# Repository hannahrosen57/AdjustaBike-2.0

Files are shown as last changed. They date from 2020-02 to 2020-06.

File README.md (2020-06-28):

# Design of an Open Source, Low Cost, DIY Cycle Kit
This project was undertaken to investigate the feasibility of an open source, low cost, DIY cycle kit, as my Final Year Project at the University of Bath. As part of the project brief, the kit was designed using off-the-shelf components instead of custom parts wherever possible, to ensure that it can be easily manufactured by the lay person with simple tools and materials. I have succeeded in developing and testing a design for a bicycle frame constructed from handrail clamps, and documented the design so that anyone can continue the work or build a prototype. The design can be customised by the user, and sample geometries were included in the assembly drawings. FEA was used to analyse the bicycle frame, and the design was optimised in response to the results. The final design weighs approximately 8.4kg and costs approximately £276 for the frame components. 

Further work could include building and testing prototypes (which was sadly not possible before the project deadline due to the COVID-19 pandemic), further FEA analysis, espescially focusing on the bottom bracket clamp in dynamic loads, and designing other geometries using the same components such as a cargo bike or recumbent tricycle.

You are free to copy, distribute, and make changes to these designs, under the condition that you give credit to Hannah Rosen, link back here, and publish any new documentation in line with [Open Source Hardware principles](https://www.oshwa.org/definition/). If you build a prototype or further develop the designs, please also consider sending me pictures and telling me how you got on! You can contact me at diycycle57@gmail.com, or open an issue in this repository. Thanks.

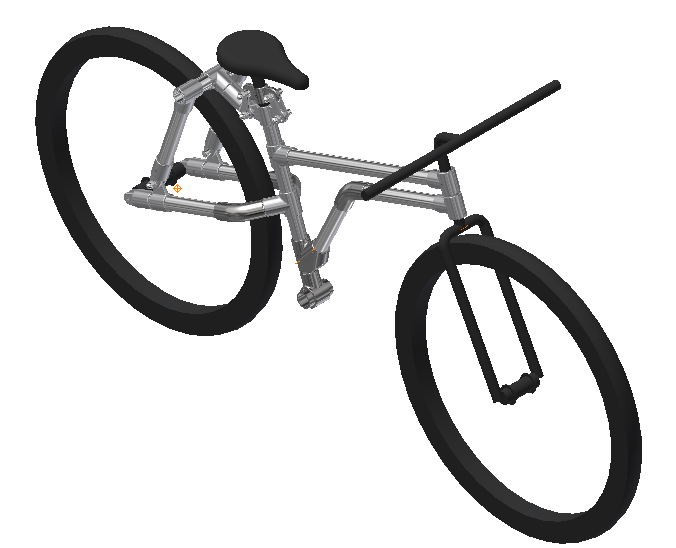
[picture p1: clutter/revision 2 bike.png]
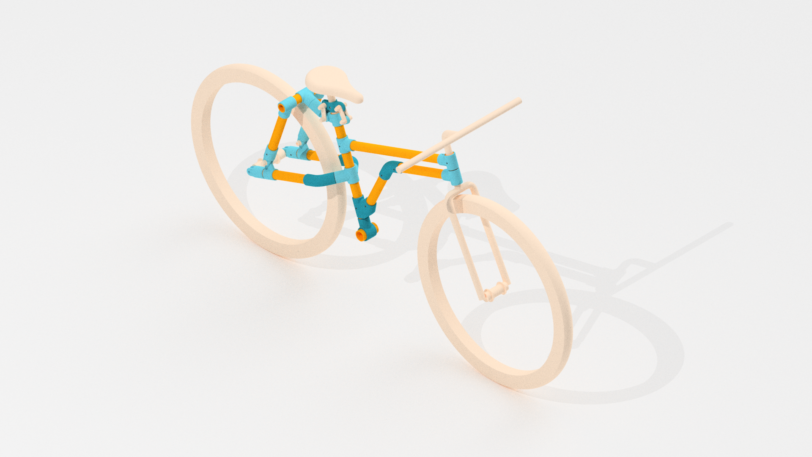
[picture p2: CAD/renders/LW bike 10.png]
|||
|---|---|
|Quick Links:
|- [Poster](https://github.com/hannahrosen57/AdjustaBike-2.0/blob/master/clutter/poster.pdf) (or scroll down↓)|- [Final Presentation](https://github.com/hannahrosen57/AdjustaBike-2.0/blob/master/clutter/Presentation2.pdf)
|- [Preliminary Presentation](https://github.com/hannahrosen57/AdjustaBike-2.0/blob/master/clutter/Presentation1.pdf)|- [Final Report](https://github.com/hannahrosen57/AdjustaBike-2.0/blob/master/report/final%20report.pdf)
|- [STL Files and 3D PDFs of Assemblies](https://github.com/hannahrosen57/AdjustaBike-2.0/tree/master/CAD/exportedCAD)|- [Seatpost Link Part Drawing](https://github.com/hannahrosen57/AdjustaBike-2.0/blob/master/CAD/LINK%205.pdf)
|- [Revision 1 Bike Frame Assembly Drawing](https://github.com/hannahrosen57/AdjustaBike-2.0/blob/master/CAD/bike.pdf)|- [Revision 2 Bike Frame Assembly Drawing](https://github.com/hannahrosen57/AdjustaBike-2.0/blob/master/CAD/LW%20bike%2010.pdf)
|- [Revision 1 Bike Frame Bill of Materials (with weblinks)](https://github.com/hannahrosen57/AdjustaBike-2.0/blob/master/report/bike%20parts%20list.pdf)|- [Revision 2 Bike Frame Bill of Materials (with weblinks)](https://github.com/hannahrosen57/AdjustaBike-2.0/blob/master/report/lw%20parts%20list%20web%20links.pdf)
|- [Kee Klamp Catalogue](https://github.com/hannahrosen57/AdjustaBike-2.0/blob/master/clutter/possible%20components/Kee/Kee_Klamp_components_and_new_slope_fittings.pdf)|- [Kee Lite Catalogue](https://github.com/hannahrosen57/AdjustaBike-2.0/blob/master/clutter/possible%20components/Kee/ks_Kee-Lite_KSys.pdf)

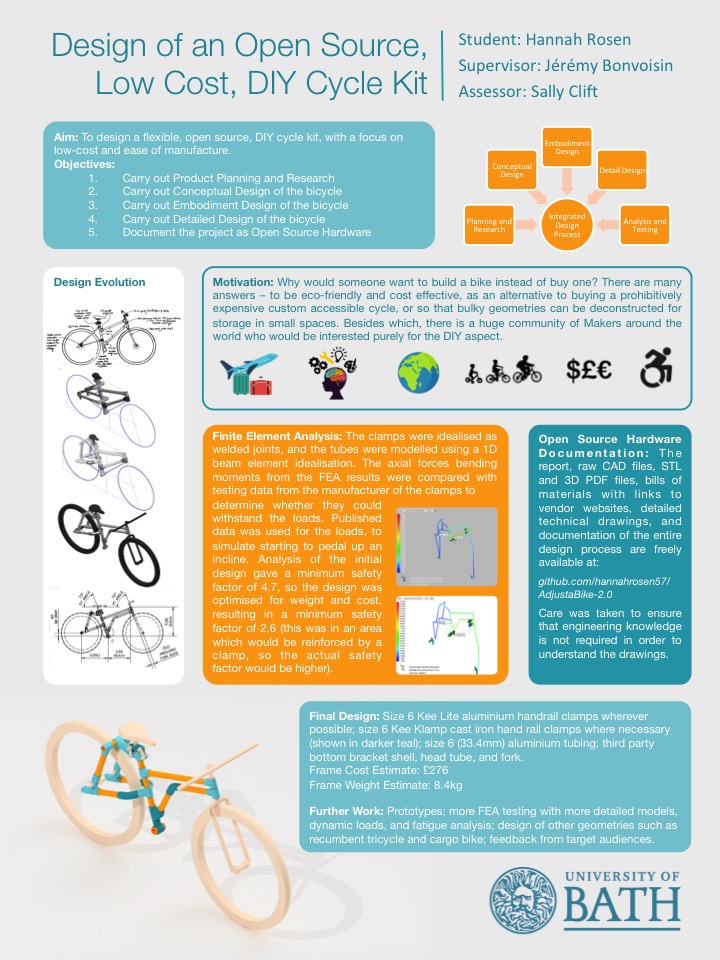
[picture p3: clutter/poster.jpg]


### Notes 22/05/2020:
1. If the reader wishes to build a prototype, and "cheap" is higher up on their list of priorities than "lightweight," some or all of the aluminium clamps could be replaced with cast iron clamps.
    1. The cast iron Kee Klamps use the same part number as the equivalent aluminium Kee Lite clamps, without the "L" prefix. For example, 10-6 is equivalent to L10-6.
    1. Other, cheaper, brands are available, but care should be taken to ensure they are rated to the same loading conditions. A brand comparison and part number conversion table can be found in the report (linked above).
1. Most tube vendors will cut the tubes to length for free (including the ones linked to in the Bills of Materials), which will save time and also shipping costs. However, there is limited data on how far into the clamps the tubes are inserted, so leave a margin for adjustment on the listed tube lengths when cutting. 10 to 20mm should be adequate.
1. Note that a commuter bike geometry is shown as a starting point, but the reader is encouraged to adapt the design to suit their requirements, such as designing a tandem or quad-cycle. Sample geometries for different sizes of the commuter bike geometry (with tube lengths) are shown on the Rev 2 assembly drawing.
    1. An idea for further work is to write a piece of code which would allow users to customise geometry and see a diagram and automatically generated tube lengths without the use of Inventor or any other complex, expensive CAD software - similar to [this webapp](https://www.bikegeocalc.com/) by Anders Torger.
1. Note that this is ready for anyone to take these designs and build a prototype, but more testing needs to be done before it can be certified 100% bombproof. Proceed with caution.
     1. In particular, attention should be paid to the behaviour of the bottom bracket clamp under dynamic loads, and after many load          cycles (including bending moments about all three axes of rotation). Of particular concern is whether the grub screw will loosen over time (it is advised to use a thread locker and check periodically with a torque wrench) and whether the tubes will become damaged over time where the grub screws bite into them. The best way to test this might be to build a bike and ride it around for a while.
     1. If after further testing it is found that the bottom bracket clamp cannot withsand the cyclic loads, Rose+Krieger clamp *Block Form WR 42* (code no: 214200030266) could be used instead of the single socket tee (kee 10-67). This is more suited to dynamic loads, but would add weight and cost.
     1. Alternatively, the geometry could be redesigned so that the down tube is also supporting the bottom bracket,
        1. This could be done using a 90 degree side outlet tee (kee 21-7) and an elbow (such as kee 55), similar to the chainstays in the current design. 
        1. The variable side-outlet tee (kee 19) is another option which should be investigated, but note that the testing data for the aluminium Kee Lite clamps states that type L19 is "not suitable to absorb bending load, bending moments are not allowed". The cast iron Kee Klamp testing data however rates type 19 to 1.25kN of bending load resistance. 
        1. More information on bending moment resistance should be sought from Kee Systems if type L19 is used. Testing should also be done to determine whether the asymmetry and short gripping of types 19 and L19 would cause problems when supporting the diagonal loads on the bottom bracket.
        1. The downtube would then need to be connected to the head tube with either an angle tee (such as kee L29-7) or an elbow (such as kee 55) and a single socket tee (such as kee L10-7).
    1. Both of these options would mean that the seat tube needs to be the same size as the bottom bracket. Unless a bottom bracket shell can be found or made (simple enough if one has access to a lathe, or is willing to contract a third party to machine it for them) which fits a Size 6 Kee Klamp (possibly with the use of a shim), this would mean that size 7 tubing would need to be used for most of the frame, as in Revision 1 of the current design (assembly drawing and BOM linked above). This would add cost and weight, but is still feasible.
1. The only custom part (apart from cutting tubes to length) is the seat post link. It can be made easily from flat bar with just a hacksaw, a drill, and a file. The part drawing is linked above and should be easy to understand even for people with no engineering knowledge. 
    1. The clamps are all standard; simplified CAD models were created from the dimensions given by the manufacturer in order to model the assembly. Part numbers and vendor links are given in the bills of materials. The catalogues are linked above.
1. If the prototype is built and there is a problem with rattling, simple rubber washers/gaskets should be used in the swivel sockets. 
    1. This could also help if the surface of the swivel sockets used as "drop outs" (technically, frame ends) does not have a good enough surface finish. Just pop a rubber washer between the frame end and the axle nut.
    1. The number of washers used as spacers depends on the thickness of the washers, especially in the seat post clamp/seatstay assembly. Adjust as appropriate.
1. If there is a problem with the seat post rattling, use a spacer to fill the gap between the seat post and the seat tube. PVC pipe, shim stock, or folded aluminium foil could be used. To stop it from slipping down the seat tube, drill a horizontal hole through the bottom of the seatpost below the spacer (through both sides of the tube), and insert a length of threaded bar. Secure it in place with two nuts on the threaded bar inside the seat post, tightened to brace outwards against the ID of the seatpost. Make sure it protrudes far enough to hold the spacer in place, but not far enough to scratch against the ID of the seat tube.
1. A placeholder for the drivetrain was not modelled, because the user can choose to use any number of options - fixed gear, hub gears, cassette gears, or even a belt drive. In the case of fixed gears, chain tensioning would be facilitated by adjusting the sliding clamps. However, regardless of one's preferred drivetrain, it would be advisable to model a simple placeholder and check there is enough clearance, making small adjustments to tube lengths if necessary, before ordering parts.

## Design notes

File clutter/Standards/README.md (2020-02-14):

The standards are as follows:

code              | title
------------------|---------------------
ISO 4210          | Cycles — Safety requirements for bicycles
BS EN 14764       | City and trekking bicycles — Safety requirements and test methods *(note: this is outdated and was replaced by ISO 4210, but still helpful)*
ISO 8098          | Cycles — Safety requirements for bicycles for young children
ISO 9633          | Cycle chains — Characteristics and test methods

The former is the most relevant. I couldn't find the requirements for some of the tests, so I went looking and found the numbers I wanted in the second and third standard, but then realised they were hiding (in plain sight) in part 2 of ISO 4210 all along. I'll leave them here anyway since I already went and found them. The fourth was refenced by ISO 4210.

For reference, these are the parts of ISO 4210:

- Part 1: Terms and definitions
- Part 2: Requirements for city and trekking, young adult, mountain and racing bicycles
- Part 3: Common test methods
- Part 4: Braking test methods
- Part 5: Steering test methods
- Part 6: Frame and fork test methods
- Part 7: Wheels and rim test methods
- Part 8: Pedals and drive system test methods
- Part 9: Saddles and seat-post test methods

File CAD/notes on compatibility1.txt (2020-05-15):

NOTES ON COMPATIBILITY:
Components below can be taken from a cheap second-hand donor bike or purchased seperately. Use shims if necessary, leaving a gap for the clamp's grub screw.
Bottom Bracket: 73mm English Thread
Fork: 1" ISO standard fork steerer. Ø41mm HT for a 11/8" fork also available, but needs size 7 clamps.
Seatpost: 26-27.5mm OD for Size 5 clamp (M51-5, shown here) or 21-22.5mm OD for Size 4 clamp (M50-4).
Wheels: 29" rims with 44mm tyres and 135mm rear hub spacing shown for reference. For bigger wheels (or longer wheelbase) - use longer CS, SS, CSS, and/or SSS tubes. For smaller wheels - use shorter CS and SS tubes, and/or longer axle spacers (CSS shown at minimum).
Brakes: Front - any compatible brake. Rear - use coaster brake or create attachment point for callipers with additional clamps.
Gears: Single speed or hub gears are the simplest butnot the only options. Consider the weight of the entire bike when selecting gear ratio(s).

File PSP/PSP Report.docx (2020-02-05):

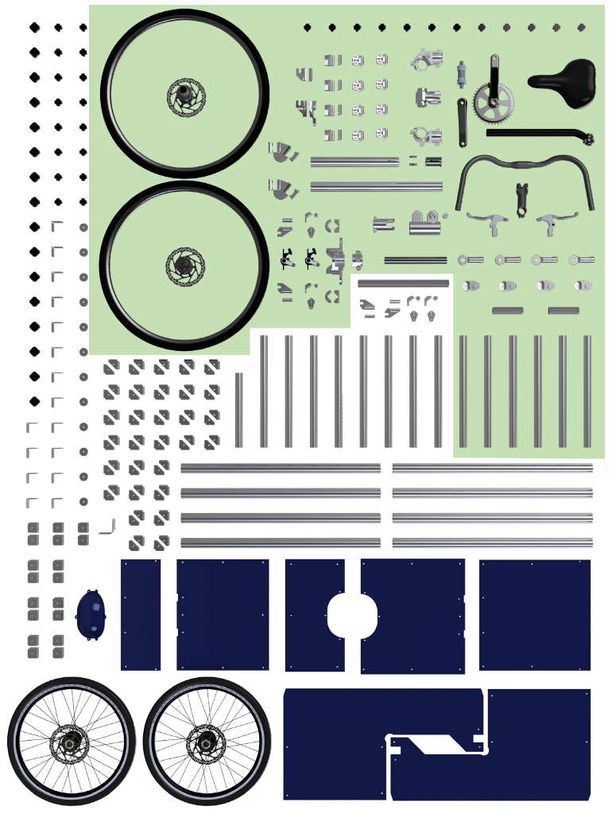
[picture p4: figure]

design of a DIY Bicycle Kit Project Scoping and Planning Report | SUMMARY [Draw your reader in with an engaging abstract. It is typically a short summary of the document. When you’re ready to add your content, just click here and start typing.] Hannah Rosen Supervisor: Jeremy Bonvoisin Assessor: ………………………….

# Background

This project is building on the work which was carried out in the Adjustabike project in 2019 by a previous student, which was the latest iteration of a series of prototypes developed to explore the concept of an open source build your own bicycle kit. The benefits to a bicycle kit over a traditional frame are that the same components can be re-used when the frame needs to accommodate a different rider, or to construct an entirely different geometry which may not be readily available (which is especially useful if the geometry is only needed temporarily), and that bulky geometries can be deconstructed when not in use to save storage space, and the components repurposed.

The Adjustabike frame consists of aluminium profiles from a factory equipment construction system such as item, fastened together by flexible joints through non-destructive clamping mechanisms. Two geometries were modelled: a standard bicycle which was adjustable for rider height, and a cargo tricycle. In theory many other geometries could be assembled from the same components, but this was left for future development, as was in-depth testing.

Although the Adjustabike provided a thorough proof of concept, it made several compromises on the use of readily available standard parts. The complex custom components which were developed could not be manufactured even with sophisticated CNC machines at one’s disposal, let alone by a typical layperson. It was also fairly limited in its documentation, which meant that adaptation by a third party might prove difficult, and that the open source aspect of the concept was not fulfilled to the extent intended. The aim of this project is to readdress the concept with a view to making the kit as open source and accessible to laypeople as possible. To achieve this, the ratio of off-the-shelf to custom components will be increased as much as possible without compromising the functionality and flexibility of the previous design. Ideally, the kit will be comprised of exclusively standard components. An effort will also be made to document the project according to Open Source Hardware best practices.

# Aims and Objectives

The aim of this project is to design a kit with which a lay-person can easily and non-destructively assemble a bicycle with a geometry of their choice, and to ensure that the ratio of off-the-shelf components to custom components is as high as possible, in the interest of maximising the accessibility of the kit to the lay-person. This aim will be accomplished through the following objectives:

1. Investigate available off-the-shelf technologies and use a set of criteria to recommend which would be most suitable for using in the kit.
2. Develop a simplified modelling method to test the combinations of the recommended elements, and use it to:
  a. Demonstrate the feasibility of creating different geometries, and
  b. Make a recommendation on which lengths, angles, and quantities of components which should be included in the ‘starter’ kit (with the understanding that supplementary components may be used for specialised geometries).
3. Source materials and build a physical (preferably full scale) prototype of one or more geometries.
4. Establish open source documentation, both to allow lay people to use the kit and to allow future development of the project.

# Work Plan (Programme and Methodology)

The project will be divided into four Work Packages (WPs), corresponding to the four objectives. WPs 1, 2, and 3 will be carried out in series and are dependent on each other, so contingency planning will be carried out such that the project content will not be compromised due to unexpected results. WP4 will mostly be completed throughout the project in parallel to the other WPs, bookended with some preparation at the start and finalisation at the end of the project.

## WP1 Study of Available Technologies

An investigation will be conducted into available off-the-shelf products which could be used to create the bicycle kit. It should be noted it will most likely not be immediately obvious where to look, because the products of interest will likely be intended for completely different purposes, such as scaffolding. A set of criteria should be developed, such as a high strength to weight ratio, non-destructive joint locking mechanisms which do not require extensive tooling, and low cost. Each of the available products will be rated based on these criteria, and a recommendation will be made on which to take forward.

## WP2 Combinatorial Testing

Using a CAD package such as Autodesk Inventor, simplified models of a preliminary set of components from the recommended technology will created based on the characteristics of the existing products obtained from product specifications. The components will be based on the existing products, but may be modified in ways that can easily be achieved with simple tools, such as cutting profiles to length. Different geometries will then be modelled using assemblies of different combinations of these components. The parameters of the components (such as lengths of tubes or angles of joints) may then be adjusted as needed (again, provided the equivalent modifications of the physical components are possible with simple tools), and the next iteration of geometry designs can then be developed using the new set of components. This can be repeated as many times as needed.

The resulting geometries will be analysed to ensure they are fit for purpose, including force calculations and perhaps some rudimentary FEM analysis, as well as safety, usability, and manufacturing and assembly considerations. Based on these geometries, a ‘starter kit’ of components will be recommended, with the understanding that supplementary components may be used for specialised geometries. The characteristics and quantities of each component in the kit will be specified.

## WP3 Physical Prototyping

If time allows, simplified small-scale prototypes of the recommended kit components will be created using additive manufacture so as to demonstrate the proof of concept for a few of the geometries developed in the previous WP, as it is unlikely that it will be possible to find the time or material resources to create full-scale prototypes of all of the different geometries.

However, the priority during this WP is to build a (preferably full scale) physical prototype of at least one of the geometries that were developed, ensuring that as many as possible of the components used are the exact components recommended in the kit. The purpose of this is two-fold: firstly, to demonstrate the soundness of the design of the components and the geometry, and secondly, to demonstrate the feasibility of sourcing the components and assembling the design using only the resources available to a typical lay-person.

It should be noted however, that difficulty is anticipated in the sourcing of certain components – namely, the interfaces between standard bicycle components such as the bottom bracket with the repurposed off-the-shelf components – due to tolerance discrepancies and other obstacles. The scope of this project is to demonstrate the feasibility of the overall concept, not to develop precise designs for any custom parts which might be necessary (although the aim is of course to avoid custom parts where possible). As such, rapid prototyping using extruded ABS additive manufacture (or other cost- and time-efficient methods) may be implemented where necessary to manufacture ‘placeholder’ components which may be developed further at a later stage, so that the larger assembly may be prototyped more effectively.

If time permits and the prototype is suitable, simple strain gauges may be used to test if the stresses in the components are as predicted.

## WP4 Open Source Documentation

The aim of documenting open source hardware is to ensure that other people have enough information to make, study, develop, and distribute the product. To this end, GitHub will be used throughout the project to keep a log in which to record decisions, test results, and design iterations. Whether this will be carried out using GitHub’s inbuilt Markdown capability or by simply uploading and committing a new version of a Microsoft Word document periodically will be determined based on which method is more efficient overall, taking into account the fact that the project log will serve two purposes: the report for the University project and the open source documentation.

In addition to the project log, the version control functionality of GitHub will be used to track changes in any CAD files by uploading and committing an editable format of the designs as they are being developed. Final designs will be made available on GitHub both in a raw, editable format such as .ipt, .iam, or .dwg files and a flattened, easily viewable format such as .stl or .pdf files. A set of instructions for the lay-person on the use of the kit will also be written, based on best practice.

This WP will be mostly carried out parallel to the other WPs, including tracking progress, recording test results, and documenting the prototype assembly photographically to provide images for the instruction booklet. However, some time will be needed at the beginning of the project to setup the GitHub repository, research best practice for documentation, and learn the Markdown formatting language. Some time will also be needed at the end of the project to compile the documentation and finalise any front-facing formatting, explanations, and graphics.

## Contingency Planning

Lorem ipsum

# Predicted Timescale

Note that these dates are preliminary and will likely change as the project progresses.

start date: | task:
27/11/2019 | Assessment 1: Project Scoping and Planning
| WP1
27/11/2019 | Research the different types of bike components
02/12/2019 | Create a set of weighted criteria for choosing the base technology for the frame kit
07/12/2019 | Look for available technologies online
26/01/2020 | Look for available technologies in brick and mortar shops
29/01/2020 | Score each technology based on the weighted criteria chosen earlier
30/01/2020 | Choose products that work well together from the top scoring options
| WP2
03/02/2020 | Create simplified CAD models of recommended components
03/02/2020 | Develop and refine concepts for one or two initial geometries
06/02/2020 | Put together a kit with preliminary angles, lengths, and quantities of components based on concepts
07/02/2020 | Create initial and alternative geometries from the kit and assess if they are fit for purpose
10/02/2020 | Adjust lengths, angles, and quantities of components in the kit
12/02/2020 | Repeat until geometries are optimised
19/02/2020 | Analyse final geometries eg. Force calculations
26/02/2020 | Decide which components should be in the starter kit and which should be add-ons
| WP3
15/02/2020 | Source materials eg tubes
27/02/2020 | Cut profiles to length etc.
27/02/2020 | Fabricate any custom parts needed
15/02/2020 | Source bicycle components eg gears
03/03/2020 | Assessment 2: Preliminary Project Presentations
05/03/2020 | Assemble the bicycle
12/03/2019 | Conduct testing, ie strain gauges, feedback from target market
| WP4
27/11/2019 | Set up GitHub repository
| Learn MarkDown syntax
| Track progress throughout project
| Write instructions on the use of the kit, based on best practice
| Compile and finalise documantation
| Report
28/03/2020 | Compile design logs, test reports, etc.
| Reflect on how the project could be developed in the future
| Plan structure of report
| List and gather all figures needed
| Create report skeleton
| Draft each section
| Revise drafts
| Work on formatting and graphics
| Create bibliography from references (which should be collected throughout)
29/04/2020 | Assessment 3: Final Project Report
11/05/2020 | Assessment 5: Viva, Final Presentation and Poster
25/05/2020 | Exhibition, External Viva

## Gantt Chart

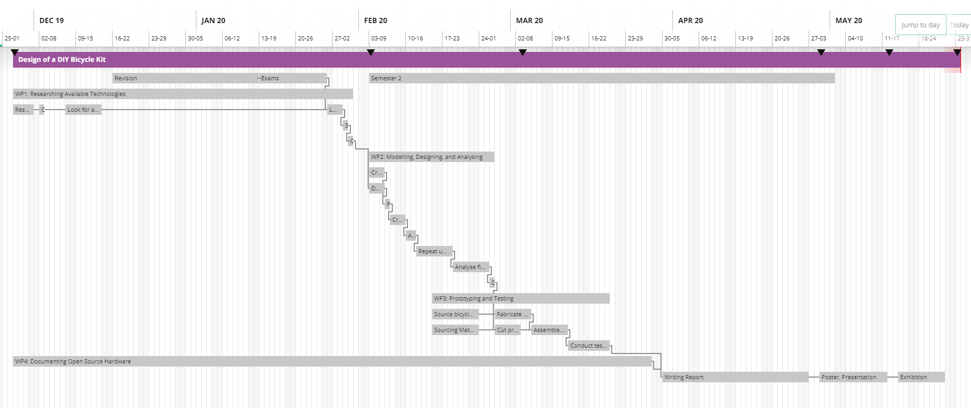
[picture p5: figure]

# References

http://vis.berkeley.edu/papers/assySiggraph/assembly.pdf

https://www.icebike.org/build-your-own-bike/

https://www.bikeradar.com/advice/buyers-guides/the-complete-guide-to-bottom-bracket-standards/

https://ukcyclerules.wordpress.com/2011/05/04/the-rules-of-bike-brakes/

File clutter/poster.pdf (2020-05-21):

Design of an Open Source,

# Low Cost, DIY Cycle Kit

## Student: Hannah Rosen Supervisor: Jérémy Bonvoisin Assessor: Sally Clift

Integrated
Design
Process

Planning and
Research

Conceptual
Design

Embodiment
Design

Detail Design

Analysis and
Testing

Aim: To design a flexible, open source, DIY cycle kit, with a focus on low-cost and ease of manufacture.
Objectives:
1. Carry out Product Planning and Research
2. Carry out Conceptual Design of the bicycle
3. Carry out Embodiment Design of the bicycle
4. Carry out Detailed Design of the bicycle
5. Document the project as Open Source Hardware
Design Evolution | Motivation: Why would someone want to build a bike instead of buy one? There are many answers – to be eco-friendly and cost effective, as an alternative to buying a prohibitively expensive custom accessible cycle, or so that bulky geometries can be deconstructed for storage in small spaces. Besides which, there is a huge community of Makers around the world who would be interested purely for the DIY aspect.

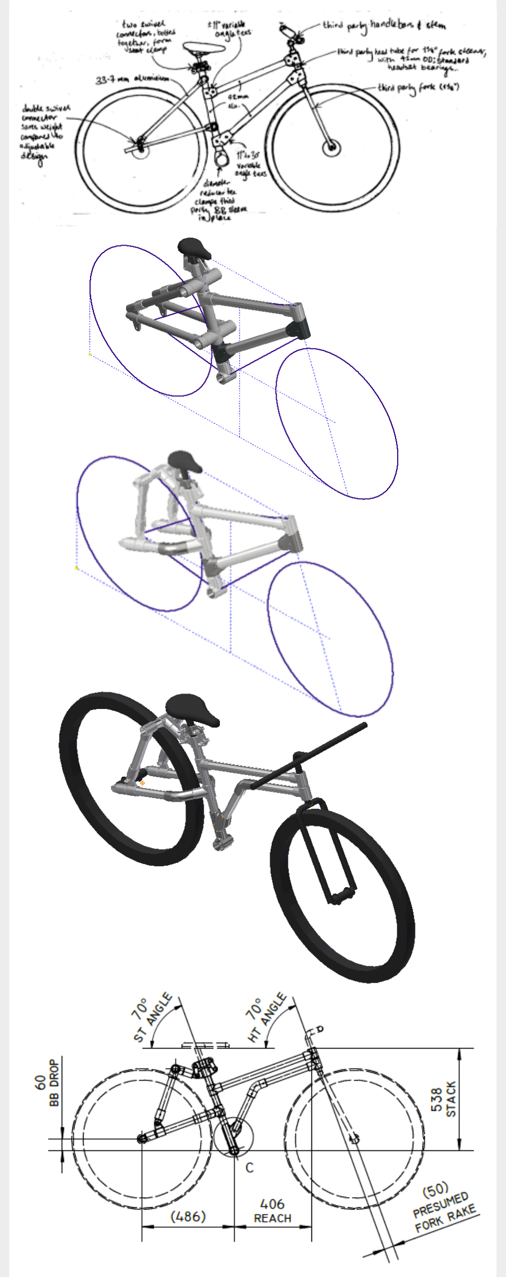
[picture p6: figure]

Open Source Hardware
Documentation: T h e
report, raw CAD files, STL and 3D PDF files, bills of materials with links to
vendor websites, detailed
technical drawings, and
documentation of the entire design process are freely
available at:
github.com/hannahrosen57/
AdjustaBike-2.0
Care was taken to ensure
that engineering knowledge is not required in order to understand the drawings.

Finite Element Analysis: The clamps were idealised as welded joints, and the tubes were modelled using a 1D beam element idealisation. The axial forces bending moments from the FEA results were compared with testing data from the manufacturer of the clamps to determine whether they could
withstand the loads. Published
data was used for the loads, to
simulate starting to pedal up an incline. Analysis of the initial design gave a minimum safety factor of 4.7, so the design was optimised for weight and cost, resulting in a minimum safety factor of 2.6 (this was in an area which would be reinforced by a clamp, so the actual safety factor would be higher).

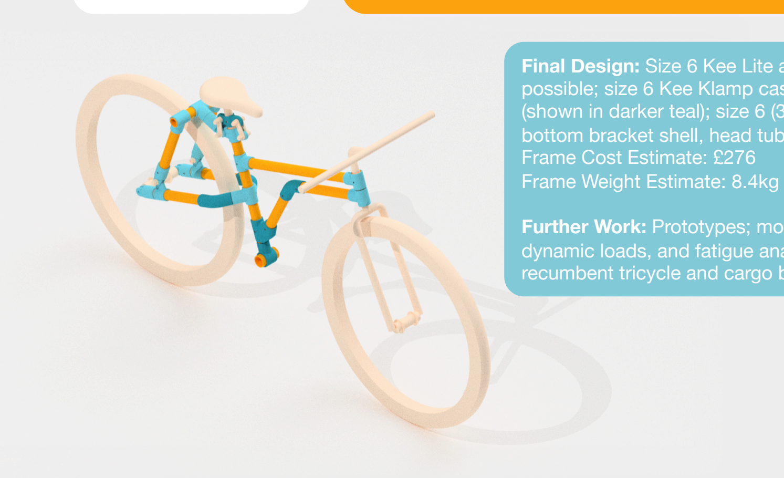
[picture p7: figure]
Frame Cost Estimate: £276 Frame Weight Estimate: 8.4kg

Final Design: Size 6 Kee Lite aluminium handrail clamps wherever possible; size 6 Kee Klamp cast iron hand rail clamps where necessary (shown in darker teal); size 6 (33.4mm) aluminium tubing; third party bottom bracket shell, head tube, and fork.

Further Work: Prototypes; more FEA testing with more detailed models, dynamic loads, and fatigue analysis; design of other geometries such as recumbent tricycle and cargo bike; feedback from target audiences.

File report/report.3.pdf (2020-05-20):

Concept Development
Development sketches for individual features can be seen in Figure 39 through Figure 42. Concept development sketches can be seen in Figure 43 and Figure 44. The main difference between Kee Klamp 1.0 and Kee Klamp 2.0 is that the latter uses a mixture of steel and aluminium tubes, and of cast iron and cast aluminium clamps, in order to combine the strengths and avoid the weaknesses of the Kee Lite and Kee Klamp concepts. Thereafter, the concept is developed with a view to find a viable solution which is fully adjustable. This was accomplished in concept 2.4, and the design was then streamlined to form concept 2.5. Note in particular the evolution of the geometry and the head tube/headset bearings as the concepts are developed.

Concept 2.4 and 2.5 were both selected as final concepts, as it was decided that the adjustability added so much complexity, weight, and cost to the design that it was worth developing one “Design for Adjustability” concept and one “Design for Performance” concept. These two concepts were evaluated against the same criteria as the initial concepts, and outperformed them all, as expected.

## Embodiment Design

Final Concepts/Initial Layouts

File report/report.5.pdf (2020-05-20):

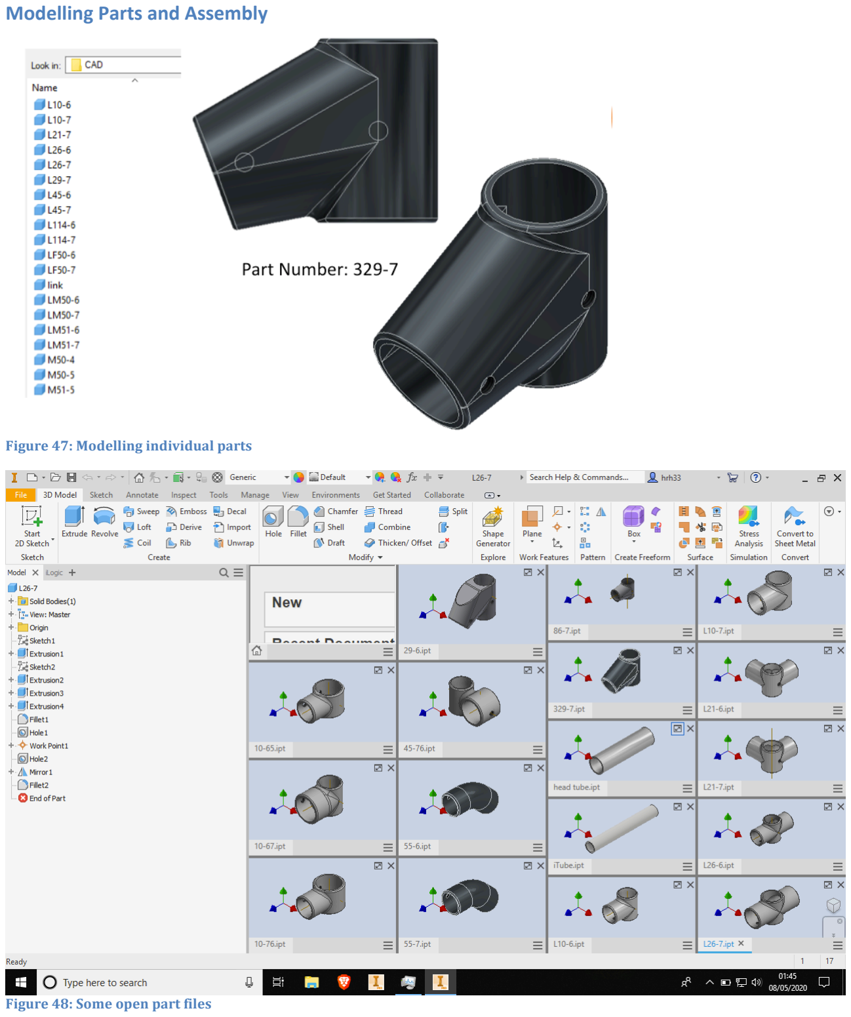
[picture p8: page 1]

Modelling Parts and Assembly

Figure 47: Modelling individual parts

Figure 48: Some open part files

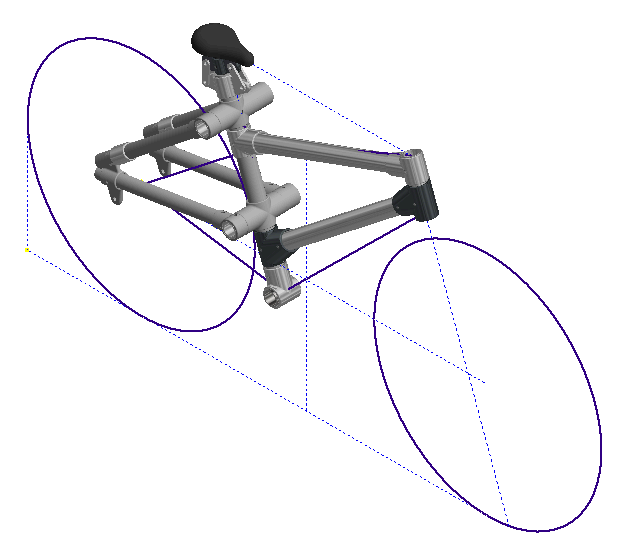
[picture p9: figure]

Figure 49: modelling assembly

## Detail Design

Geometry Adjustment Tuning
When the design was initially modelled up, it became clear that the chainstay spacers and seatstay spacers would get in the way of the user’s legs and make pedalling impossible. The bike was redesigned to be more ergonomic.

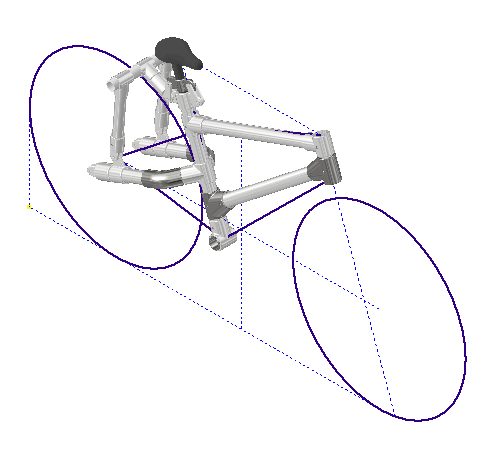
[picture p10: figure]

Figure 50: New, more ergonomic rear triangle design
iLogic was also used to automate the tubes to adjust their length according to a stack and reach value that was entered as a parameter. This was used to create a table with sample geometries and tube lengths for different riders on the assembly drawing (see Appendix VI: Drawings and BOMS).

Finite Element Analysis
FEA analysis was used to analyse, validate, and optimise the design. This is an entire field of study but I am short on time so I will try to illustrate the process I took as quickly as possible. Please note I am running out of time to write up all the analysis I did!

simplifying geometry:

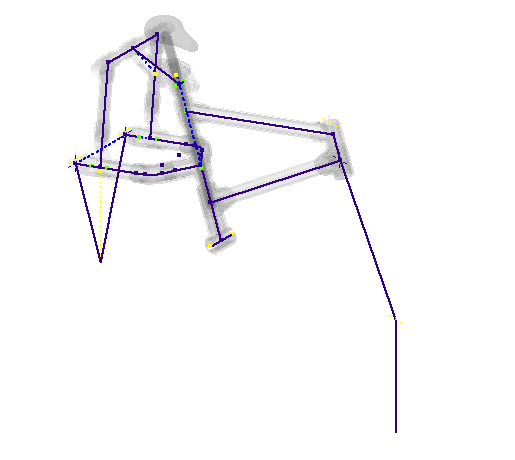
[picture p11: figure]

geometry was represented with sketch lines. bike was modelled as if welded, neglecting the clamps, as this was the ‘worst case scenario’ since the clamps have a higher bending moment resistance than the tubes. The forces and bending moments were calculated as well as the stresses and compared with clamp test data from the manufacturer.
Defining Parameters:
- mesh
- element types and cross sections
- beam elements were used exclusively.
- ideally these would only be used when the cross section is less that 1/10 of the length. This condition was true for most of the tubes, but not the bottom bracket
- this idealisation should still be accurate enough to give a good idea
- a topic of further work could be analysing the product in more detail
- initially different cross sections were used according to the different tube cross sections, but it didn’t mesh correctly when using the end release function. So, the cross section was first set as the size 6 tube, and the results for the rear triangle were evaluated. Then the cross section was set to that of size 7 tube and the rest of the results were evaluated.
- element size
- a mesh convergence study was performed and 5mm elements were found to be the best balance between speed and accuracy
- end-release

- end release was used at the rear frame ends and the swivels in the rear triangle to simulate realistic constraints without over complicating the mesh
- constraints
- the wheels were modelled as lines to allow the bike to tilt with the bending moment on the handlebars to a certain extent, to reduce unrealistic stresses
- other than this, the bike was simply supported
- loads
- loads were taken from the 1986 paper (7) from the ‘starting tilted’ load case
- as the handlebars and pedals were not modelled, unsymmetrical loads were modelled with distributed moments on the BB and head tube.

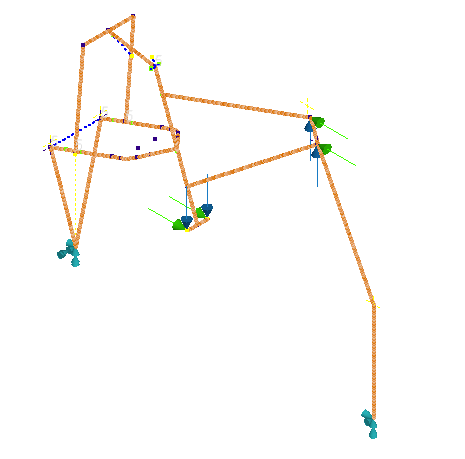
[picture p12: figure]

Figure 51: showing the mesh, constraints, and loads

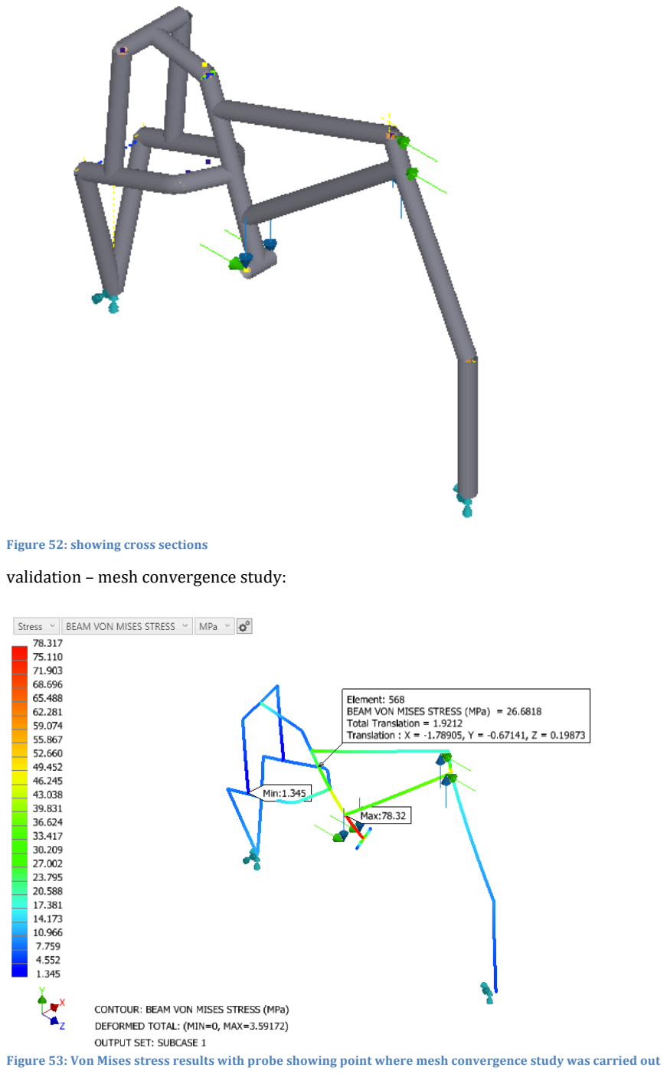
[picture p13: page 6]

Figure 52: showing cross sections
validation – mesh convergence study:

Figure 53: Von Mises stress results with probe showing point where mesh convergence study was carried out

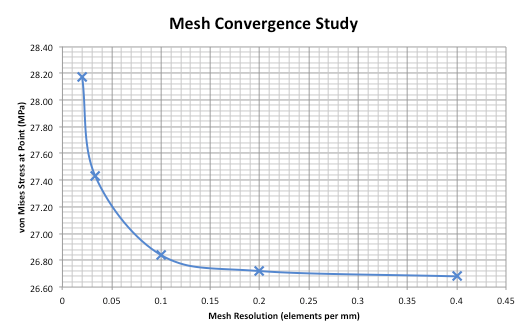
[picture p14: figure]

Figure 54: Mesh convergence study
Results
The results of the analysis were encouraging. The maximum von mises stress was well within the safe limit of the tubes. The minimum safety factor was 4.71, and that may have been caused by a singularity (see Figure 57: closeup safety factor results plot screenshot). The axial forces and bending moments were also well within the safe limit for the clamps (see Figure 59, Figure 60, Figure 62, and Appendix IV: Kee Systems Testing Data; note that units in screenshots are in Nmm and units in testing data are in kNm; also note safety factor included in testing data). In view of this, the design was optimised to be lighter and cheaper (see Optimising Design and Appendix VI: Drawings and BOMS) and the FEA analysis was carried out again. The results again confirmed that the loads and stresses were within safe limits (see Figure 63 through Figure 67). The minimum safety factor was the 2.6, which is not ideal, but a) it was near a likely singularity and b) it would be reinforced by the clamp anyway.

Confidence in the Results
I have a reasonable degree of confidence in the results considering the time limits, enough to say that this is feasible and safe to build a prototype. However, it is definitely not a polished, foolproof consumer product. It needs more testing. This model made strategic simplifications due to time constraints and lack of data on clamp geometries, but it would be good to model and analyse the clamps. It would also be good to do some fatigue testing, especially for the bottom bracket clamp. It can withstand a static force but further testing is required for dynamic, cyclic loads, and fatigue analysis, and perhaps some modal analysis for vibration. It would also be good to validate the analysis with experimental data. If the BB needs to be reinforced, R&K have a clamp that might work, but it is heavy – 1.5kg.

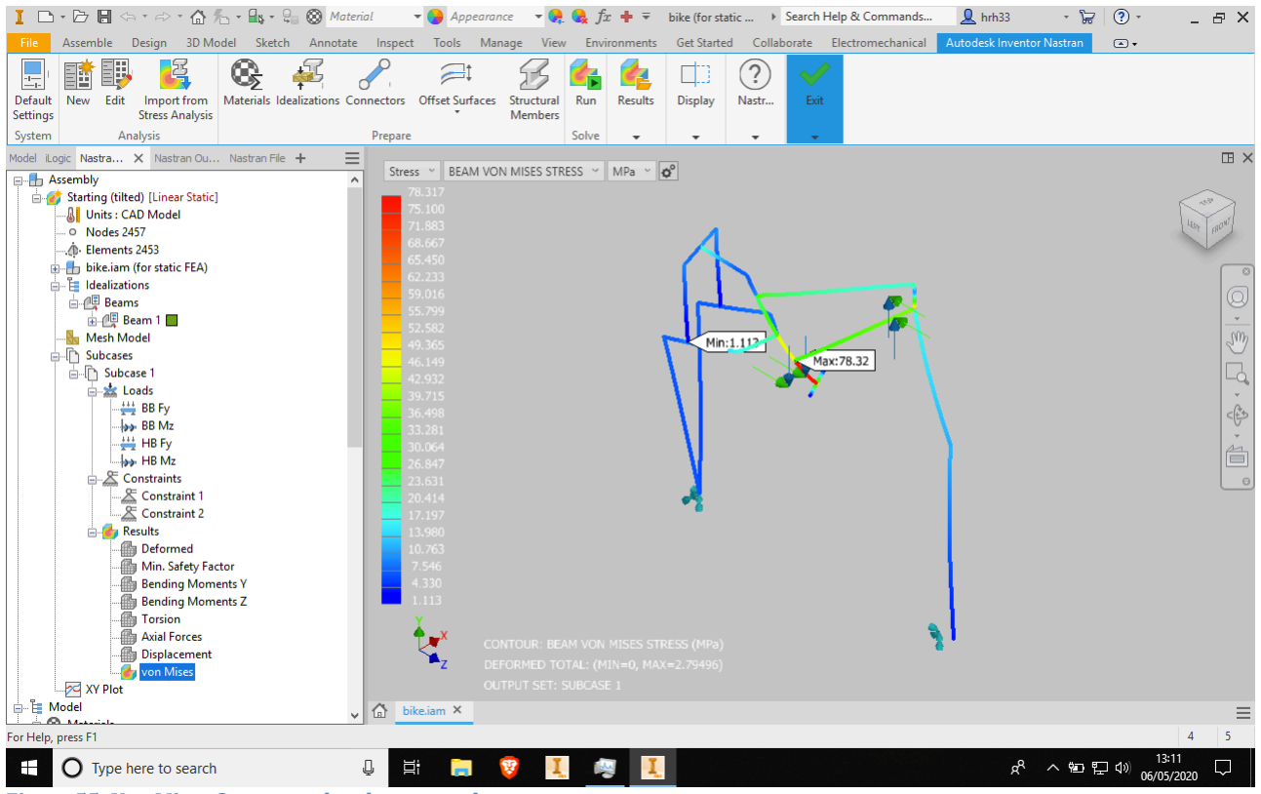
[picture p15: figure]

Figure 55: Von Mises Stress results plot screenshot

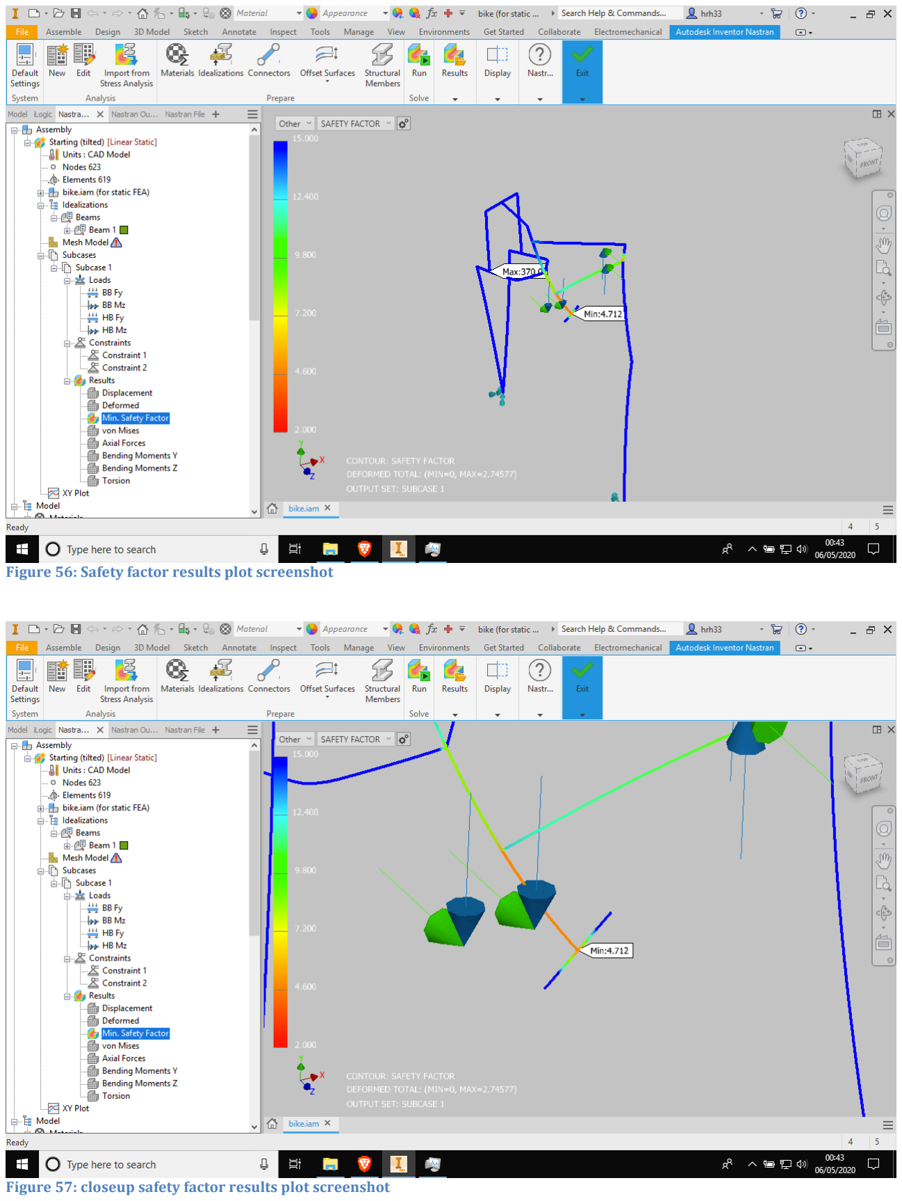
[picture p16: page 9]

Figure 56: Safety factor results plot screenshot

Figure 57: closeup safety factor results plot screenshot

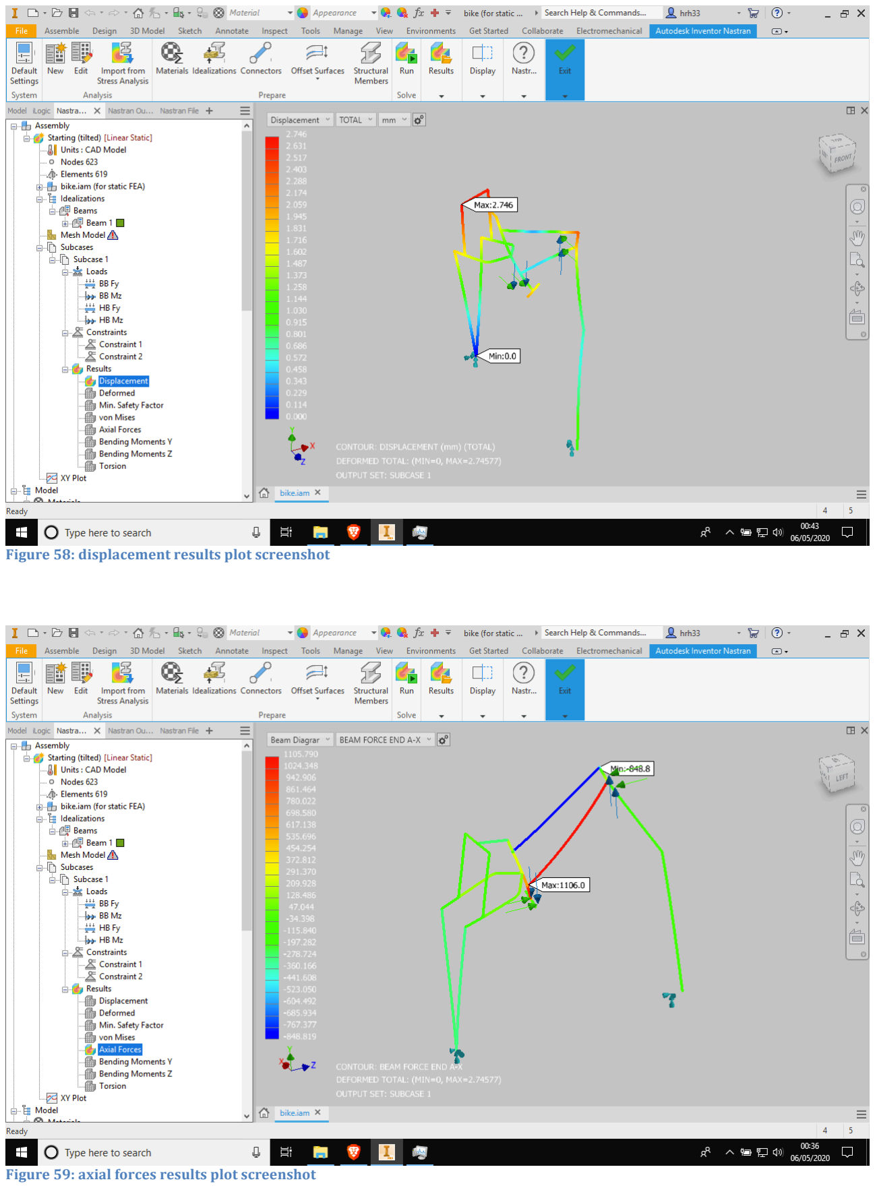
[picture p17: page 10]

Figure 58: displacement results plot screenshot

Figure 59: axial forces results plot screenshot

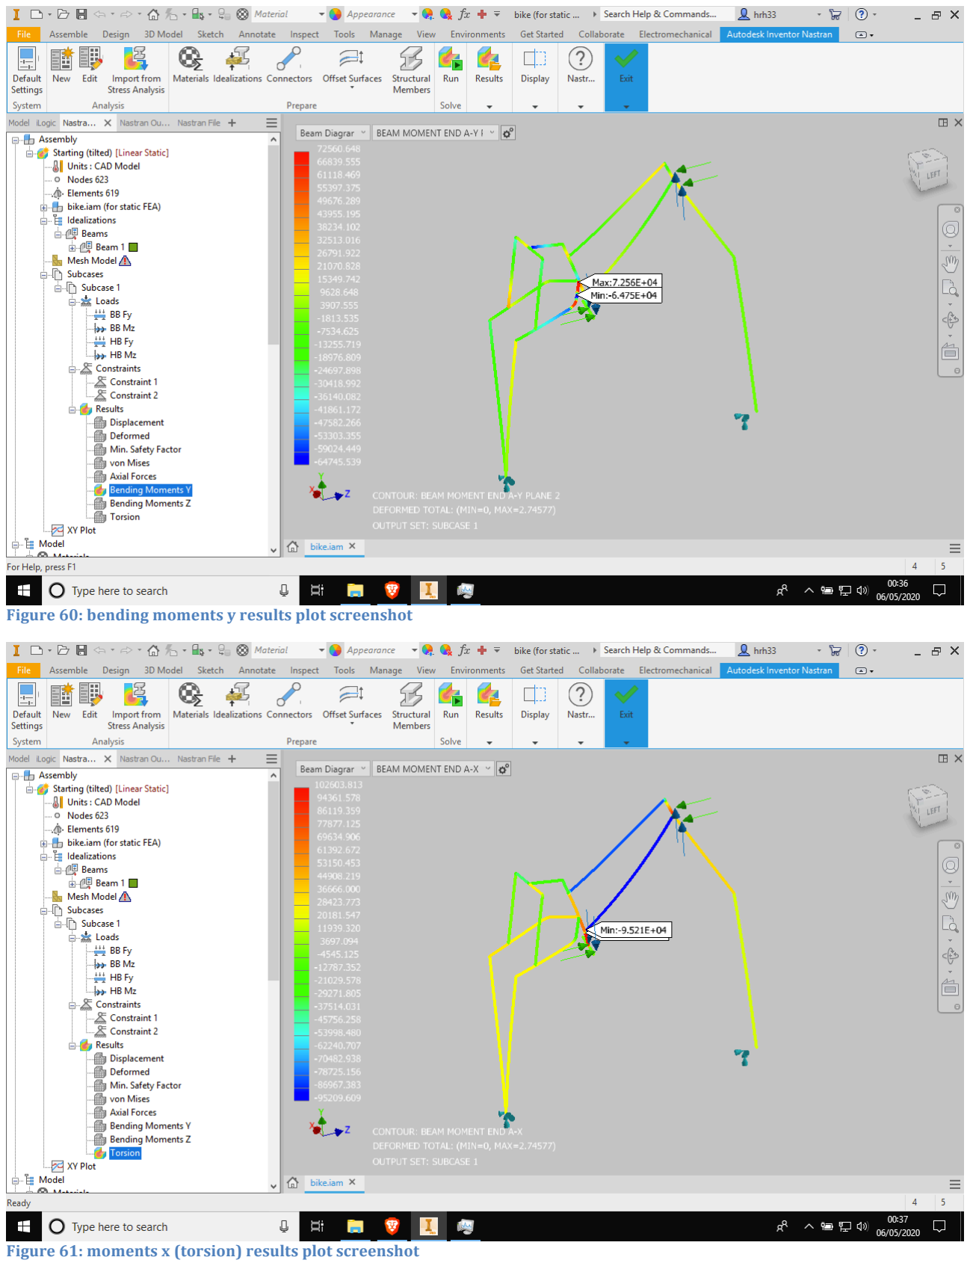
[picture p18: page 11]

Figure 60: bending moments y results plot screenshot

Figure 61: moments x (torsion) results plot screenshot

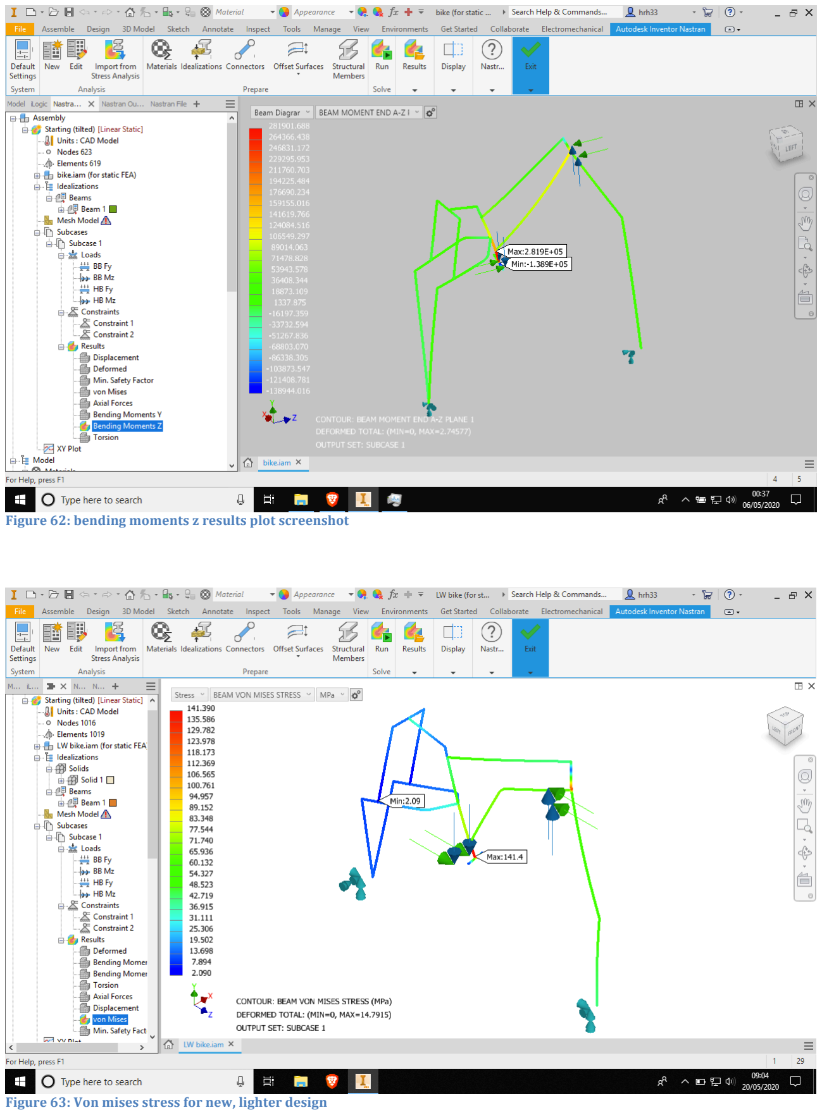
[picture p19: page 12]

Figure 62: bending moments z results plot screenshot

Figure 63: Von mises stress for new, lighter design

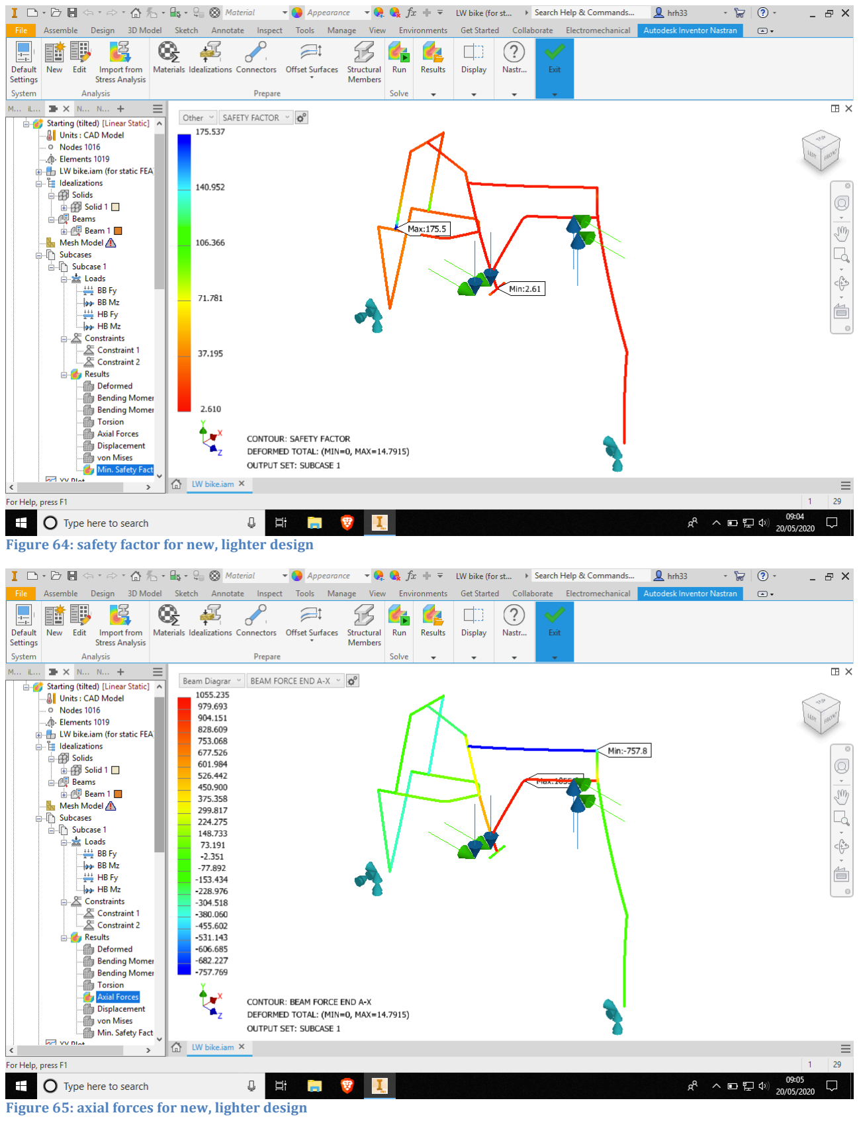
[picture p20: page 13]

Figure 64: safety factor for new, lighter design

Figure 65: axial forces for new, lighter design

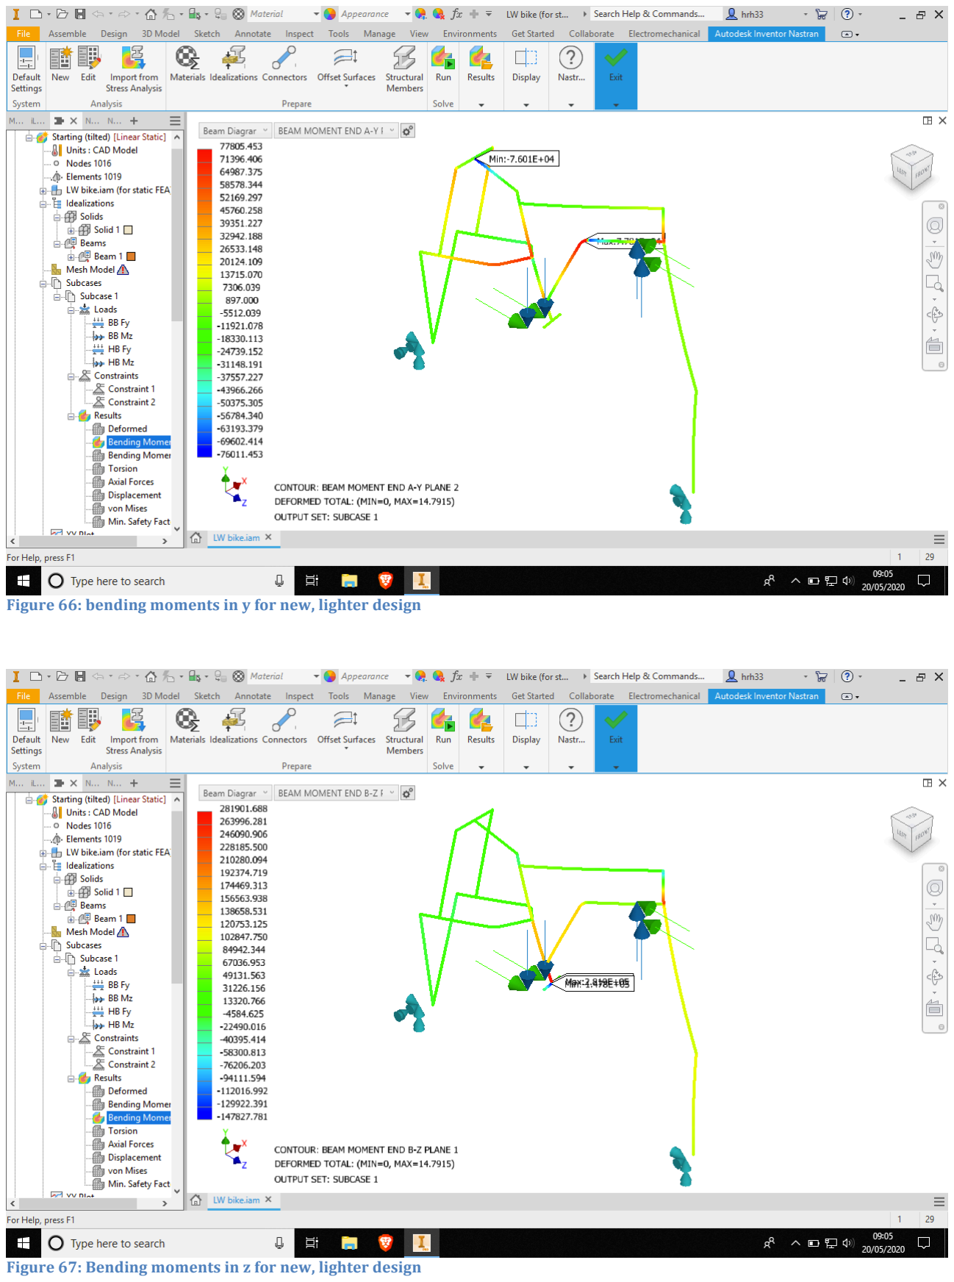
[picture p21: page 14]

Figure 66: bending moments in y for new, lighter design

Figure 67: Bending moments in z for new, lighter design

Optimising Design
When the FEA analysis showed that the design had large safety factors, I redesigned the frame to use all size 6 tube and aluminium clamps when possible. This required some changes to the geometry. Refer to the assembly drawings in the appendix. This design update significantly reduced the weight and cost. The new design was analysed with FEA again and showed that it should be safe, but further testing is needed.

Final Design
The final design is documented in the assembly drawing and BOM in the appendix. It weights approximately 8.4kg and costs approximately £276 (frame only). It uses mostly aluminium size 6 clamps and aluminium size 6 tubing. The weight and cost were calculated using data from the manufacturers and Autodesk iLogic scripts, so is fairly accurate – apart from shipping costs. There is detailed information on the assembly drawings about finding compatible components such as wheels and a third party fork. A cargo rack could easily be added onto the back with a couple extra clamps.

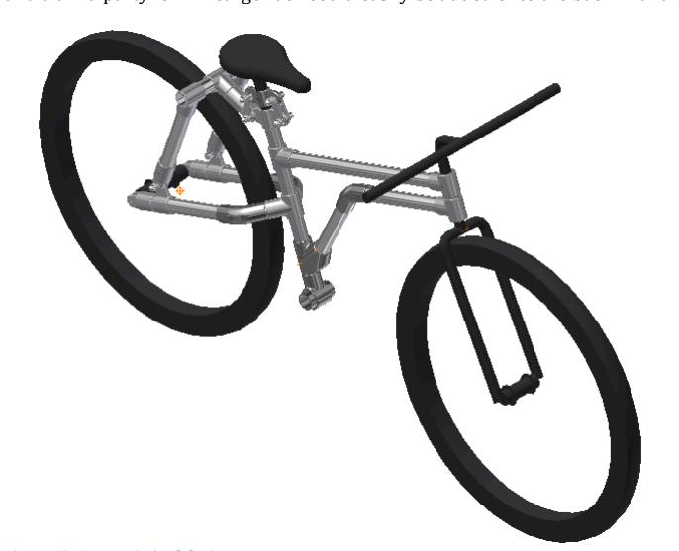
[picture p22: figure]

Figure 68: New optimised design

## Open Source Hardware Documentation

Throughout the project the progress has been documented on github at: https://github.com/hannahrosen57/AdjustaBike-2.0/tree/master/CAD

The CAD files (raw and stl), drawings, BOMs with full details and web links to purchase parts, part drawings, and this report will be made freely available to anyone who wishes to continue the work. Great care has been taken to ensure that the drawings will make sense even to someone with no engineering training. It should be enough that anyone will be able to build a bike or develop their own design from the design files.

## Reflection

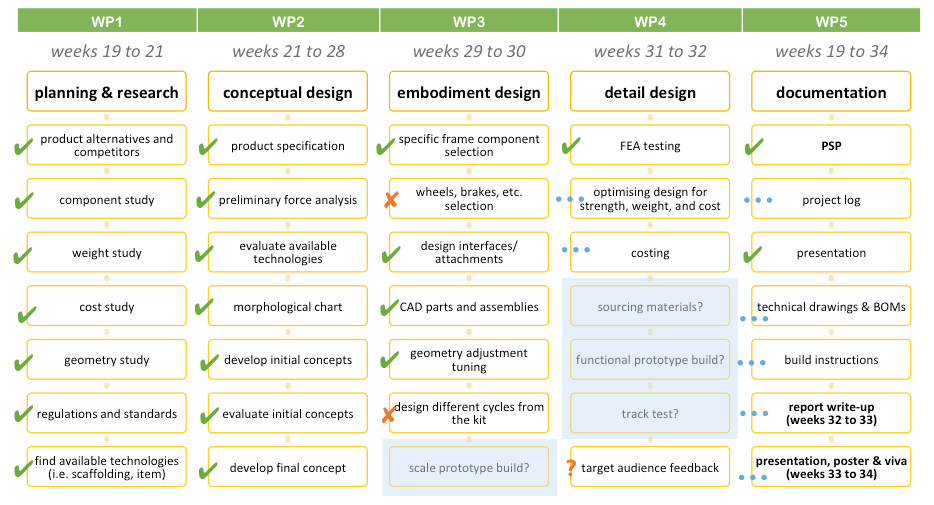
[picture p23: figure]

Further Work
- More in-depth FEA, such as impact analysis, fatigue analysis, and more validation
- Develop alternative designs such as “Design for Adjustability” and a recumbent tricycle
- Prototyping
- Full functional prototype
- Scale model – cardboard or 3D printed
- Get feedback from target audiences on prototypes

### Did I accomplish my Aims and Objectives? - I have shown that an open source, DIY bicycle kit is feasible - I have fully developed a design - I have conducted FEA analysis - I have optimised the design based on the - Most of the specification requirements were met

- The design focuses on being low cost and DIY, at the expense of some adjustability • A more adjustable design was developed to the final concept stage, but the added

complexity would result in additional weight and cost

## Conclusion

This project was undertaken to investigate the feasibility of an open source, low cost, DIY cycle kit. I have succeeded in developing a design for a bicycle frame constructed from handrail clamps, and documented the design so that anyone can continue the work or build a prototype. The design can be customised by the user, and sample geometries were included in the assembly drawings. FEA was used to analyse the design, and the bicycle frame was optimised in response to the results. The final design weighs approximately 8.4kg and costs approximately £276 for the frame alone. Further work could include building and testing prototypes, further FEA analysis, espescially focusing on the bottom bracket clamp in dynamic loads, and designing other geometries using the same components such as a cargo bike or recumbent tricycle.

## Bibliography

1

Cross N. Engineering Design Methods: Strategies for Product Design. 2nd ed. Chichester: John Wiley & Sons; 1994.
2

Ahmed MZ. Material, Design & Analysis of a Bicycle Frame. [Online].; 2014 [cited 2020 April. Available from:
https://www.academia.edu/22377748/Material_Design_and_Analysis_of_a_Bicycle_Frame.
3

Róbert Huňady MB. Structural Design and Impact Test of a Suspension Mountain Bicycle Frame by Using FEM Analysis. [Online].; 2015 [cited 2020 April. Available from: http://pubs.sciepub.com/ajme/3/6/11.
4

Alonzo R. Finite Element Analysis of an Aluminium Bike Frame. [Online]. [cited 2020 April. Available from:
https://www.google.com/url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.
5

Derek Covilla PAJMDNE. An Assessment of Bicycle Frame Behaviour under Various Load Conditions Using Numerical Simulations. [Online].; 2016 [cited 2020 April. Available from: https://www.researchgate.net/publication/305080687.
6

Mr. Rajeev Gupta MGVRSR. Analysis of Mountain Bike Frame By F.E.M.. [Online].; 2017 [cited 2020 May. Available from: https://www.researchgate.net/publication/312782741.
7
P. D. SODEN MAMBAAYSW. Loads, Stresses, and deflections in Bicycle Frames. [Online].; 1986 [cited 2020 April. Available from: https://www.researchgate.net/publication/245394050.

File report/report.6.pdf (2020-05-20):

## Appendix I: Product Specification

category | # | D/W | weight | requirement | justification miscellaneous
1 | D | - | Must have maximum total weight of 30kg | weight study
2 | W | 4 | Should aim for target total weight of 12kg or less | weight study
3 | D | - | Major maintainance (ie. servicing bearings) must be required twice a year or less by a typical user | comparison to competitors
4 | D | - | Minior maintainance (ie. cleaning drivetrain) must be required one a week or less for a typical user | comparison to competitors
5 | D | - | The frame must last at least 5 years for a typical user | comparison to competitors
6 | D | - | All components must be compatible to allow for flexibility in alternative geometries | design brief - flexible
7 | D | - | Must be suitable for a rider up to 150kg | weight percentile & BMI chart
8 | D | - | Must be comfortable and safe to ride for 5.5km on public roads | average cycle ride distance
9 | D | - | Must be capable of travelling at 25km/h on flat, smooth, dry tarmac | ISO 4210
10 | W | 3 | Should be capable of travelling at 10km/h on flat gravel paths | arbitrary target
11 | D | - | When sitting on the saddle with hips, knees, and ankles extended downward, the rider's toes should not be more than 200mm above the ground | want to avoid tallbikes or penny farthings
12 | D | - | Must have ground clearance of at least 150mm with pedals level | curb height
13 | W | 1 | Bike should be aesthetically pleasing | comparison to competitors
14 | W | 2 | Dissassembled, the bike should fit into a hard shell travel case with internal dimensions of 625 x 610 x 240 mm (preferably without detaching cables) | comparison to competitors
15 | W | 3 | Max. width between rider's knees of 250mm | feet 'shoulder width apart'
16 | D | - | Stack must be between 540mm and 590mm | geometry study
17 | W | 3 | Should be able to adjust stack between 520mm and 650mm | geometry study
18 | D | - | Reach must be between 375mm and 410mm | geometry study
19 | W | 3 | Should be able to adjust reach between 340mm and 460mm | geometry study
20 | D | - | Must be suitable for a rider 1680mm tall in a comfortable and safe riding position | me, as I'll be testing it
21 | W | 5 | Should be able to adjust frame to suit riders between 1400mm to 2000mm in height | UK height percentile chart
22 | D | - | Wheelbase must be between 985mm and 1110mm | geometry study
23 | W | 4 | Should be able to adjust wheelbase between 985mm and 1175mm | geometry study
24 | W | 3 | Trail should be between 55mm and 110mm | geometry study
25 | W | 3 | Fork rake should be between 40mm and 55mm | geometry study
26 | D | - | Standover height must be less than 860mm and suitable for the inseam of the intended rider (ie. about 700mm for a small frame) | geometry study
27 | W | 4 | Bottom bracket drop should be between 45mm and 75mm | geometry study

frame

28 | W | 4 | Head tube angle should be between 65 deg and 75 deg | ISO 4210
29 | W | 1 | Should be able to mount standard mudguards and luggage racks to frame | comparison to competitors
30 | D | - | Frame and fork must withstand the falling striker impact test outlined in ISO4210-6 4.1 with no cracks, fractures or separation of components and with permenant deformation of not more than 30mm (can use computational test if necessary) | ISO 4210
31 | D | - | Frame and fork must withstand the falling frame impact test outlined in ISO4210-6 4.2 with no cracks, fractures or separation of components and with permenant deformation of not more than 60mm (can use computational test if necessary) | ISO 4210
32 | D | - | Fork must withstand the falling striker impact test outlined in ISO4210-6 5.4 with no cracks, fractures, or separation of components, and with permenant deformation of not more than 45mm (can use computational test if necessary) | ISO 4210
33 | D | - | Fork must withstand 1000N as a cantilever for 1 min (acting to bend rearward) with permenant deformation of not more than 10mm | ISO 4210
34 | D | - | Fork must withstand 5000N in tension for 1 min with no detachment or loosening of any components | ISO 4210
| 35 | D | - | Must be able to steer using handlebars | definition of a bicycle
| 36 | D | - | The range of motion of the handlebars must be at least +/- 60 deg from straight ahead, with no tight spots, stiffness, slackness, or wobble | ISO 4210
| 37 | D | - | Handlebar width must be between 350mm and 1000mm | ISO 4210
| 38 | W | 2 | Handlebar grips should be round with a diameter of 22.2mm | standard for flat bars
| 39 | D | - | Handlebar grip nominal diameter must be between 12mm and 52mm | anthropometric data
| 40 | W | 4 | Should be able to adjust position of handlebars to suit rider | comparison to competitors
| 41 | D | - | Handlebars and stem must withstand 600N exerted 50mm from the end of the handlebar grip parallell to fork steerer, for 1 min, with no cracking or fracture and permenant deformation of less than 15mm | ISO 4210
| 42 | D | - | Max. vertical distance between top of handlebars and top of saddle must not be more than 400mm | ISO 4210
| 43 | W | 4 | The steering axis should intersect a line perpendicular to the ground line, drawn through the wheel centre, at a point not lower than 15 % and not higher than 60 % of the wheel radius when measured from the ground line. | ISO 4210
| 44 | D | - | Must operate on two wheels | definition of a bicycle
| 45 | D | - | Wheel rim diameter must be between 250mm and 1500mm | component study
| 46 | W | 4 | Wheels must rotate around axles with an axial and radial runout tolerance of 1mm if using rim brakes and 2mm if not | ISO 4210
| 47 | D | - | Hub bearings must have an effective coefficient of friction of less than 0.01 | comparison to competitors
| 48 | D | - | Tyre width must be between 18mm and 130mm | component study

steering

wheels

49 | D | -

There must be at least 6mm of clearance between the tyre and the frame/fork/mudguard/any
attachment bolts | ISO 4210
50 | D | - | Wheels must be centrally aligned in fork and frame | ISO 4210
51 | W | 5 | When secured with wheel retention device, wheels must resist 2300N for 1 min with no relative motion between axle and fork/frame | ISO 4210
| 52 | D | - | There must be at least two independently actuated brakes | UKSI 19831176, ISO 4210
| 53 | D | - | At least one brake must act on each wheel | UKSI 19831176, ISO 4210
| 54 | D | - | Any hand-operated brakes must be arranged left-hand rear, right-hand front | PBSR, ISO 4210
| 55 | D | - | Braking mechanisms must be adjustable to ensure they are effective even with some wear or with different wheels etc. | ISO 4210
| 56 | W | 5 | Max. stopping distance of 7m from 25 m/s dry or 5m from 16 km/h wet using both brakes | ISO 4210
| 57 | W | 5 | Max. stopping distance of 15m from 25 m/s dry or 10m from 16 km/h wet using rear brake only | ISO 4210
| 58 | W | 4 | Wet:Dry performace ratio as calculated in ISO 4210 must be at least 0.4 | ISO 4210
| 59 | D | - | No component of braking system must fail during above track tests | ISO 4210
| 60 | D | - | In the above track tests, stopping must be smooth and safe, without excessive skidding, and the rider must not lose control or put a foot on the ground | ISO 4210
| 61 | D | - | Bike must be propelled by pedalling | definition of a bicycle
| 62 | W | 4 | Crank length should be between 165mm and 175mm | geometry study
| 63 | W | 4 | Bike should be able to lean sideways by at least 25 deg without pedal touching the ground (in any crank position) | ISO 4210
| 64 | D | - | Pedal/crank/bottom bracket assembly should rotate smoothly with no tight spots, stiffness, slackness, wobble, or binding | ISO 4210
| 65 | W | 4 | Pedals should have 100mm clearance with steered arc of front tyre | ISO 4210
| 66 | D | - | Assembled drive system must be able to withstand a perpendicular force of 1500N exerted on the pedal with the driven wheel clamped for 1 min with no cracking or deformation of components | ISO 4210
| 67 | D | - | If relevant, belt tensile strength must be at least 4000N or chain tensile strength must be at least 8000N | ISO 4210
| 68 | W | 5 | Transmission must have a nominal efficiency of at least 90% | comparison to competitors
| 69 | D | - | Bike must have a seat for the rider to sit on | definition of a bicycle
| 70 | D | - | Seat must be securely attached | ISO 4210
| 71 | W | 4 | Seat height should be between 850mm and 1050mm | based on my inseam
| 72 | W | 4 | Should be able to adjust seat height with a range of at least 200mm | component study
| 73 | D | - | Maximum seat height must be at least 635mm | ISO 4210
| 74 | W | 2 | Should be able to adjust horizontal position of saddle with a range of at least 30mm | component study
| 75 | W | 2 | Should be able to adjust angle of saddle with a range of at least 5 deg | component study

braking

drivetrain

seat

safety

76 | W | 1 | Pedals should have yellow front and rear reflectors | RVLR, ISO 4210
77 | W | 5 | All materials should be weather resistant (including rain, frost, and UV) | usage environment
78 | D | - | Bike must function between -5 deg C and 40 deg C | usage environment
79 | D | - | Bike must withstand structural integrity test outlined in ISO 4210-3 Annex A with no component failure, loosening, or misalignment | ISO 4210-3 Annex A
80 | D | - | Bike must pass a road test of at least 1km fully loaded, demonstrating stable handling in braking and steering, and no component failure, loosening, or misalignment. It must be possible to safely ride with 1 hand (as when giving turn signals). | ISO 4210-2 4.19
81 | D | - | A safety factor of 2.5 should be used during design calculations | safety factor guidelines
82 | D | - | There must be no sharp protruding edges | ISO 4210-2
83 | W | 5 | Except for screw threads which protrude by 1 major diameter or less, any protrusions must be protected, especially where they could be impacted during a fall | ISO 4210-2
84 | D | - | All components must be securely fastened together such that they cannot be accidentally unfastened during normal use | ISO 4210-2
85 | D | - | All fastenings must be able to withstand the estimated shear and tensile loads they will be subjected to with a safety factor of 8.5 | safety factor guidelines
86 | D | - | All safety critical screw threads must have locking devices (such as lock nuts or loctite) in order to resist vibration | ISO 4210
87 | D | - | Frame fatigue strength after 100,000 cycles must be at least 83.3% tensile strength | ISO 4210-2 4.8.4,5,6
88 | W | - | Must be able to attach front(white) and rear(red) lights and reflectors, and a bell | PBSR, RVLR
89 | W | 3 | Should have either a chain/belt cover or a disc with diameter at least 10mm larger than pulley/sprocket protecting drivetrain | ISO 4210
| 90 | D | - | Must be able to source all components and raw materials for £1,200 or less | cost study
| 91 | W | 5 | Should aim for a target price of £200 or less | cost study, FYP budget
| 92 | D | - | Must be possible to manufacture components safely with only the tools available to a layman | design brief - accessible
| 93 | W | 4 | Should be possible to manufacture components safely in 20 hours or less and with only one person (can use vices to secure work) | design brief - accessible; weekend project manhours
| 94 | D | - | All materials must be commercially available to a layman | design brief - accessible
| 95 | D | - | Sourcing materials and manufacturing methods must be consistent/repeatable from documentation | design brief - open source
| 96 | W | 4 | Should be able to assemble in 3 hours or less with only one person | design brief - accessible
| 97 | D | - | Must be able to assemble in 3 hours or less with two people | design brief - accessible
| 98 | W | 5 | Should be able to assemble with only simple hand tools and without a jig | design brief - accessible
| 99 | D | - | Assembly process must be non-destructive | design brief - flexible

manufacture

assembly

## Appendix II: Mind-maps

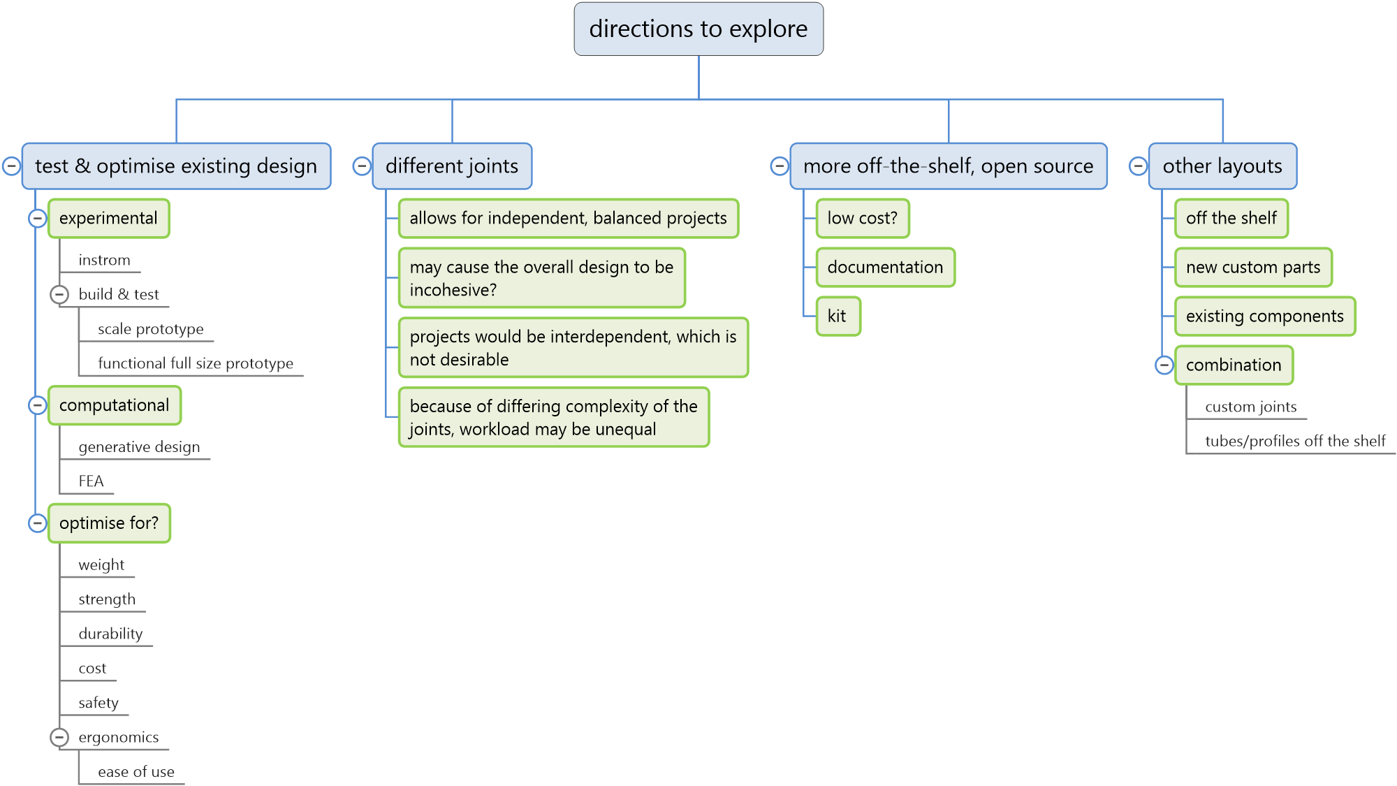
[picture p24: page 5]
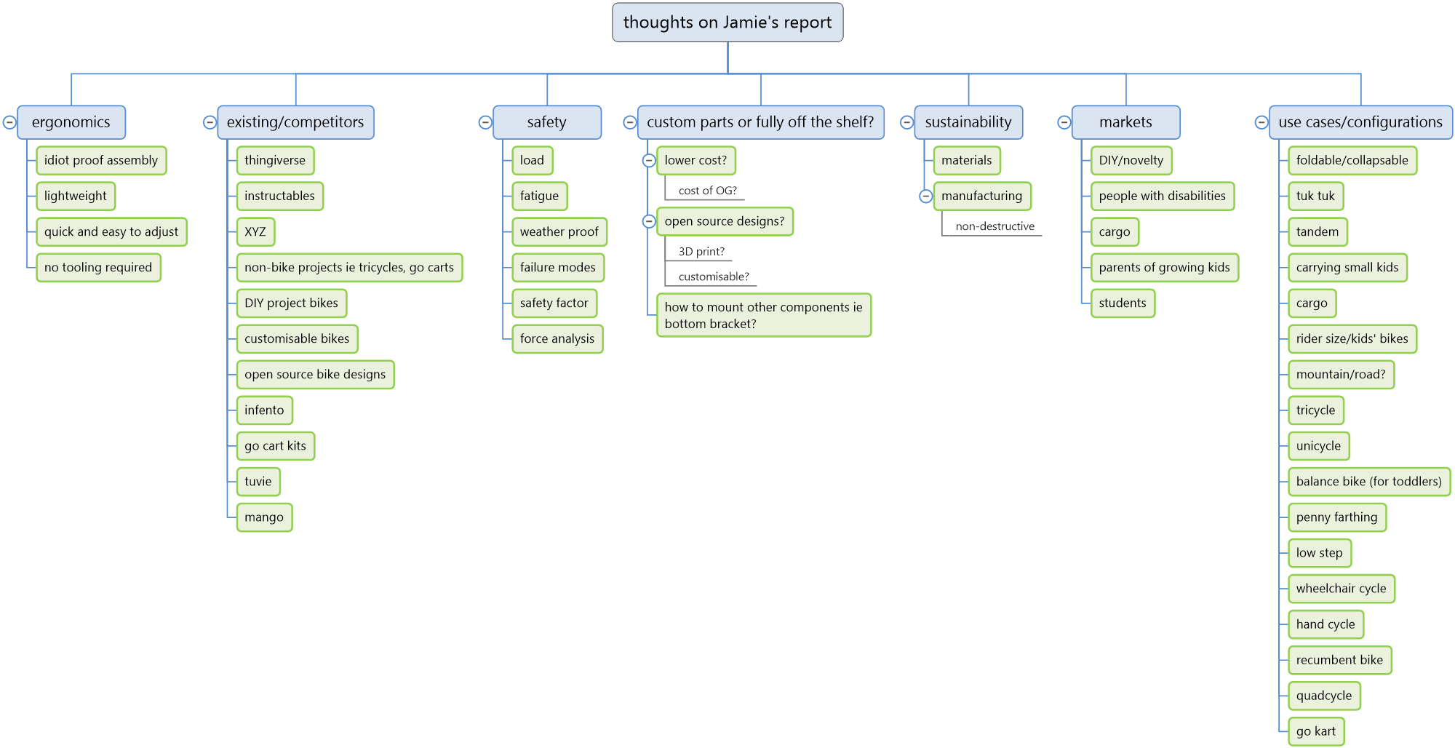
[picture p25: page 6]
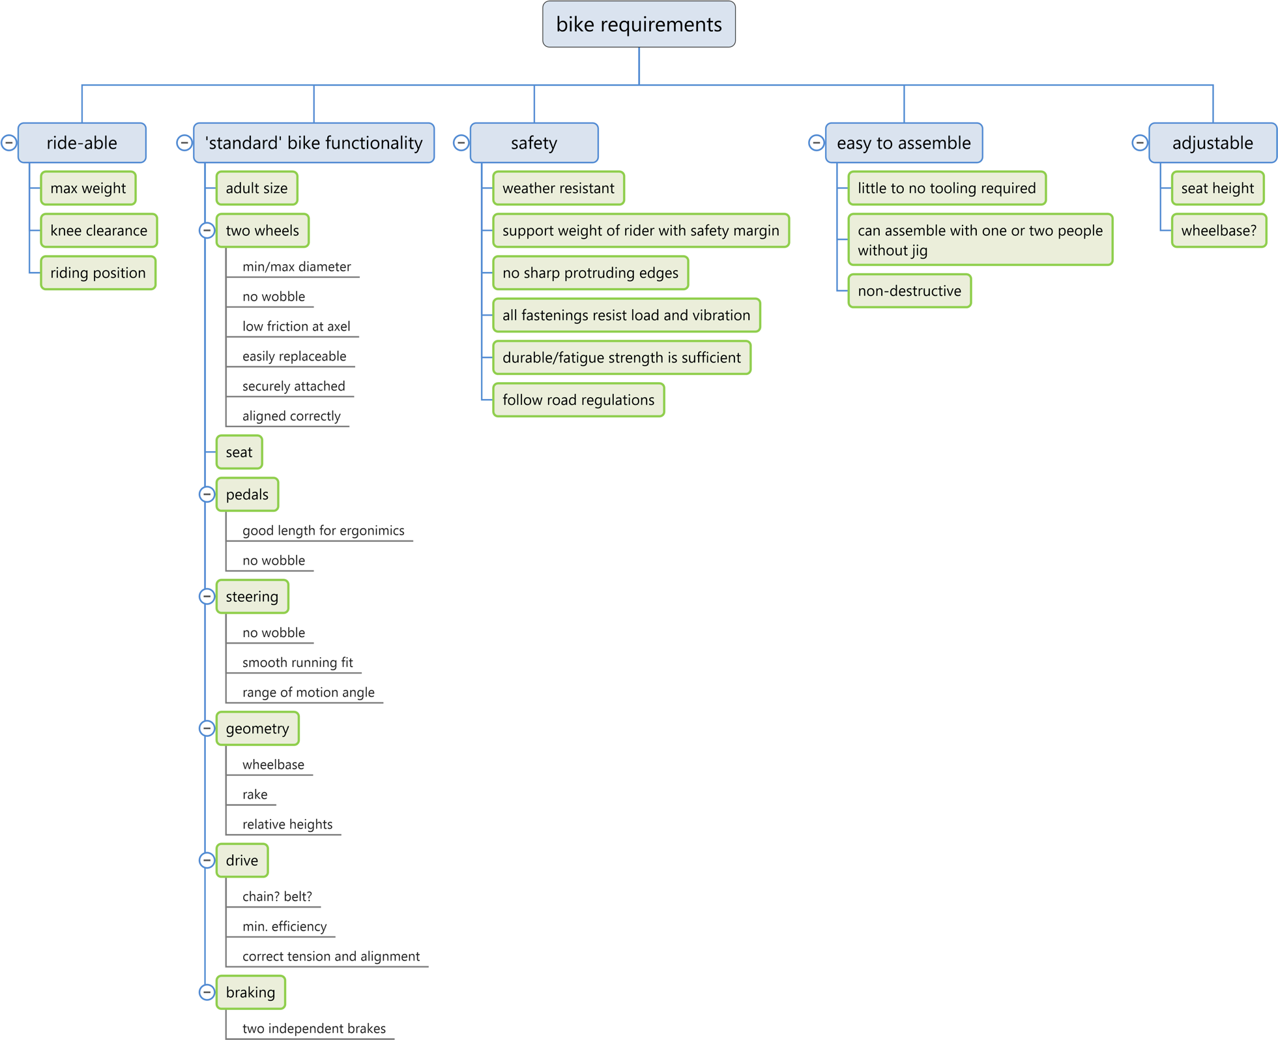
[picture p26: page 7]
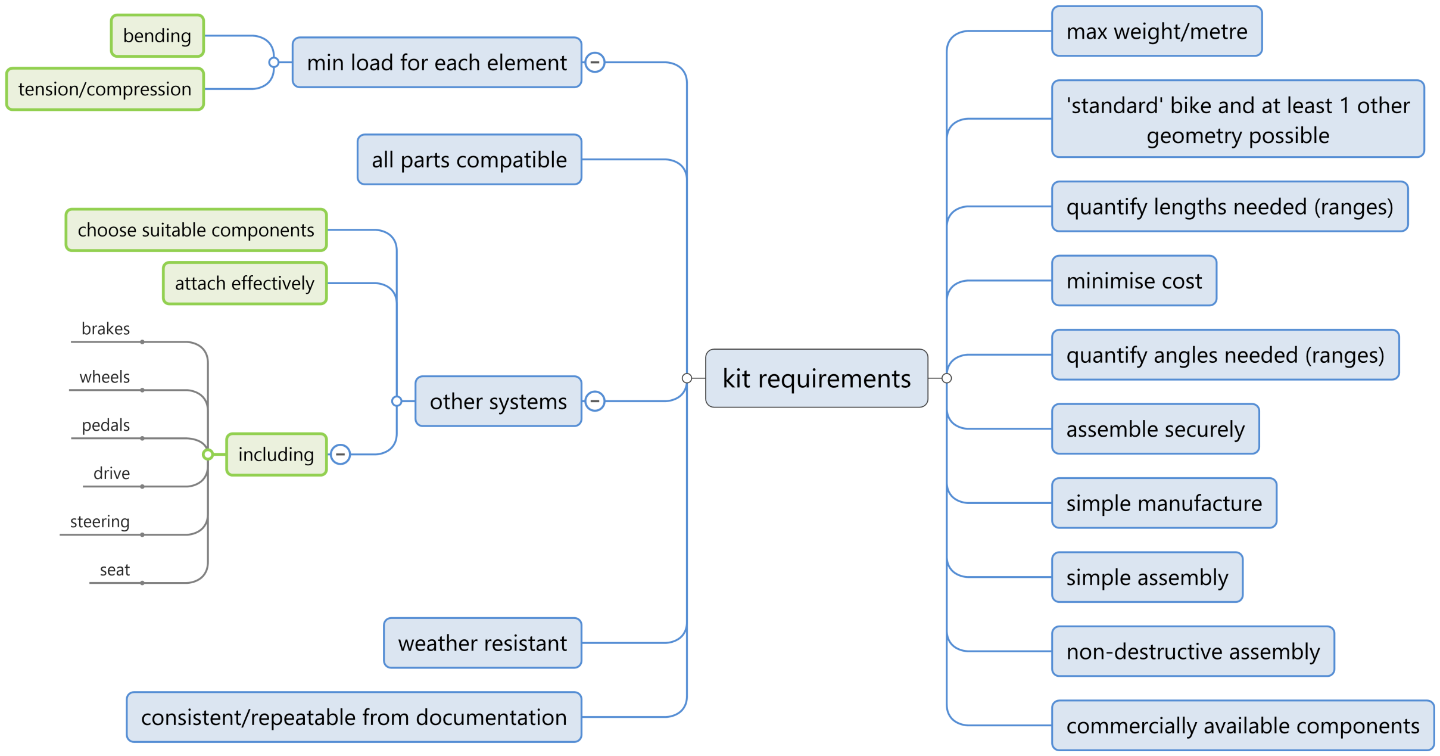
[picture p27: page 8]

## Appendix III: AvTech Eval

This page is intentionally left mostly blank; the spreadsheet printout will be inserted after exporting.

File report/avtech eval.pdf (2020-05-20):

design force (kN): | 3.5 | | | m (kg) C (£) | | FC: adj m (kg) C (£) | FC: per m (kg) C (£)
design moment (Nm): 135.5 | target | 7 £ | 70 | frame 19.0 £ 455 | frame | 9.6 £ 201
min safety factor: | 2.5 | 4 | max | 15 £ | 200 | bike 25.0 £ 555 | bike 16.6 £ 351
technology | product line | D
| (mm)

t
| | (mm)

d
(mm)
| | | rho

(g/cc) c (mm) A (mm^2) Sy (MPa) Ic (mm4) screw Fs (kN)

Fs
(kN)

Mb

(Nm) min sf Sd
(Mpa)

Sb
(Mpa)

Sc

(Mpa) | sf | link

(/m) /joint total (4m, 6
joints) | link (/m) | /joint | /cut
Profiles 5 | 20 - M5 | 2.7 10 | 180 | 195 | 7200 | 1 0.20 | 5 | 0.037 | 19.4 188.2 207.6 | 0.939 | 0.49 0.081 | 2.4 | £6.99 | £16.95 | £2.70
Profiles 6 | 30 - M6 | 2.7 15 | 467 | 195 | 41500 | 3.5 0.50 | 10 | 0.07 | 7.5 | 49.0 | 56.5 | 3.453 | 1.26 0.163 | 6.0 | £12.29 | £16.84 | £2.70
Profiles 6 L | 30 - M6 | 2.7 15 | 343 | 195 | 29000 | 1 0.50 | 10 | 0.07 | 10.2 | 70.1 | 80.3 | 2.429 | 0.93 0.163 | 4.7 | £9.29 | £16.84 | £2.70
Profiles 6 D30 | 30 - M6 | 2.7 15 | 279 | 195 | 16900 | 3.5 0.50 | 10 | 0.07 | 12.5 120.3 132.8 | 1.468 | 0.75 0.163 | 4.0 | £12.12 | £12.00 | £2.70
Profiles 8 | 40 - M8 | 2.7 20 | 916 | 195 139600 | 10 0.75 | 20 | 0.15 | 3.8 | 19.4 | 23.2 | 8.393 | 2.47 0.41 | 12.4 | £17.66 | £12.24 | £2.70
Profiles 8 L | 40 - M8 | 2.7 20 | 646 | 195 | 90000 | 5 0.75 | 20 | 0.15 | 5.4 | 30.1 | 35.5 | 5.488 | 1.74 0.41 | 9.4 | £11.17 | £12.24 | £2.70
Profiles 8 E | 40 - M8 | 2.7 20 | 507 | 195 | 73800 | 3.5 0.75 | 20 | 0.15 | 6.9 | 36.7 | 43.6 | 4.47 | 1.37 0.41 | 7.9 | £10.71 | £12.24 | £2.70
Profiles 8 D40 | 40 - M8 | 2.7 20 | 545 | 195 | 56300 | 7 0.75 | 20 | 0.15 | 6.4 | 48.1 | 54.6 | 3.574 | 1.47 0.41 | 8.3 | £19.23 | £12.13 | £2.70
Profiles 10 | 50 - M10 | 2.7 25 | 1331 | 195 306800 | 14 1.50 | 25 | 0.18 | 2.6 | 11.0 | 13.7 | 14.26 | 3.59 0.8 | 19.2 | £34.16 | £5.78 | £2.70
Profiles 10 E | 50 - M10 | 2.7 25 | 847 | 195 203400 | 7 1.50 | 25 | 0.18 | 4.1 | 16.7 | 20.8 | 9.381 | 2.29 0.8 | 13.9 | £22.90 | £5.78 | £2.70
Profiles 12 | 60 - M12 | 2.7 30 | 2060 | 195 705000 | 20 2.00 | 34 | 0.25 | 1.7 | 5.8 | 7.5 | 26.12 | 5.56 0.14 | 23.1 | £61.90 | £13.58 | £3.85
Profiles 12 L | 60 - M12 | 2.7 30 | 1450 | 195 460200 | 10 2.00 | 34 | 0.25 | 2.4 | 8.8 | 11.2 | 17.34 | 3.92 0.25 | 17.2 | £45.01 | £13.58 | £3.85
tube and
bracket | graphit; aluminium hi-load | 28.6 | 3.5 21.6 | 2.7 | 14.3 | 276.0 | 250 22157.1 - | 0.74 - | 0.21 | 12.7 | 87.5 100.1 | 2.497 | 0.75 0.52 | 6.1 | £5.50 | £1.50 | £0.50
steel 27mm light | 26.9 | 2.3 22.3 | 8 13.45 | 177.8 | 195 13563.5 | 16 | 14 2500 | 4.00 | 19.7 134.4 154.1 | 1.266 | 1.42 | 0.3 | 7.5 | £2.40 | £2.04 | £0.00
steel 34mm light | 33.8 | 2.6 28.6 | 8 | 16.9 | 254.8 | 195 31225.0 | 16 | 14 2500 | 4.00 | 13.7 | 73.3 | 87.1 | 2.24 | 2.04 0.45 | 10.9 | £3.38 | £2.50 | £0.00
steel 42mm light | 42.5 | 2.6 37.3 | 8 21.25 | 325.9 | 195 65131.7 | 16 | 14 2500 | 4.00 | 10.7 | 44.2 | 54.9 | 3.549 | 2.61 0.72 | 14.7 | £4.19 | £3.08 | £0.00
steel 27mm medium | 27.2 | 2.6 | 22 | 8 | 13.6 | 200.9 | 195 15369.6 | 16 | 14 2500 | 4.00 | 17.4 119.9 137.3 | 1.42 | 1.61 | 0.3 | 8.2 | £2.55 | £2.04 | £0.50
steel 34mm medium | 34.2 | 3.2 27.8 | 8 | 17.1 | 311.6 | 195 37835.4 | 16 | 14 2500 | 4.00 | 11.2 | 61.2 | 72.5 | 2.691 | 2.49 0.45 | 12.7 | £3.56 | £2.50 | £0.50
steel 42mm medium | 42.9 | 3.2 36.5 | 8 21.45 | 399.1 | 195 79139.6 | 16 | 14 2500 | 4.00 | 8.8 | 36.7 | 45.5 | 4.286 | 3.19 0.72 | 17.1 | £4.41 | £3.08 | £0.50
aluminium 33.4mm | 33.4 3.38 26.64 | 2.7 | 16.7 | 318.8 | 250 36364.7 | 14 | 12 1500 | 3.43 | 11.0 | 62.2 | 73.2 | 3.415 | 0.86 0.22 | 4.8 | £5.49 | £12.00 | £0.00
aluminium 33.7mm | 33.7 | 3.2 27.3 | 2.7 16.85 | 306.6 | 250 36046.6 | 14 | 12 1500 | 3.43 | 11.4 | 63.3 | 74.8 | 3.344 | 0.83 0.22 | 4.7 | £5.48 | £12.00 | £0.00
aluminium 42.2mm | 42.16 3.56 35.04 | 2.7 21.08 | 431.7 | 250 81086.8 | 14 | 12 1500 | 3.43 | 8.1 | 35.2 | 43.3 | 5.769 | 1.17 0.35 | 6.8 | £16.65 | £16.00 | £0.00
aluminium 42.4mm | 42.4 | 2.6 37.2 | 2.7 | 21.2 | 325.1 | 250 64644.5 | 14 | 12 1500 | 3.43 | 10.8 | 44.4 | 55.2 | 4.529 | 0.88 0.35 | 5.6 | £24.56 | £16.00 | £0.00
aluminium 33.4mm links;
steel 34mm clamps | 33.4 3.38 26.64 | 2.7 | 16.7 | 318.8 | 250 36364.7 | 16 | 14 2500 | 4.00 | 11.0 | 62.2 | 73.2 | 3.415 | 0.86 0.45 | 6.1 | £5.49 | £2.50 | £0.00
aluminium 1 5/8" SWG 10;
steel 42mm clamps | 41.27 | 3.2 34.87 | 2.7 20.64 | 382.7 | 250 69825.8 | 16 | 14 2500 | 4.00 | 9.1 | 40.0 | 49.2 | 5.08 | 1.03 0.72 | 8.5 | £8.82 | £3.08 | £0.50
aluminium 1 5/8" SWG 16;
steel 42mm clamps | 41.27 | 1.6 38.07 | 2.7 20.64 | 199.4 | 170 39289.1 | 16 | 14 2500 | 4.00 | 17.6 | 71.2 | 88.7 | 1.92 | 0.54 0.72 | 6.5 | £4.32 | £3.08 | £0.50
aluminium 42.2mm; steel
42mm clamps | 42.16 3.56 35.04 | 2.7 21.08 | 431.7 | 250 81086.8 | 16 | 14 2500 | 4.00 | 8.1 | 35.2 | 43.3 | 5.77 | 1.17 0.72 | 9.0 | £16.65 | £3.08 | £0.00
aluminium 42.4mm; steel
42mm clamps | 42.4 | 2.6 37.2 | 2.7 | 21.2 | 325.1 | 250 64644.5 | 16 | 14 2500 | 4.00 | 10.8 | 44.4 | 55.2 | 4.53 | 0.88 0.72 | 7.8 | £24.56 | £3.08 | £0.00
Solid Clamps 30x3 6082T6 | 30 | 3 | 24 | 2.7 | 15 | 254.5 | 250 23474.8 - | 4.8 | 148 | 1.09 | 13.8 | 86.6 100.3 | 2.49 | 0.69 0.344 | 4.8 | £7.66 | £31.40 | £0.50
Solid Clamps 30x2 6060 | 30 | 2 | 26 | 2.7 | 15 | 175.9 | 150 17329.0 - | 4.8 | 148 | 1.09 | 19.9 117.3 137.18 | 1.09 | 0.48 0.344 | 4.0 | £5.13 | £31.40 | £0.50
Solid Clamps 40x3 6082T6 | 40 | 3 | 34 | 2.7 | 20 | 348.7 | 250 60066.5 - | 6 | 376 | 1.71 | 10.0 | 45.1 55.15 | 4.53 | 0.94 0.861 | 8.9 | £10.26 | £39.19 | £0.50
Solid Clamps 40x1.5 6063T6 | 40 | 2 | 36 | 2.7 | 20 | 238.8 | 170 43215.7 - | 6 | 376 | 1.71 | 14.7 | 62.7 77.368 | 2.20 | 0.64 0.861 | 7.7 | £9.24 | £39.19 | £0.50
Solid Clamps 50x3 6060 | 50 | 3 | 44 | 2.7 | 25 | 443.0 | 150 122811.9 - | 12 | 695 | 3.43 | 7.9 | 27.6 35.48 | 4.23 | 1.20 1.166 | 11.8 | £12.97 | £42.52 | £0.50
Solid Clamps 50x1.5 6063T6 | 50 | 2 | 46 | 2.7 | 25 | 301.6 | 170 87009.6 - | 12 | 695 | 3.43 | 11.6 | 38.9 50.538 | 3.36 | 0.81 1.166 | 10.3 | £7.26 | £42.52 | £0.50
30x30 | 30 - | - | 2.7 | 15 | 363.0 | 250 | 33000 | 9.6 | 61.6 71.233 | 3.51 | 0.98 | 3.9
40x40 | 40 - | - | 2.7 | 20 | 705.0 | 250 112000 | 5.0 | 24.2 29.161 | 8.57 | 1.90 | 7.6
40x40 L | 40 - | - | 2.7 | 20 | 475.0 | 250 | 71000 | 7.4 | 38.2 45.537 | 5.49 | 1.28 | 5.1
4off 12.7mm 6063 | 12.7 | 1.6 | 9.5 | 2.7 | 6.35 | 55.8 | 170 | 877.2 | 62.7 980.9 1043.6 | 0.65 | 0.15 | 2.4 | £5.95
4off 25mm 6082T6 | 25 | 1.5 | 22 | 2.7 | 12.5 | 110.7 | 250 | 7675.7 | 31.6 220.7 252.27 | 3.96 | 0.30 | 4.8 | £5.70
polymer rod Nylon 6 50mm +RK connect. | 50 | 25 | 0 1.14 | 25 | 1963.5 | 82 306796.2 - | 12 | 695 | 3.43 | 1.166 £42.52 43.686 | 1.88 | 2.24 1.166 | 15.9 | £38.14 | £42.52 | £1.25
joint | link

kee hand
railings

item24
industrial
building kits
ID | characteristics | approx weight (kg) | approx costs (£)

RK Tube
Connectors

RK Profiles

box section/
square tube

shipping total (4m, 6j,
8c, s)

sizes
intercom
patible?

adjustable
angle?

adjustable
length?

inline 3-
way
joints?
S | W | C | F total

weight:
£25.00 | £ | 176.26 | yes | yes | sliding + | some | yes | 0 | 2 | 1 | 2 | 0
£25.00 | £ | 196.80 | yes | yes | sliding + | some | yes | 0 | 2 | 1 | 2 | 0
£25.00 | £ | 184.80 | yes | yes | sliding + | some | yes | 0 | 2 | 1 | 2 | 0
£25.00 | £ | 167.08 | yes | yes | sliding + | some | yes | 0 | 2 | 1 | 2 | 0
£25.00 | £ | 190.68 | yes | yes | sliding + | some | yes | 0 | 1 | 1 | 2 | 0
£25.00 | £ | 164.72 | yes | yes | sliding + | some | yes | 0 | 1 | 1 | 2 | 0
£25.00 | £ | 162.88 | yes | yes | sliding + | some | yes | 0 | 1 | 1 | 2 | 0
£25.00 | £ | 196.30 | yes | yes | sliding + | some | yes | 0 | 1 | 1 | 2 | 0
£25.00 | £ | 217.92 | yes | no | limited | limited | yes | 0 | 0 | 0 | 1 | 0
£25.00 | £ | 172.88 | yes | no | limited | limited | yes | 0 | 1 | 1 | 1 | 0
£25.00 | £ | 384.88 | yes | no | limited | limited | yes | 0 | 0 | 0 | 1 | 0
£25.00 | £ | 317.32 | yes | no | limited | limited | yes | 0 | 0 | 0 | 1 | 0
£25.00 | £ | 60.00 | some | yes | sliding | yes | yes | 0 | 2 | 2 | 2 | 0 | lightweights
£6.00 | £ | 27.86 | some | yes | sliding | yes | galvanised | 0 | 1 | 2 | 2 | 0
£6.00 | £ | 34.52 | some | yes | sliding | yes | galvanised | 1 | 1 | 2 | 2 | 4
£6.00 | £ | 41.23 | some | yes | sliding | yes | galvanised | 1 | 1 | 2 | 2 | 4
£10.00 | £ | 36.46 | some | yes | sliding | yes | galvanised | 0 | 1 | 2 | 2 | 0
£10.00 | £ | 43.25 | some | yes | sliding | yes | galvanised | 1 | 1 | 2 | 2 | 4
£10.00 | £ | 50.10 | some | yes | sliding | yes | galvanised | 2 | 0 | 2 | 2 | 0
£35.00 | £ | 128.96 | no | no | sliding | swivel only yes | 1 | 2 | 1 | 1 | 2
£35.00 | £ | 128.92 | no | no | sliding | swivel only yes | 1 | 2 | 1 | 1 | 2
£35.00 | £ | 197.60 | no | some | sliding | swivel only yes | 2 | 2 | 1 | 1 | 4
£35.00 | £ | 229.22 | no | some | sliding | swivel only yes | 2 | 2 | 0 | 1 | 0
£20.00 | £ | 56.96 | some | yes | sliding | yes | links:yes;
| | | | | | | joints:galv. | 1 | 2 | 2 | 2 | 8
£35.00 | £ | 92.74 | some | yes | sliding | yes | links:yes;
| | | | | | | joints:galv. | 2 | 1 | 1 | 2 | 4
£35.00 | £ | 74.75 | some | yes | sliding | yes | links:yes;
| | | | | | | joints:galv. | 0 | 2 | 1 | 2 | 0
£35.00 | £ | 120.06 | some | yes | sliding | yes | links:yes;
| | | | | | | joints:galv. | 2 | 1 | 1 | 2 | 4
£35.00 | £ | 151.68 | some | yes | sliding | yes | links:yes;
| | | | | | | joints:galv. | 2 | 1 | 1 | 2 | 4
£25.00 | £ | 248.04 | yes | yes | yes | no | yes | 0 | 2 | 0 | 2 | 0
£25.00 | £ | 237.93 | yes | yes | yes | no | yes | 0 | 2 | 0 | 2 | 0
£25.00 | £ | 305.20 | yes | yes | yes | no | yes | 0 | 1 | 0 | 2 | 0
£25.00 | £ | 301.11 | yes | yes | yes | no | yes | 0 | 1 | 0 | 2 | 0
£25.00 | £ | 336.01 | yes | yes | yes | no | yes | 2 | 1 | 0 | 2 | 0
£25.00 | £ | 313.16 | yes | yes | yes | no | yes | 1 | 1 | 0 | 2 | 0
| £ | - | some | yes | sliding | no | yes | 1 | 2 | 1 | 1 | 2
| £ | - | some | yes | sliding | no | yes | 2 | 1 | 1 | 1 | 2
| £ | - | some | yes | sliding | no | yes | 2 | 2 | 1 | 1 | 4
£12.50 | £ | 107.70 | yes | no | discreet | no | yes | 0 | 2 | 1 | 0 | 0
£12.50 | £ | 103.70 | yes | no | discreet | no | yes | 1 | 2 | 1 | 0 | 0
£15.00 | £ | 432.68 | yes | yes | no | no | yes | 0 | 0 | 0 | 1 | 0 | what did I expect?

heavy duty hinges not strong enough; 1 direct fastener not strong enough; angle clamps probably not strong enough

score/rank
notes
approx costs (£) | flexibility
corrosion
resistance

fasten with grub screw directly into tube; may damage tube and make adjustment more difficult; note with 1 5/8" connector fit may be compromised

clamps around circumference; looks promising! (expensive)

need more data

limited flexibilty

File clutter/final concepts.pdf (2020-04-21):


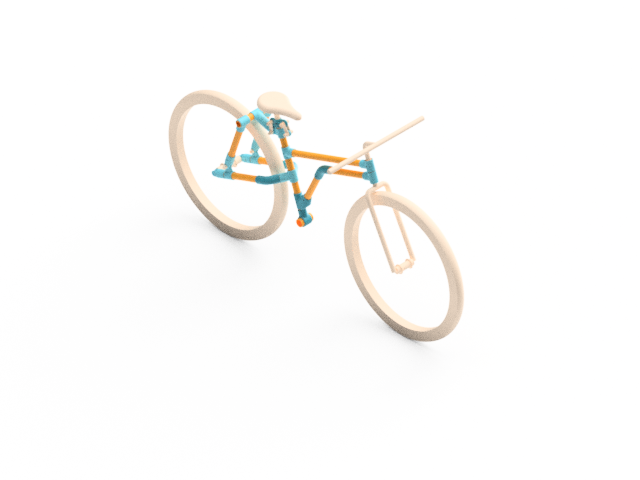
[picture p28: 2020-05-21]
CAD/renders/LW bike 9.png

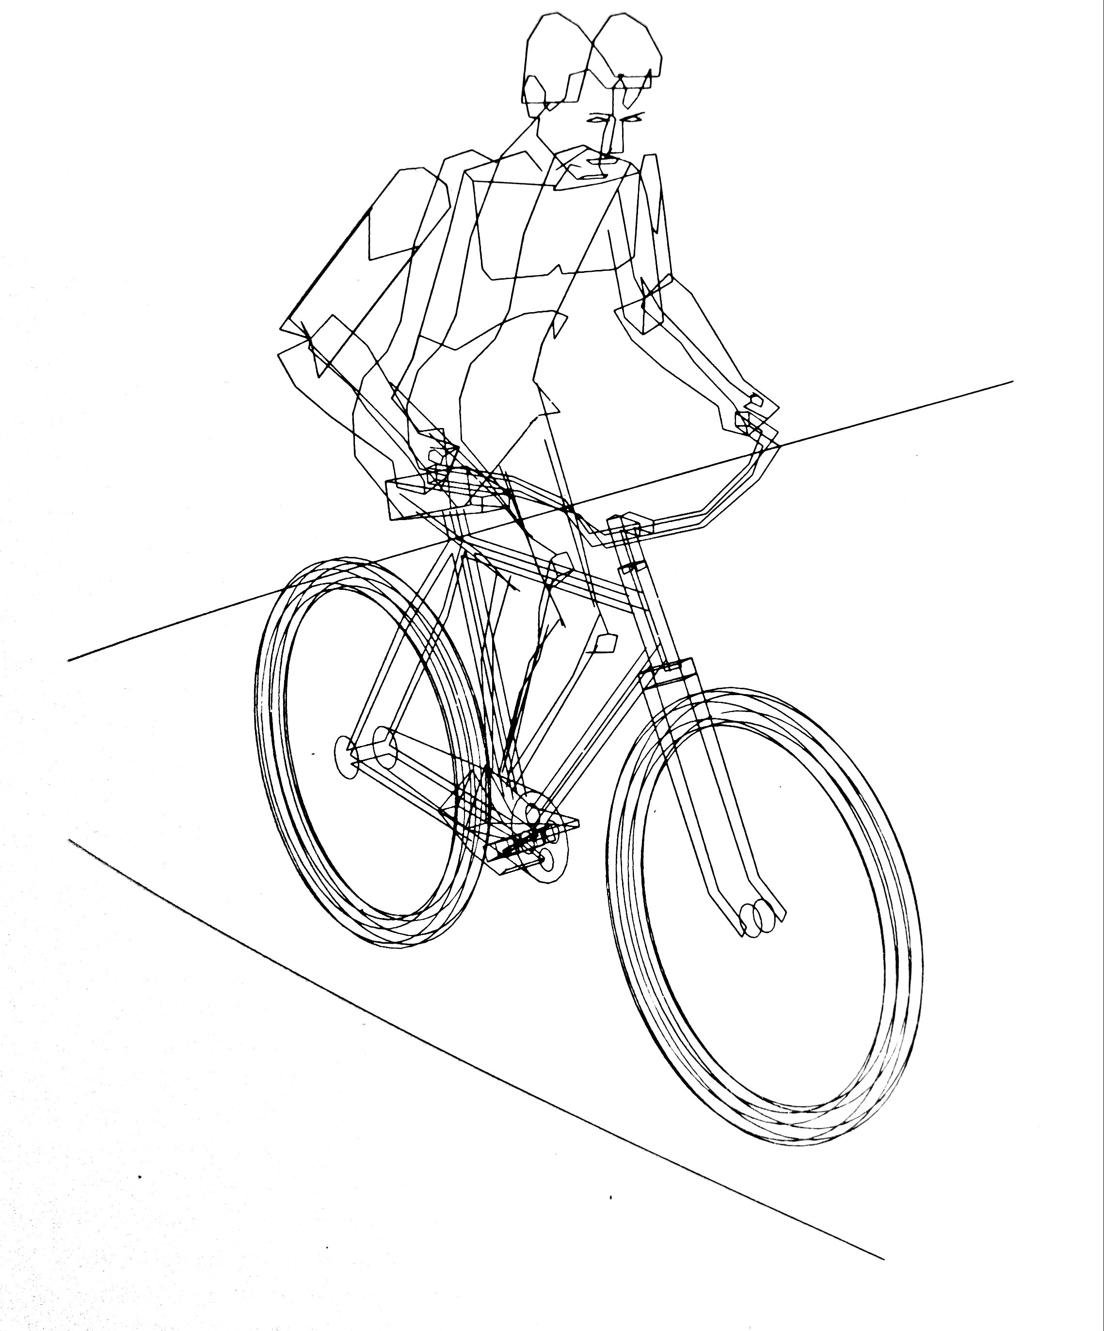
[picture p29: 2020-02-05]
PSP/images/graphic.jpg

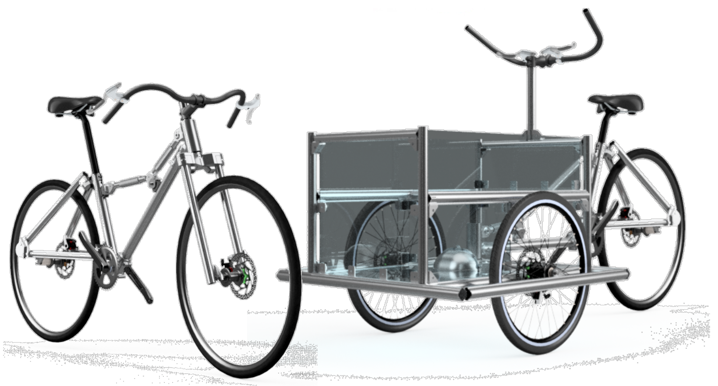
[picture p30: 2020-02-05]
PSP/images/adjustabike.PNG

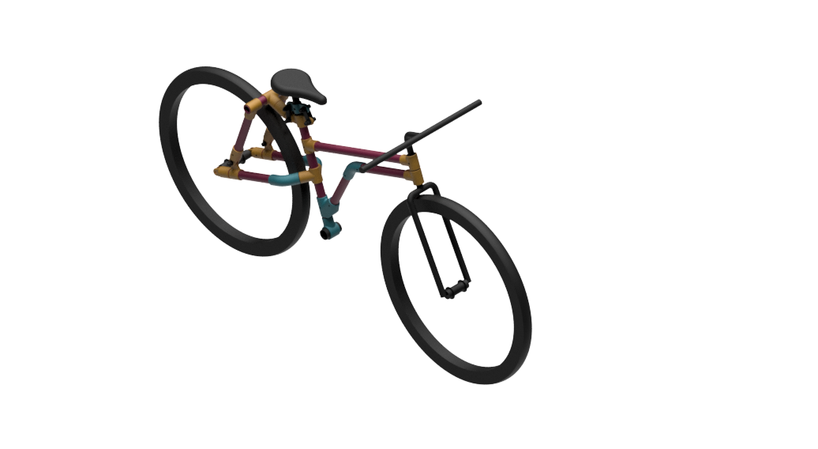
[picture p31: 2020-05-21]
CAD/renders/LW bike 2.png

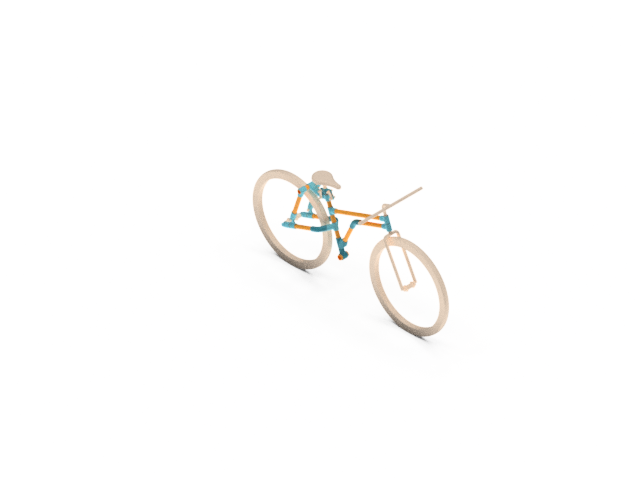
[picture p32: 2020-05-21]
CAD/renders/LW bike 8.png

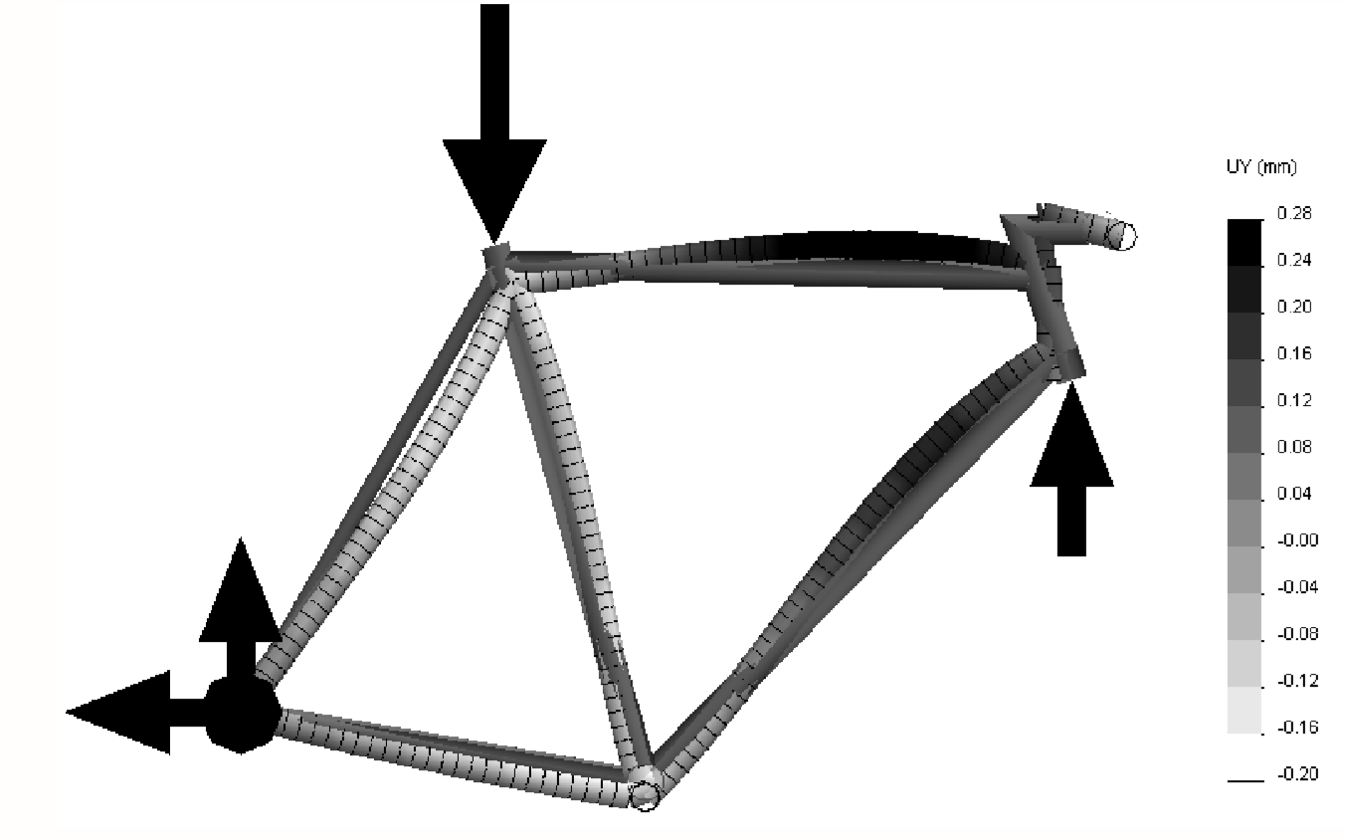
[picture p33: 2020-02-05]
PSP/images/fea.PNG

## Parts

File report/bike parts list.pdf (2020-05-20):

Page 1 | bike parts list.xlsx
ITEM | PART NUMBER REV | DESCRIPTIONQTY | Size | OD (mm) Length (mm)MATERIAL MASS (kg) ESTIMATED COST VENDOR WEBLINK
25 | M10 W A2 - | M10 Washer (2mm thick) 18 | Stainless Steel AISI 304 0.0 £.23 | Accu | https://www.accu.co.uk/en/flat-washers/72471-HPW-M10-A2
24 | M10 DN A2 - | M10 Dome Nut | 6 | Stainless Steel AISI 304 0.019 £.62 | Accu | https://www.accu.co.uk/en/dome-nuts/62123-HDN-M10-A2
23 | M10x45 SHCS A2 - | M10 x 45mm Socket Head Cap Screw 4 | Stainless Steel AISI 304 0.035 £.65 | Accu | https://www.accu.co.uk/en/cap-head-screws/2928-SSC-M10-45-A2
22 | M10x35 SHCS A2 - | M10 x 35mm Socket Head Cap Screw 2 | Stainless Steel AISI 304 0.041 £.66 | Accu | https://www.accu.co.uk/en/cap-head-screws/2926-SSC-M10-35-A2
21 | LINK | 1 | seatpost clamp link 4 | Aluminium 6082 T60.016 £3.00 | Custom
20 | L114-6 | - | swivel tee | 1 6 | Aluminium Cast 0.18 £18.50 | Kee Systemshttps://keesystems.com/store/fittings/kee-lite/l114-swivel-tee.html
19 | 55-7 | - | 120 to 150 deg elbow2 7 | Iron, Cast | 0.81 £12.91 | Kee Systemshttps://keesystems.com/store/fittings/kee-klamp/55-obtuse-angle-elbow.html
18 | M51-5 | - | male double swivel socket 1 5 | Iron, Cast | 0.33 £10.30 | Kee Systemshttps://keesystems.com/store/fittings/kee-klamp/m51-male-double-swivel-socket-member.html
17 | LM51-7 | - | male double swivel socket 1 7 | Aluminium Cast | 0.2 £16.46 | Kee Systemshttps://keesystems.com/store/fittings/kee-lite/lm51-male-double-swivel-socket-member.html
16 | LM50-7 | - | male swivel socket 2 7 | Aluminium Cast 0.15 £10.34 | Kee Systemshttps://keesystems.com/store/fittings/kee-lite/lm50-male-single-swivel-socket-member.html
15 | LF50-7 | - | female swivel socket 2 7 | Aluminium Cast 0.25 £11.17 | Kee Systemshttps://keesystems.com/store/fittings/kee-lite/lf50-female-single-swivel-socket-member.html
14 | LF50-6 | - | female swivel socket 3 6 | Aluminium Cast 0.17 £8.64 | Kee Systemshttps://keesystems.com/store/fittings/kee-lite/lf50-female-single-swivel-socket-member.html
13 | 329-7 | - | 11 to 30 deg tee | 2 7 | Iron, Cast | 0.63 £13.21 | Kee Systemshttps://keesystems.com/store/fittings/kee-klamp/329-single-socket-tee.html
12 | L21-7 | - | 90 deg side outlet tee1 7 | Aluminium Cast | 0.3 £18.35 | Kee Systemshttps://keesystems.com/store/fittings/kee-lite/l21-side-outlet-tee.html
11 | L10-7 | - | single socket tee | 3 6.5 | Aluminium Cast | 0.2 £13.46 | Kee Systemshttps://keesystems.com/store/fittings/kee-lite/l10-single-socket-tee.html
10 | L10-6 | - | single socket tee | 2 6 | Aluminium Cast 0.13 £9.56 | Kee Systemshttps://keesystems.com/store/fittings/kee-lite/l10-single-socket-tee.html
9 | BBSleeve73.42 - | bottom bracket | 1 7 | 42 | 73 Steel, Mild | 0.243 £7.00 | Ceeway | https://www.framebuilding.com/NEWPARTSPAGES/Other%20BB%20shells.htm
8 | ZALC18210 - | head tube | 1 6 | 41 | 150 Aluminium 7005 T60.122 £7.00 | Ceeway | https://www.framebuilding.com/ZONAL.htm
7 | CSP | 1 | chainstay spacer | 2 7 | 42.2 80 | Aluminium 6082 T60.093 £1.33 | Simplified Building https://simplifiedbuilding.co.uk/tube/aluminium-tube/store-materials-tube-size-7-aluminium-tubing
6 | CS | 1 | chainstay | 2 7 | 42.2 300 | Aluminium 6082 T60.35 £5.00 | Simplified Building https://simplifiedbuilding.co.uk/tube/aluminium-tube/store-materials-tube-size-7-aluminium-tubing
5 | SSP | 1 | seatstay spacer | 1 6 | 33.7 228 | Aluminium 6082 T60.189 £1.25 | Scaffolding Direct https://www.scaffolding-direct.co.uk/5-metre-aluminium-tube-33-7mm-alloy-tube/
4 | SS | 1 | seatstay | 2 6 | 33.7 260 | Aluminium 6082 T60.215 £1.42 | Scaffolding Direct https://www.scaffolding-direct.co.uk/5-metre-aluminium-tube-33-7mm-alloy-tube/
3 | DT | 1 | down tube | 1 7 | 42.2 494 | Aluminium 6082 T60.576 £8.23 | Simplified Building https://simplifiedbuilding.co.uk/tube/aluminium-tube/store-materials-tube-size-7-aluminium-tubing
2 | TT | 1 | top tube | 1 7 | 42.2 505 | Aluminium 6082 T60.589 £8.41 | Simplified Building https://simplifiedbuilding.co.uk/tube/aluminium-tube/store-materials-tube-size-7-aluminium-tubing
1 | ST | 1 | seat tube | 1 7 | 42.2 440 | Aluminium 6082 T60.513 £7.33 | Simplified Building https://simplifiedbuilding.co.uk/tube/aluminium-tube/store-materials-tube-size-7-aluminium-tubing

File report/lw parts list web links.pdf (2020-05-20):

lw parts list web links.xlsx | Page 1
ITEM | PART NUMBER REV | DESCRIPTIONQTY | Size | OD (mm) Length (mm)MATERIAL MASS (kg) ESTIMATED COST VENDOR WEBLINK
25 | M10 W A2 - | M10 Washer (2mm thick) 18 | Stainless Steel AISI 304 0.0 £.23 | Accu | https://www.accu.co.uk/en/flat-washers/72471-HPW-M10-A2
24 | M10 DN A2 - | M10 Dome Nut | 6 | Stainless Steel AISI 304 0.019 £.62 | Accu | https://www.accu.co.uk/en/dome-nuts/62123-HDN-M10-A2
23 | M10x45 SHCS A2 - | M10 x 45mm Socket Head Cap Screw 4 | Stainless Steel AISI 304 0.035 £.65 | Accu | https://www.accu.co.uk/en/cap-head-screws/2928-SSC-M10-45-A2
22 | M10x35 SHCS A2 - | M10 x 35mm Socket Head Cap Screw 2 | Stainless Steel AISI 304 0.041 £.66 | Accu | https://www.accu.co.uk/en/cap-head-screws/2926-SSC-M10-35-A2
21 | LINK | 1 | seatpost clamp link 4 | Aluminium 6082 T60.016 £3.00 | Custom
20 | L114-6 | - | swivel tee | 1 6 | Aluminium Cast 0.18 £18.50 | Kee Systemshttps://keesystems.com/store/fittings/kee-lite/l114-swivel-tee.html
19 | 55-6 | - | 120 to 150 deg elbow3 6 | Iron, Cast | 0.51 £9.01 | Kee Systemshttps://keesystems.com/store/fittings/kee-klamp/55-obtuse-angle-elbow.html
18 | LM51-6 | - | male double swivel socket 1 6 | Aluminium Cast 0.16 £15.59 | Kee Systemshttps://keesystems.com/store/fittings/kee-lite/lm51-male-double-swivel-socket-member.html
17 | M51-5 | - | male double swivel socket 1 5 | Iron, Cast | 0.33 £10.30 | Kee Systemshttps://keesystems.com/store/fittings/kee-klamp/m51-male-double-swivel-socket-member.html
16 | LM50-6 | - | male single swivel socket 2 6 | Aluminium Cast 0.12 £10.97 | Kee Systemshttps://keesystems.com/store/fittings/kee-lite/lm50-male-single-swivel-socket-member.html
15 | LF50-6 | - | female swivel socket 5 6 | Aluminium Cast 0.17 £8.64 | Kee Systemshttps://keesystems.com/store/fittings/kee-lite/lf50-female-single-swivel-socket-member.html
14 | 29-6 | - | 30 to 60 deg tee | 1 6 | Iron, Cast | 0.44 £9.59 | Kee Systemshttps://keesystems.com/store/fittings/kee-klamp/29-30-to-60-single-socket-tee.html
13 | L21-6 | - | 90 deg side outlet tee1 6 | Aluminium Cast 0.16 £12.18 | Kee Systemshttps://keesystems.com/store/fittings/kee-lite/l21-side-outlet-tee.html
12 | 10-76 | - | combination single socket tee 1 6.5 | Iron, Cast | 0.43 £12.53 | Kee Systemshttps://keesystems.com/store/fittings/kee-klamp/10-single-socket-tee.html
11 | L10-6 | - | single socket tee | 5 6 | Aluminium Cast 0.13 £9.56 | Kee Systemshttps://keesystems.com/store/fittings/kee-lite/l10-single-socket-tee.html
10 | BBSleeve73.42 - | bottom bracket | 1 7 | 42 | 73 Steel, Mild | 0.243 £7.00 | Ceeway | https://www.framebuilding.com/NEWPARTSPAGES/Other%20BB%20shells.htm
9 | OR0G18180- | head tube | 1 6 | 32.4 | 115 Steel AISI 4130 0.188 £10.00 | Ceeway | https://www.framebuilding.com/ZONA.htm
8 | CSP | 2 | chainstay spacer | 2 6 | 33.7 78 | Aluminium 6082 T60.065 £.43 | Scaffolding Direct https://www.scaffolding-direct.co.uk/5-metre-aluminium-tube-33-7mm-alloy-tube/
7 | CS | 2 | chainstay | 2 6 | 33.7 300 | Aluminium 6082 T60.248 £1.64 | Scaffolding Direct https://www.scaffolding-direct.co.uk/5-metre-aluminium-tube-33-7mm-alloy-tube/
6 | SSP | 1 | seatstay spacer | 1 6 | 33.7 228 | Aluminium 6082 T60.189 £1.25 | Scaffolding Direct https://www.scaffolding-direct.co.uk/5-metre-aluminium-tube-33-7mm-alloy-tube/
5 | SS | 1 | seatstay | 2 6 | 33.7 260 | Aluminium 6082 T60.215 £1.42 | Scaffolding Direct https://www.scaffolding-direct.co.uk/5-metre-aluminium-tube-33-7mm-alloy-tube/
4 | DTb | 1 | down tube B | 1 6 | 33.7 230 | Aluminium 6082 T60.19 £1.26 | Scaffolding Direct https://www.scaffolding-direct.co.uk/5-metre-aluminium-tube-33-7mm-alloy-tube/
3 | DTa | 1 | down tube A | 1 6 | 33.7 304 | Aluminium 6082 T60.252 £1.67 | Scaffolding Direct https://www.scaffolding-direct.co.uk/5-metre-aluminium-tube-33-7mm-alloy-tube/
2 | TT | 2 | top tube | 1 6 | 33.7 532 | Aluminium 6082 T60.44 £2.92 | Scaffolding Direct https://www.scaffolding-direct.co.uk/5-metre-aluminium-tube-33-7mm-alloy-tube/
1 | ST | 2 | seat tube | 1 6 | 33.7 440 | Aluminium 6082 T60.364 £2.41 | Scaffolding Direct https://www.scaffolding-direct.co.uk/5-metre-aluminium-tube-33-7mm-alloy-tube/

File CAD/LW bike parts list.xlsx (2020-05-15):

ITEM | PART NUMBER | REV | DESCRIPTION | QTY | Size | OD (mm) | Length (mm) | MATERIAL | MASS (kg) | ESTIMATED COST | VENDOR
1 | ST | 2 | seat tube | 1 | 6 | 33.7 | 440 | Aluminium 6082 T6 | 0.364 | £2.41 | Scaffolding Direct
2 | TT | 2 | top tube | 1 | 6 | 33.7 | 532 | Aluminium 6082 T6 | 0.44 | £2.92 | Scaffolding Direct
3 | DTa | 1 | down tube A | 1 | 6 | 33.7 | 304 | Aluminium 6082 T6 | 0.252 | £1.67 | Scaffolding Direct
4 | DTb | 1 | down tube B | 1 | 6 | 33.7 | 230 | Aluminium 6082 T6 | 0.19 | £1.26 | Scaffolding Direct
5 | SS | 1 | seatstay | 2 | 6 | 33.7 | 260 | Aluminium 6082 T6 | 0.215 | £1.42 | Scaffolding Direct
6 | SSP | 1 | seatstay spacer | 1 | 6 | 33.7 | 240 | Aluminium 6082 T6 | 0.199 | £1.32 | Scaffolding Direct
7 | CS | 2 | chainstay | 2 | 6 | 33.7 | 289 | Aluminium 6082 T6 | 0.239 | £1.58 | Scaffolding Direct
8 | CSP | 2 | chainstay spacer | 2 | 6 | 33.7 | 80 | Aluminium 6082 T6 | 0.066 | £0.44 | Scaffolding Direct
9 | OR0G18180 | - | head tube | 1 | 6 | 32.4 | 115 | Steel AISI 4130 | 0.188 | £10.00 | Ceeway
10 | BBSleeve73.42 | - | bottom bracket | 1 | 7 | 42 | 73 | Steel, Mild | 0.243 | £7.00 | Ceeway
11 | L10-6 | - | single socket tee | 5 | 6 |  |  | Aluminium Cast | 0.13 | £9.56 | Kee Systems
12 | 10-76 | - | combination single socket tee | 1 | 6.5 |  |  | Iron, Cast | 0.43 | £12.53 | Kee Systems
13 | L21-6 | - | 90 deg side outlet tee | 1 | 6 |  |  | Aluminium Cast | 0.16 | £12.18 | Kee Systems
14 | 29-6 | - | 30 to 60 deg tee | 1 | 6 |  |  | Iron, Cast | 0.44 | £9.59 | Kee Systems
15 | LF50-6 | - | female swivel socket | 5 | 6 |  |  | Aluminium Cast | 0.17 | £8.64 | Kee Systems
16 | LM50-6 | - | male single swivel socket | 2 | 6 |  |  | Aluminium Cast | 0.12 | £10.97 | Kee Systems
17 | M51-5 | - | male double swivel socket | 1 | 5 |  |  | Iron, Cast | 0.33 | £10.30 | Kee Systems
18 | LM51-6 | - | male double swivel socket | 1 | 6 |  |  | Aluminium Cast | 0.16 | £15.59 | Kee Systems
19 | 55-6 | - | 120 to 150 deg elbow | 3 | 6 |  |  | Iron, Cast | 0.51 | £9.01 | Kee Systems
20 | L114-6 | - | swivel tee | 1 | 6 |  |  | Aluminium Cast | 0.18 | £18.50 | Kee Systems
21 | LINK | 1 | seatpost clamp link | 4 |  |  |  | Aluminium 6082 T6 | 0.016 | £3.00 | Custom
22 | M10x35 SHCS A2 | - | M10 x 35mm Socket Head Cap Screw | 2 |  |  |  | Stainless Steel AISI 304 | 0.041 | £0.66 | Accu
23 | M10x45 SHCS A2 | - | M10 x 45mm Socket Head Cap Screw | 4 |  |  |  | Stainless Steel AISI 304 | 0.035 | £0.65 | Accu
24 | M10 DN A2 | - | M10 Dome Nut | 6 |  |  |  | Stainless Steel AISI 304 | 0.019 | £0.62 | Accu
25 | M10 W A2 | - | M10 Washer (2mm thick) | 18 |  |  |  | Stainless Steel AISI 304 | 0.004 | £0.23 | Accu
 |  |  |  |  |  |  |  |  | 8.358 | £275.90

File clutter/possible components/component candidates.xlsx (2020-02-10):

company/shop/site | product | description | link(s)
the tube & bracket company | graphit | modular storage; tubes and brackets; different ranges available | pdf brochures (https://github.com/hannahrosen57/AdjustaBike-2.0/tree/master/clutter/possible%20components) | website (https://tubeandbracket.com/)
item24 | various | industrial building kit; extruded aluminium and connectors | website (https://uk.item24.com/en/)
metals4u | various | aluminium tubes and clamps for handrails | website (https://www.metals4u.co.uk/tube-clamps/c180/fittings-sockets/c6641)
the metal store | various | aluminium tubes and clamps for handrails | website (https://www.themetalstore.co.uk/products/tube-clamp-uk-suppliers)
interclamp | various | tube clamps and fittings for handrails (could be source for the above?) | website (https://www.interclamp.com/)
KeyClampStore | various | key clamps from various suppliers | webpage for 34mm tube (https://www.keyclampstore.com/key-clamp-fittings/34mm-key-clamp)
Scaffolding Direct | various | Aluminium tubes and clamps for scaffolding | tube | 33.7mm clamps (https://www.scaffolding-direct.co.uk/tube-clamps-33-7mm/)

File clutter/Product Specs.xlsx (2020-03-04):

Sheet: bike spec
SPECIFICATION for DIY Bicycle
category | # | D/W | weight | requirement | justification
miscellaneous | 1 | D | - | Must have maximum total weight of 30kg | weight study
 | 2 | W | 4 | Should aim for target total weight of 15kg or less | weight study
 | 3 | D | - | Major maintainance (ie. servicing bearings) must be required twice a year or less by a typical user | comparison to competitors
 | 4 | D | - | Minior maintainance (ie. cleaning drivetrain) must be required one a week or less for a typical user | comparison to competitors
 | 5 | D | - | The frame must last at least 5 years for a typical user | comparison to competitors
 | 6 | D | - | All components must be compatible to allow for flexibility in alternative geometries | design brief - flexible
 | 7 | D | - | Must be suitable for a rider up to 150kg | weight percentile & BMI chart
 | 8 | D | - | Must be comfortable and safe to ride for 5.5km on public roads | average cycle ride distance (https://assets.publishing.service.gov.uk/government/uploads/system/uploads/attachment_data/file/821842/walking-and-cycling-statistics-2018-accessible.pdf)
 | 9 | D | - | Must be capable of travelling at 25km/h on flat, smooth, dry tarmac | ISO 4210
 | 10 | W | 3 | Should be capable of travelling at 10km/h on flat gravel paths | arbitrary target
 | 11 | D | - | When sitting on the saddle with hips, knees, and ankles extended downward, the rider's toes should not be more than 200mm above the ground | want to avoid tallbikes or penny farthings
 | 12 | D | - | Must have ground clearance of at least 150mm with pedals level | curb height
 | 13 | W | 1 | Bike should be aesthetically pleasing | comparison to competitors
 | 14 | W | 2 | Dissassembled, the bike should fit into a hard shell travel case with internal dimensions of 625 x 610 x 240 mm (preferably without detaching cables) | comparison to competitors
frame | 15 | W | 3 | Max. width between rider's knees of 250mm | feet 'shoulder width apart'
 | 16 | D | - | Stack must be between 540mm and 590mm | geometry study
 | 17 | W | 3 | Should be able to adjust stack between 520mm and 650mm | geometry study
 | 18 | D | - | Reach must be between 375mm and 410mm | geometry study
 | 19 | W | 3 | Should be able to adjust reach between 340mm and 460mm | geometry study
 | 20 | D | - | Must be suitable for a rider 1680mm tall in a comfortable and safe riding position | me, as I'll be testing it
 | 21 | W | 5 | Should be able to adjust frame to suit riders between 1400mm to 2000mm in height | UK height percentile chart
 | 22 | D | - | Wheelbase must be between 985mm and 1110mm | geometry study
 | 23 | W | 4 | Should be able to adjust wheelbase between 985mm and 1175mm | geometry study
 | 24 | W | 3 | Trail should be between 55mm and 110mm | geometry study
 | 25 | W | 3 | Fork rake should be between 40mm and 55mm | geometry study
 | 26 | D | - | Standover height must be less than 860mm and suitable for the inseam of the intended rider (ie. about 700mm for a small frame) | geometry study
 | 27 | W | 4 | Bottom bracket drop should be between 45mm and 75mm | geometry study
 | 28 | W | 4 | Head tube angle should be between 65 deg and 75 deg | ISO 4210
 | 29 | W | 1 | Should be able to mount standard mudguards and luggage racks to frame | comparison to competitors
 | 30 | D | - | Frame and fork must withstand the falling striker impact test outlined in ISO4210-6 4.1 with no cracks, fractures or separation of components and with permenant deformation of not more than 30mm (can use computational test if necessary) | ISO 4210
 | 31 | D | - | Frame and fork must withstand the falling frame impact test outlined in ISO4210-6 4.2 with no cracks, fractures or separation of components and with permenant deformation of not more than 60mm (can use computational test if necessary) | ISO 4210
 | 32 | D | - | Fork must withstand the falling striker impact test outlined in ISO4210-6 5.4 with no cracks, fractures, or separation of components, and with permenant deformation of not more than 45mm (can use computational test if necessary) | ISO 4210
 | 33 | D | - | Fork must withstand 1000N as a cantilever for 1 min (acting to bend rearward) with permenant deformation of not more than 10mm | ISO 4210
 | 34 | D | - | Fork must withstand 5000N in tension for 1 min with no detachment or loosening of any components | ISO 4210
steering | 35 | D | - | Must be able to steer using handlebars | definition of a bicycle
 | 36 | D | - | The range of motion of the handlebars must be at least +/- 60 deg from straight ahead, with no tight spots, stiffness, slackness, or wobble | ISO 4210
 | 37 | D | - | Handlebar width must be between 350mm and 1000mm | ISO 4210
 | 38 | W | 2 | Handlebar grips should be round with a diameter of 22.2mm | standard for flat bars (http://citeseerx.ist.psu.edu/viewdoc/download?doi=10.1.1.740.9865&rep=rep1&type=pdf)
 | 39 | D | - | Handlebar grip nominal diameter must be between 12mm and 52mm | anthropometric data (http://citeseerx.ist.psu.edu/viewdoc/download?doi=10.1.1.740.9865&rep=rep1&type=pdf)
 | 40 | W | 4 | Should be able to adjust position of handlebars to suit rider | comparison to competitors
 | 41 | D | - | Handlebars and stem must withstand 600N exerted 50mm from the end of the handlebar grip parallell to fork steerer, for 1 min, with no cracking or fracture and permenant deformation of less than 15mm | ISO 4210
 | 42 | D | - | Max. vertical distance between top of handlebars and top of saddle must not be more than 400mm | ISO 4210
 | 43 | W | 4 | The steering axis should intersect a line perpendicular to the ground line, drawn through the wheel centre, at a point not lower than 15 % and not higher than 60 % of the wheel radius when measured from the ground line. | ISO 4210
wheels | 44 | D | - | Must operate on two wheels | definition of a bicycle
 | 45 | D | - | Wheel rim diameter must be between 250mm and 1500mm | component study
 | 46 | W | 4 | Wheels must rotate around axles with an axial and radial runout tolerance of 1mm if using rim brakes and 2mm if not | ISO 4210
 | 47 | D | - | Hub bearings must have an effective coefficient of friction of less than 0.01 | comparison to competitors
 | 48 | D | - | Tyre width must be between 18mm and 130mm | component study
 | 49 | D | - | There must be at least 6mm of clearance between the tyre and the frame/fork/mudguard/any attachment bolts | ISO 4210
 | 50 | D | - | Wheels must be centrally aligned in fork and frame | ISO 4210
 | 51 | W | 5 | When secured with wheel retention device, wheels must resist 2300N for 1 min with no relative motion between axle and fork/frame | ISO 4210
braking | 52 | D | - | There must be at least two independently actuated brakes | UKSI 19831176, ISO 4210
 | 53 | D | - | At least one brake must act on each wheel | UKSI 19831176, ISO 4210
 | 54 | D | - | Any hand-operated brakes must be arranged left-hand rear, right-hand front | PBSR, ISO 4210
 | 55 | D | - | Braking mechanisms must be adjustable to ensure they are effective even with some wear or with different wheels etc. | ISO 4210
 | 56 | W | 5 | Max. stopping distance of 7m from 25 m/s dry or 5m from 16 km/h wet using both brakes | ISO 4210
 | 57 | W | 5 | Max. stopping distance of 15m from 25 m/s dry or 10m from 16 km/h wet using rear brake only | ISO 4210
 | 58 | W | 4 | Wet:Dry performace ratio as calculated in ISO 4210 must be at least 0.4 | ISO 4210
 | 59 | D | - | No component of braking system must fail during above track tests | ISO 4210
 | 60 | D | - | In the above track tests, stopping must be smooth and safe, without excessive skidding, and the rider must not lose control or put a foot on the ground | ISO 4210
drivetrain | 61 | D | - | Bike must be propelled by pedalling | definition of a bicycle
 | 62 | W | 4 | Crank length should be between 165mm and 175mm | geometry study
 | 63 | W | 4 | Bike should be able to lean sideways by at least 25 deg without pedal touching the ground (in any crank position) | ISO 4210
 | 64 | D | - | Pedal/crank/bottom bracket assembly should rotate smoothly with no tight spots, stiffness, slackness, wobble, or binding | ISO 4210
 | 65 | W | 4 | Pedals should have 100mm clearance with steered arc of front tyre | ISO 4210
 | 66 | D | - | Assembled drive system must be able to withstand a perpendicular force of 1500N exerted on the pedal with the driven wheel clamped for 1 min with no cracking or deformation of components | ISO 4210
 | 67 | D | - | If relevant, belt tensile strength must be at least 4000N or chain tensile strength must be at least 8000N | ISO 4210
 | 68 | W | 5 | Transmission must have a nominal efficiency of at least 90% | comparison to competitors
seat | 69 | D | - | Bike must have a seat for the rider to sit on | definition of a bicycle
 | 70 | D | - | Seat must be securely attached | ISO 4210
 | 71 | W | 4 | Seat height should be between 850mm and 1050mm | based on my inseam
 | 72 | W | 4 | Should be able to adjust seat height with a range of at least 200mm | component study
 | 73 | D | - | Maximum seat height must be at least 635mm | ISO 4210
 | 74 | W | 2 | Should be able to adjust horizontal position of saddle with a range of at least 30mm | component study
 | 75 | W | 2 | Should be able to adjust angle of saddle with a range of at least 5 deg | component study
safety | 76 | W | 1 | Pedals should have yellow front and rear reflectors | RVLR, ISO 4210
 | 77 | W | 5 | All materials should be weather resistant (including rain, frost, and UV) | usage environment
 | 78 | D | - | Bike must function between -5 deg C and 40 deg C | usage environment
 | 79 | D | - | Bike must withstand structural integrity test outlined in ISO 4210-3 Annex A with no component failure, loosening, or misalignment | ISO 4210-3 Annex A
 | 80 | D | - | Bike must pass a road test of at least 1km fully loaded, demonstrating stable handling in braking and steering, and no component failure, loosening, or misalignment. It must be possible to safely ride with 1 hand (as when giving turn signals). | ISO 4210-2 4.19
 | 81 | D | - | A safety factor of 2.5 should be used during design calculations | safety factor guidelines (https://www.engineeringtoolbox.com/factors-safety-fos-d_1624.html)
 | 82 | D | - | There must be no sharp protruding edges | ISO 4210-2
 | 83 | W | 5 | Except for screw threads which protrude by 1 major diameter or less, any protrusions must be protected, especially where they could be impacted during a fall | ISO 4210-2
 | 84 | D | - | All components must be securely fastened together such that they cannot be accidentally unfastened during normal use | ISO 4210-2
 | 85 | D | - | All fastenings must be able to withstand the estimated shear and tensile loads they will be subjected to with a safety factor of 8.5 | safety factor guidelines (https://www.engineeringtoolbox.com/factors-safety-fos-d_1624.html)
 | 86 | D | - | All safety critical screw threads must have locking devices (such as lock nuts or loctite) in order to resist vibration | ISO 4210
 | 87 | D | - | Frame fatigue strength after 100,000 cycles must be at least 83.3% tensile strength | ISO 4210-2 4.8.4,5,6
 | 88 | W | - | Must be able to attach front(white) and rear(red) lights and reflectors, and a bell | PBSR, RVLR
 | 89 | W | 3 | Should have either a chain/belt cover or a disc with diameter at least 10mm larger than pulley/sprocket protecting drivetrain | ISO 4210
manufacture | 90 | D | - | Must be able to source all components and raw materials for £1,200 or less | cost study
 | 91 | W | 5 | Should aim for a target price of £200 or less | cost study, FYP budget
 | 92 | D | - | Must be possible to manufacture components safely with only the tools available to a layman | design brief - accessible
 | 93 | W | 4 | Should be possible to manufacture components safely in 20 hours or less and with only one person (can use vices to secure work) | design brief - accessible; weekend project manhours
 | 94 | D | - | All materials must be commercially available to a layman | design brief - accessible
 | 95 | D | - | Sourcing materials and manufacturing methods must be consistent/repeatable from documentation | design brief - open source
assembly | 96 | W | 4 | Should be able to assemble in 3 hours or less with only one person | design brief - accessible
 | 97 | D | - | Must be able to assemble in 3 hours or less with two people | design brief - accessible
 | 98 | W | 5 | Should be able to assemble with only simple hand tools and without a jig | design brief - accessible
 | 99 | D | - | Assembly process must be non-destructive | design brief - flexible

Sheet: test methods
 | SUMMARY OF TEST METHODS FROM ISO4210 REFERENCED IN SPECIFICATION
note - permenant deformation is the difference between the length under static load before and after impact
note - for falling striker drop tests, striker must reach at least 95% of its falling velocity (neglecting air resistance)
ref. | ISO4210-6 4.1 | ISO4210-6 4.2 | ISO4210-6 5.4 |  |  | ISO4210-3 Annex A
req. ref. | ISO4210-2 4.8.2 | ISO4210-2 4.8.3 | ISO4210-2 4.9.5 |  |  | ISO4210-3 Annex A
components | frame and fork | frame and fork | fork only |  |  | whole assembled bicycle
type | falling striker | falling frame | falling striker (test 1) --> | (test 2) --> | (test 3) | structural integrity
method | clamped vertically (axles in line) by rear axle; striker falls on 1kg roller in fork axle or dummy fork | supported horizontally; clamped but free to rotate at rear axle and resting on roller at front axle; weights attached to seat post, steering head, and bottom bracket; front axle lifted and dropped twice | supported by head bearings as a horizontal cantilever; striker dropped onto roller in rearward direction | same falling striker setup | torque of 50Nm applied about fork steerer | attach weights to seat post, each crank, and each side of the handlebar; drive on machine at 8 km/h for 6h
mass (kg) | 22.5 | SP:50, ST:10, BB:30 | 22.5 | 22.5 | n/a | SP:36, CR:[2x]18, HB:[2x]6.75
height (mm) | 180 | 200 | 180 | 600 | n/a | n/a
requirements | wheelbase permenant deformation not more than 30mm if using fork or 10 mm if using dummy fork; no cracks, fractures, or separation | wheelbase permenant deformation not more than 60mm; no cracks, fractures, or separation | permemant deformation of axle displacement relative to fork steerer axis not more than 45mm no cracks, fractures, or separation | no fractures | no relative motion between steerer and crown | no system or component failure; no misalignment or loosening

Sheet: market breakdown
category | examples | cost |  | weight (kg)
 |  | entry level | high end | min | max
mainstream bicycles | hybrid | £160.00 | £1600.00 | 10 | 16
 | mountain | £120.00 | £9000.00 | 10 | 18 | mainstream bicycles | unusual bicycles | alternative cycles | aftermarket | DIY cycle kits | flexible | open source | DIY
 | road |  |  |  |  | hybrid | folding | tandem | trailer | infento
 | fixie |  |  |  |  | mountain | wooden | recumbent trike | sidecar | bellcycle
 | bmx |  |  |  |  | road | bamboo | cruiser trike | rear wheel childseat | XYZ cargobikes
 | dutch upright |  |  |  |  | fixie | cardboard | stunt trike | trailerbike tandem | OBI 0.5
unusual bicycles | folding |  |  |  |  | bmx | tallbike | cargo trike | tandem coupler | woodenwidget
 | wooden |  |  |  |  | dutch upright | split frame | unicycle | S&S coupler | adjustabike 1.0
 | bamboo |  |  |  |  |  | penny farthing | quadcycle | wheelchair handbike attachement | sandwich bike
 | cardboard |  |  |  |  |  | longbike | tuk-tuk | trike conversion set
 | tallbike |  |  | - | - |  | recumbent | wheelchair tandem
 | split frame |  |  | - | - |  |  | handbike
 | penny farthing |  |  | - | - |  |  | fit bike
 | longbike |  |  | - | -
 | recumbent
alternative cycles | tandem
 | recumbent trike
 | cruiser trike
 | stunt trike
 | cargo trike
 | unicycle
 | quadcycle
 | tuk-tuk
 | wheelchair tandem
 | handbike
 | fit bike |  |  | - | -
aftermarket | trailer
 | sidecar
 | rear wheel childseat
 | trailerbike tandem
 | tandem coupler
 | S&S coupler |  |  | - | -
 | wheelchair handbike attachement
 | trike conversion set
DIY cycle kits | infento
 | bellcycle
 | XYZ cargobikes
 | OBI 0.5
 | woodenwidget
 | adjustabike 1.0

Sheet: geometry study
from hybrid bike boardman mtx 8.8 (cm) |  |  |  |  |  |  | size small | stack | reach | wheelbase | trail | rake | bb drop | standover | crank length
 | rider height |  |  |  |  |  | mtb | 588 | 411 | 1110 | 108.2 | 42 | 45 | 691 | 170
size | min | max | stack | reach | hyp |  | hybrid | 554 | 388 | 1053 | 67 | 55 | 68 | 690 | 170
W sm | 1470 | 1600 | 604.0 | 382 | 714.7 |  | road | 541 | 375 | 986 | 61.9 | 50 | 75 | 746 | 170
W md | 1570 | 1700 | 615.0 | 387 | 726.6
W lg | 1670 | 1800 | 624.0 | 399 | 740.7 |  | hybrid | stack | reach | wheelbase | trail | rake | bb drop | standover | crank
M sm | 1600 | 1720 | 602.0 | 391 | 717.8 |  | min | 524 | 339 | 1053 | 67 | 55 | 68 | 682 | 170
M md | 1670 | 1800 | 625.0 | 409 | 746.9 |  | max | 651 | 426 | 1120 | 67 | 55 | 68 | 852 | 175
M lg | 1750 | 1880 | 651.0 | 426 | 778.0
 |  |  |  |  |  |  | general | stack | reach | wheelbase | trail | rake | bb drop | standover | crank
from hybrid bike cannondale adventure 2 |  |  |  |  |  |  | min | 524 | 339 | 985 | 57.1 | 42 | 45 | 667 | 165
size | stack | reach | hyp |  |  |  | max | 651 | 460 | 1174 | 108.2 | 55 | 75 | 852 | 175
W sm | 607 | 339 | 695.2
W tl | 626 | 362 | 723.1
M sm | 617 | 348 | 708.4
M md | 626 | 362 | 723.1
M lg | 635 | 374 | 737.0 |  |  | from hybrid bike canondale quick 4*
M xl | 645 | 390 | 753.7 |  |  |  | SM | MD | LG | XL | 2XL
 |  |  |  |  |  | A Seat Tube Length | 400 | 450 | 500 | 550 | 600
from hybrid bike canondale quick cx 4 |  |  |  |  |  | B Top Tube Length | 557 | 573 | 588 | 603 | 619
size | stack | reach | hyp |  |  | D Head Tube Angle | 70 | 70 | 70 | 70 | 70
sm | 584 | 389 | 701.7 |  |  | E1 Seat Tube Angle Effective | 73 | 73 | 73 | 73 | 73
md | 599 | 398 | 719.2 |  |  | F Standover | 690 | 731 | 772 | 812 | 852
lg | 616 | 407 | 738.3 |  |  | G Head Tube Length | 134 | 160 | 185 | 211 | 236
xlg | 632 | 415 | 756.1 |  |  | H Wheelbase | 1053 | 1070 | 1086 | 1103 | 1120
2xl | 645 | 425 | 772.4 |  |  | I Front Center | 627 | 644 | 660 | 677 | 694
 |  |  |  |  |  | J Chain Stay Length | 435 | 435 | 435 | 435 | 435
from hybrid bike canondale quick 4* |  |  |  |  |  | K Bottom Bracket Drop | 68 | 68 | 68 | 68 | 68
size | stack | reach | hyp |  |  | L Estimated BB Height | 277 | 277 | 277 | 277 | 277
sm | 554 | 388 | 676.4 |  |  | M Fork Rake | 55 | 55 | 55 | 55 | 55
md | 578 | 396 | 700.6 |  |  | N Trail | 67 | 67 | 67 | 67 | 67
lg | 602 | 404 | 725.0 |  |  | O Stack | 554 | 578 | 602 | 626 | 650
xlg | 626 | 412 | 749.4 |  |  | P Reach | 388 | 396 | 404 | 412 | 420
2xl | 650 | 420 | 773.9 |  |  | approx total link length | 3458 | 3567 | 3673 | 3781 | 3889
 |  |  |  |  |  | from hybrid giant escape 3**
from giant escape 3** |  |  |  |  |  |  | XS | S | M | L | XL
size | stack | reach | hyp |  | B | SEAT TUBE ANGLE | 74.0° | 73.5° | 73.0° | 73.0° | 73.0°
xsm | 524 | 400 | 659.2 |  | C | TOP TUBE LENGTH (mm) | 550 | 565 | 580 | 595 | 610
sm | 538 | 406 | 674.0 |  | D | HEAD TUBE LENGTH (mm) | 100 | 115 | 130 | 160 | 190
md | 556 | 410 | 690.8 |  | E | HEAD TUBE ANGLE | 70.0° | 70.0° | 71.0° | 71.0° | 71.0°
lg | 585 | 416 | 717.8 |  | H | WHEELBASE (mm) | 1069 | 1080 | 1081 | 1097 | 1113
xlg | 613 | 423 | 744.8 |  | I | CHAIN STAY LENGTH (mm) | 451 | 451 | 451 | 451 | 451
 |  |  |  |  | K | STACK (mm) | 524 | 538 | 556 | 585 | 613
from cannondale quick women's 8 |  |  |  |  | L | REACH (mm) | 400 | 406 | 410 | 416 | 423
size | stack | reach | hyp |  | M | STAND OVER HEIGHT (mm) | 682 | 713 | 755 | 796 | 838
sm | 530 | 380 | 652.2 |  | P | CRANK LENGTH (mm) | 170 | 170 | 175 | 175 | 175
md | 554 | 388 | 676.4
tl | 578 | 396 | 700.6 |  |  | from mtb giant fathom 1 2020
 |  |  |  |  |  |  | XS | S | M | L | XL
 |  |  |  |  | A | SEAT TUBE LENGTH (mm) | 370 | 390 | 445 | 480 | 530
 |  |  |  |  | B | SEAT TUBE ANGLE | 73.5° | 73.5° | 73.5° | 73.5° | 73.5°
 |  |  |  |  | C | TOP TUBE LENGTH (mm) | 565 | 585 | 605 | 625 | 645
 |  |  |  |  | D | HEAD TUBE LENGTH (mm) | 95 | 100 | 110 | 125 | 140
 |  |  |  |  | E | HEAD TUBE ANGLE | 67.0° | 67.0° | 67.0° | 67.0° | 67.0°
 |  |  |  |  | F | FORK RAKE (mm) | 42 | 42 | 42 | 42 | 42
 |  |  |  |  | G | TRAIL (mm) | 108.2 | 108.2 | 108.2 | 108.2 | 108.2
 |  |  |  |  | H | WHEELBASE (mm) | 1089 | 1110 | 1131 | 1153 | 1174
 |  |  |  |  | I | CHAIN STAY LENGTH (mm) | 425 | 425 | 425 | 425 | 425
 |  |  |  |  | J | BOTTOM BRACKET DROP (mm) | 45 | 45 | 45 | 45 | 45
 |  |  |  |  | K | STACK (mm) | 584 | 588 | 598 | 611 | 625
 |  |  |  |  | L | REACH (mm) | 392 | 411 | 428 | 444 | 460
 |  |  |  |  | M | STAND OVER HEIGHT (mm) | 667 | 691 | 731 | 745 | 784
 |  |  |  |  | N | HANDLEBAR WIDTH (mm) | 780 | 780 | 780 | 780 | 780
 |  |  |  |  | O | STEM LENGTH (mm) | 40 | 40 | 50 | 60 | 70
 |  |  |  |  | P | CRANK LENGTH (mm) | 170 | 170 | 175 | 175 | 175
 |  |  |  |  | Q | WHEEL SIZE | 27.5" | 27.5" | 27.5" | 27.5" | 27.5"
 |  |  |  |  |  | from road bike giant contend 1 2020
 |  |  |  |  |  |  | XS | S | M | ML | L | XL
 |  |  |  |  | A | SEAT TUBE LENGTH (mm) | 430 | 465 | 500 | 535 | 555 | 585
 |  |  |  |  | B | SEAT TUBE ANGLE | 74.8° | 74.0° | 73.5° | 73.0° | 73.0° | 72.5°
 |  |  |  |  | C | TOP TUBE LENGTH (mm) | 515 | 530 | 545 | 560 | 575 | 595
 |  |  |  |  | D | HEAD TUBE LENGTH (mm) | 123 | 138 | 158 | 178 | 198 | 218
 |  |  |  |  | E | HEAD TUBE ANGLE | 71.0° | 71.8° | 72.5° | 72.5° | 72.5° | 72.5°
 |  |  |  |  | F | FORK RAKE (mm) | 50 | 50 | 50 | 50 | 50 | 50
 |  |  |  |  | G | TRAIL (mm) | 66.8 | 61.9 | 57.1 | 57.1 | 57.1 | 57.1
 |  |  |  |  | H | WHEELBASE (mm) | 985 | 986 | 990 | 1002 | 1017 | 1031
 |  |  |  |  | I | CHAIN STAY LENGTH (mm) | 412 | 412 | 412 | 412 | 412 | 412
 |  |  |  |  | J | BOTTOM BRACKET DROP (mm) | 75 | 75 | 75 | 70 | 70 | 70
 |  |  |  |  | K | STACK (mm) | 524 | 541 | 563 | 577 | 596 | 615
 |  |  |  |  | L | REACH (mm) | 372 | 375 | 378 | 384 | 393 | 401
 |  |  |  |  | M | STAND OVER HEIGHT (mm) | 720 | 746 | 774 | 803 | 821 | 844
 |  |  |  |  | N | HANDLEBAR WIDTH (mm) | 400 | 400 | 420 | 420 | 440 | 440
 |  |  |  |  | O | STEM LENGTH (mm) | 80 | 90 | 100 | 100 | 110 | 110
 |  |  |  |  | P | CRANK LENGTH (mm) | 165 | 170 | 172.5 | 172.5 | 175 | 175
 |  |  |  |  | Q | WHEEL SIZE | 700C | 700C | 700C | 700C | 700C | 700C

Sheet: avtech
company/shop/site | product | description | link(s)
the tube & bracket company | graphit | modular storage; tubes and brackets; different ranges available | pdf brochures (https://github.com/hannahrosen57/AdjustaBike-2.0/tree/master/clutter/possible%20components) | website (https://tubeandbracket.com/)
item24 | various | industrial building kit; extruded aluminium and connectors | website (https://uk.item24.com/en/)
metals4u | various | aluminium tubes and clamps for handrails | website (https://www.metals4u.co.uk/tube-clamps/c180/fittings-sockets/c6641)
the metal store | various | aluminium tubes and clamps for handrails | website (https://www.themetalstore.co.uk/products/tube-clamp-uk-suppliers)
interclamp | various | tube clamps and fittings for handrails (could be source for the above?) | website (https://www.interclamp.com/)
KeyClampStore | various | key clamps from various suppliers | webpage for 34mm tube (https://www.keyclampstore.com/key-clamp-fittings/34mm-key-clamp)
Scaffolding Direct | various | Aluminium tubes and clamps for scaffolding | tube | 33.7mm clamps (https://www.scaffolding-direct.co.uk/tube-clamps-33-7mm/)
to add:
scaffolding (so far I've only covered handrails)
timber
bamboo
3D printing
RS - clamps, bearings, etc
box section
flat bar
polymer - tubes? Flat? How to clamp? Could use lasercutting to make 'meccano' pieces?
other components - ie. Wheels, etc.
re-structure - lead with descriptive category, then list sources, diameters, etc.

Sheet: avtech eval
ID |  | tensile force (N) |  |  | bending torque (Nm) |  |  | approx weight (kg) |  |  | approx costs (£) |  |  |  |  | flexibility |  |  |  |  | score/rank |  |  |  |  | notes
technology | product line | link | joint | min. | link | joint | min. | link (/m) | /joint | total (4m, 6 joints) | link (/m) | /joint | /cut | shipping | total (4m, 6j, 8c, s) | diameters available | angles available | adjustable angle? | adjustable length? | inline 3-way joints? | T | B | W | C | F
item24 industrial building kits | Lean manufacturing tubes (diameter*mm)
 | Square grooved profile extrusions A
 | Square grooved profile extrusions B
 | Round grooved profile extrusions
tube and bracket company | grooved or smooth tubes 28.6mm diameter; aluminium; graphit (composit) joints
 | grooved or smooth tubes 28.6mm diameter; steel; graphit (composit) joints
 | grooved or smooth tubes 28.6mm diameter;aluminium; leantek (metal) joints
 | grooved or smooth tubes 28.6mm diameter; steel; leantek (metal) joints
hand railings | 26mm steel
 | 33mm steel
 | 48mm steel
 | 48mm aluminium
scaffolding
box section
flat bar
polymer tubes
polymer flat bar
timber
bamboo
3D printing

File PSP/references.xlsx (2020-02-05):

# | research gate | pdf/blog post | category | title | author(s) | year published | type | cited in work
1 |  | https://www.icebike.org/build-your-own-bike/ | bike components | How To Build Your Own Bike (And Why You Should Do It) | James Rich | 2016 | website | y
2 |  | https://www.bikeradar.com/advice/buyers-guides/the-complete-guide-to-bottom-bracket-standards/ | bike components | The complete guide to bottom bracket standards | Benedict Pfender | 2019 | website | y
3 |  | https://www.infentorides.com/kits/ | competitors | Infento Rides | Infento | 2019 | website | y
4 |  | https://bamboobee.net/ | competitors | bamboo bee | bamboo bee | 2019 | website | y
5 |  | https://all3dp.com/the-obi-0-5-is-a-3d-printed-open-source-bicycle/ | competitors | The OBI 0.5 is a 3D Printed Open Source Bicycle | Hannah Augur | 2015 | website | y
6 |  | https://techacute.com/bellcycle-the-new-open-source-modular-bike/ | competitors | Bellcycle: The New Open Source Modular Bike | Christopher Isak | 2018 | website | y
7 |  | https://www.motherearthnews.com/diy/diy-recumbent-bike-zmaz83mjzraw | competitors | A Cut-Rate DIY Recumbent Bike | the MOTHER EARTH NEWS editors | 1983 | website | y
8 |  | https://www.atomiczombie.com/ | competitors | Atomic Zombie | "Radical" Brad Graham | 2019 | website | y
9 |  | https://sandwichbikes.com/ | competitors | Sandwich Bike | Sandwich Bike | 2019 | website | y
10 |  | https://texasrecumbents.wordpress.com/no-weld-trikes/ | competitors | DIY No-weld Recumbent Trikes and Bikes | "TexasTuff" | 2016 | website | y
11 |  | http://www.woodenwidget.com/hoopy.htm | competitors | WoodenWidget: Hoopy Wooden Bicycle | WoodenWidget | 2019 | website | y
12 |  | jamie's report | competitors | Adjustabike: Open Source Adjustable Bike | Jamie Taylor | 2019 | paper | y
13 |  | http://bellcycles.com/ | competitors | BellCycles: The Bicycle Reimagined | Alex Bell | 2019 | website | y
14 | https://www.researchgate.net/publication/295675697_Multi-objective_optimization_of_an_on-road_bicycle_frame_by_uniform_design_and_compromise_programming | https://content.iospress.com/articles/integrated-computer-aided-engineering/ica00231 | consumer/market | Modeling of modularity and scaling for integration of customer in design of engineer-to-order products | Siddique, Zahed | 2006 | paper | y
15 | https://www.researchgate.net/publication/220306589_On_combinatorial_design_spaces_for_the_configuration_design_of_product_families | https://www.cambridge.org/core/journals/ai-edam/article/on-combinatorial-design-spaces-for-the-configuration-design-of-product-families/E0F95566FA89D85AB29BA0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 | consumer/market | On combinatorial design spaces for the configuration design of product families | ZAHED SIDDIQUE | 2001 | paper | y
16 |  | https://www.emerald.com/insight/content/doi/10.1108/07363760310489689/full/html | consumer/market | Mass‐customisation in marketing: the consumer perspective | Ahmet Bardakci | 2003 | paper | y
17 |  | https://journals.sagepub.com/doi/full/10.1177/1687814017739513 | engineering of bikes | Structural analysis and optimization of bicycle frame designs | Chien-Cheng Lin | 2017 | paper
18 |  | https://www.sciencedirect.com/science/article/pii/S1877705816307160 | engineering of bikes | An Assessment of Bicycle Frame Behaviour under Various Load Conditions Using Numerical Simulations | Derek Covill | 2016 | paper | y
19 |  | https://www.cyclingabout.com/understanding-bicycle-frame-geometry/ | engineering of bikes | Understanding Bicycle Frame Geometry | Alee Denham | 2013 | website | y
20 |  | https://www.sciencedirect.com/science/article/pii/S1877705814005931 | engineering of bikes | Parametric finite element analysis of bicycle frame geometries | Derek Covill | 2014 | paper | y
21 | https://www.researchgate.net/publication/220183579_Designing_effective_step-by-step_assembly_instructions | https://www.researchgate.net/publication/220183579_Designing_effective_step-by-step_assembly_instructions | Instructions | Designing Effective Step-By-Step Assembly Instructions | Maneesh Agrawala | 2003 | paper | y
22 |  | https://www.researchgate.net/publication/221738861_Procedural_Instructions_Principles_and_Examples_How_to_Structure_Instructions_for_Procedural_Tasks_to_Enhan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 | Intructions | Procedural Instructions, Principles, and Examples How to Structure Instructions for Procedural Tasks to Enhance Performance, Learning, and Transfer | Elsa Eiriksdottir | 2011 | paper | y
23 |  | https://www.oshwa.org/definition/ | open source | Open Source Hardware Association: Definition | OSHWA | 2019 | website | y
24 |  | https://www.oshwa.org/sharing-best-practices/ | open source | Open Source Hardware Association: Best Practices | OSHWA | 2019 | website | y
25 |  | https://aisel.aisnet.org/cgi/viewcontent.cgi?article=3055&context=cais | open source | Open Source: Concepts, Benefits, and Challenges | Mohammad AlMarzouq | 2005 | paper | y
26 |  | https://researchportal.bath.ac.uk/en/publications/practices-in-the-design-of-open-source-products-by-online-communi | open source | Practices in the design of open source products by online communities | Bonvoisin, Jérémy | 2017 | paper | y
 |  | http://www.xyzcargo.com/ | competitors | XYZ CARGO | XYZ CARGO | 2019 | website | y
 |  |  | engineering of bikes | Bicycling Science | Frank Rowland Whitt | 1974 | book

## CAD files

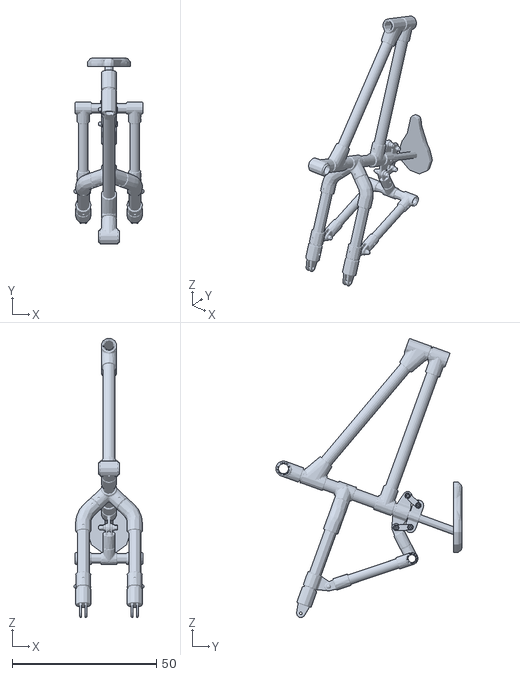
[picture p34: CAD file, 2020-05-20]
CAD/exportedCAD/bike.stl
24.2 x 64.5 x 96.6

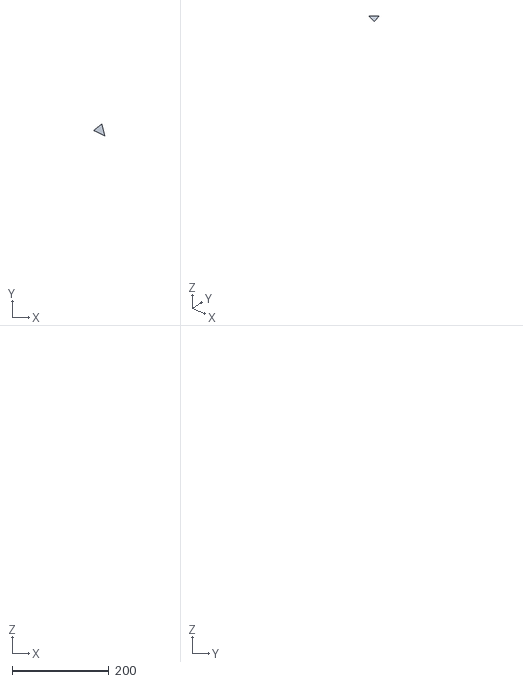
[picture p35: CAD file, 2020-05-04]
CAD/simplified/InCAD/FEA/3upryc280.STL
63.4 x 118.0 x 583.8

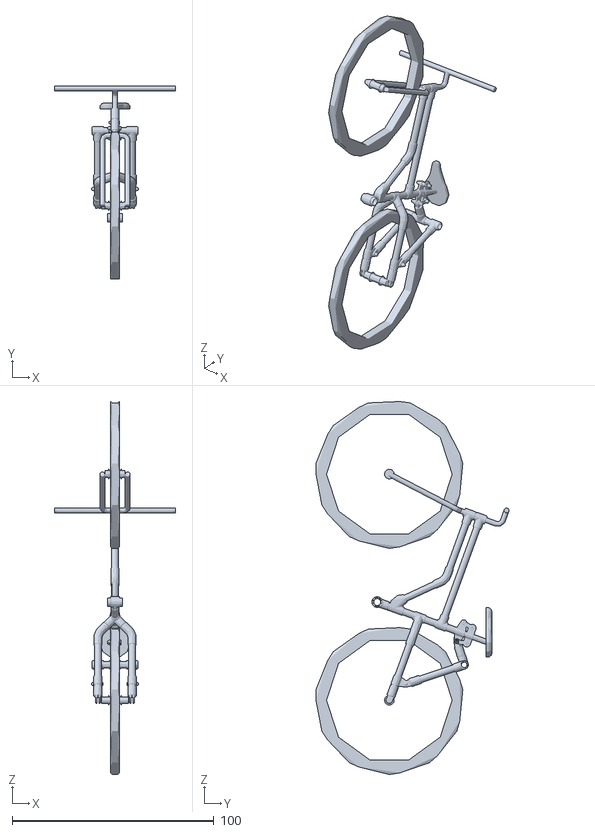
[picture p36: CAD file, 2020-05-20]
CAD/exportedCAD/LW bike.stl
60.0 x 95.7 x 184.7

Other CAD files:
clutter/possible components/RE__CAD_files/LM51-7.dwg
clutter/possible components/RE__CAD_files/LM51-6.dwg
clutter/possible components/RE__CAD_files/L26-6.dwg
clutter/possible components/RE__CAD_files/LM50-7.dwg
clutter/possible components/RE__CAD_files/L29-7.dwg
clutter/possible components/RE__CAD_files/LF50-6.dwg
clutter/possible components/RE__CAD_files/L10-7.dwg
clutter/possible components/RE__CAD_files/LM50-6.dwg
clutter/possible components/RE__CAD_files/L10-6.dwg
clutter/possible components/RE__CAD_files/L114-7.dwg
clutter/possible components/RE__CAD_files/L26-7.dwg
clutter/possible components/RE__CAD_files/LF50-7.dwg
clutter/possible components/RE__CAD_files/L45-6.dwg
clutter/possible components/RE__CAD_files (1)/45-6 Model.dwg
clutter/possible components/RE__CAD_files (1)/10-65.dwg
CAD/10-65.ipt
CAD/10-67.ipt
CAD/10-76.ipt
CAD/29-6.ipt
CAD/329-7.ipt
CAD/45-76.ipt
CAD/55-6.ipt
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

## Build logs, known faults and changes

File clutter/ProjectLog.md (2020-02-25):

# Project Log
This document is intended to be an ongoing record of the progress of the AdjustaBike 2.0 project. The project is building on the Adjustabike, which was an adjustable DIY bicycle kit concept developed by a previous Final Year student, Jamie. The aim is to accomplish the same goal, but to make it as accessible to the lay person as possible by using mostly off-the-shelf parts and simple manufacturing methods, and to ensure that the kit is truly open-source by documenting it thoroughly.

[jump to end](https://github.com/hannahrosen57/AdjustaBike-2.0/blob/master/ProjectLog.md#end-link)

## Friday 1st November (retro)
### Introductory Meeting Minutes
- Review existing work and concepts
- How to divide work between Alex and me?
  - test & optimise / design & develop
  - computational / experimental
  - different joints?
  - different directions entirely?
- Parts to manufacture - drawings
  - get in touch with Jamie?
- Timescale? need to establish the broad strokes, especially of assesments
- Literature Review (what to include)
- Technicians (need to attend tech surgery)
  - machining
  - testing - introm machines?
- To consider when designing and evaluating bike:
  - Vibrations
  - Maximum/typical load
  - Mass/weight
  - Ergonomics
    - Riding position
    - Knee clearance
    - Transmitted forces
  - Cost
  - Ease of assembly

To do before next meeting on Wednesday 6th:
- [x] Read through Jamie's report thoroughly
- [x] Have a good think about the best way to divide the work
- [x] Hash out rough outline of deadlines
- [x] Get an idea of what's involved in each handin
- [x] Review examples of past PSPs

## Tuesday 5th November (retro)
- Reviewed the outline of the timeline and hand-ins given in the 'FYP Instructions' booklet
- Read through and highlighted Jamie's report. It should be helpful for writing the PSP, especially the lit review
- Brainstormed (see below):
  - Directions the project could be taken, to help decide how to divide the work with Alex
  - Thoughts/observations after reading Jamie's report
  
directions to explore

thoughts on Jamie's Report

## Wednesday 6th November (retro)
### Project Brief Meeting
Alex and I had both taken the past few days to familiarise ourselves with the project. After reviewing our thoughts and findings, we agreed that Alex would take the existing designs and improve them to make them more manufacturable, and I would take the project in a different direction by attempting to make it as accessible to the lay person as possible, and focussing on the open source aspect. I worked with Jeremy (who is my supervisor) to figure out what I'll be trying to do in a bit more detail. Jeremy then summarised this in 'Project Brief' documents (one for each of Alex and myself) and gave us the chance to make any changes. We all seemed to be on the same page, because neither of us needed to edit the proposed briefs. I have uploaded it here. This will be very helpful when writing the work packages and aims of the PSP.

## Wednesday 13th November (retro)
### Third FYP Meeting
This meeting was mostly spent discussing the logistics of open source hardware.

open source:
- allow future FYP students (and anyone else) to understand and continue work
- official definition is that there should be sufficient documentation and access to editable files that anyone should be able to:
  - make
  - study
  - develop
  - distribute
- you could almost say there are two products/outcomes, the bike kit and the documentation
- use of GitHub for version control, documentation, and sharing
  - could use markdown directly for project log
  - or, could keep uploading new versions of a word document so it's easier to write the report
- Design log?
- Instruction booklet?
  - photographic documentation of assembly process?
  - technical drawings?
  - research best practice
- The developement and design decisions need to be documented as well as the final product
- both raw and viewable CAD files should be uploaded to GitHub

## Writing the Project Scoping and Planning Report (retro)
The final PSP Report and the feedback for it will be uploaded here.
### To Do List
- Prep:
  - [x] read assignment brief, especially mark scheme
  - [x] create plan of action
  - [x] read example PSPs
- Scoping:
  - [x] go over project briedf and meeting minutes
  - [x] draft aims and objectives
  - [x] draft Work Plan including deliverables and prototypes
  - [x] draft introduction and background
- Planning
  - [x] lay out deliverable timescale
  - [x] assess time needed for each project phase
  - [x] draft overall timescale
  - [x] carry out contingency planning i.e. in case Phase 1 fails, what will Phase 2 be?
- Lit Review
  - [x] decide what to cover
  - [x] compile resources
  - [x] read them!
  - [x] draft lit review
- Report
  - [x] revise drafts
  - [x] summary
  - [x] references
- Misc.
  - [x] title page
  - [x] check figure references all match up correctly
  - [x] fill out the risk assessment
  - [x] hand-ins (paper and moodle)

### Aims and Objectives (draft)
#### Overarching Aim
Design a kit with which a lay person can easily and non-destrucively assemble a bicycle with a geometry of their choosing, ensuring that the ratio of off-the-shelf parts to custom parts is as high as possible in the interest of accessibility to the lay person.
#### Objectives
1) Investigate available off-the-shelf technologies and recommend which would be the most suitable to include in the kit as the tubes, joints, and interfaces of the bicycle frame. based on a set of criteria.
1) Develop a simplified modelling mechanism to test combinations of the recommended components and use it to:
   1) Demonstrate the feasability of creating different geometries
   1) Make a recommendation on which lengths, angles, and quantities to include in the kit
1) Source the components and build a physical prototype of one or more of the geometries
1) Document the kit thoroughly so that any lay person is able to replicate the design

### Literature Review
- Jamie's Report
- Different solutions to similar problems
- Geometries, components, and Engineering of bicycles
- Consumer behaviour regarding customisable products
- Open source philosophy and licensing
- Assembly instructions best practice

## Monday 3rd February
### Julian House Bike Workshop
Julian House Bike Workshop is a charitable enterprise in Bath which accepts donated bikes, fixes them up, and sells them, using the profits to help the homeless community. They also provide training and employment for homeless people, and run workshops where members of the public can learn how to maintain their own bikes.

Before I start building a wacky DIY bike, I'll need to know where I'm starting from. I will also need a good understanding of the various ways in which the other components attach to and interface with the frame, so that I can design the frame accordingly. To these ends, I paid them a visit. The gentleman working there was very helpful and told me to pop back anytime. Here is a rough summary of what I found out:

* To maybe visit/contact:
  * There is a DIY bike show called [Bespoked](http://www.bespoked.cc/) which is awesome and would be worth a visit, even though it's in May. It's also in Bristol though, which is good, because it could have been anywhere in Europe.
  * The Bicycle Academy in Frome has various courses to teach people how to build a bike frame from scratch (by welding). They can be a bit expensive, though. They also make and sell their own jigs, which are often cheaper than alternatives.
  * Julian House has truckloads of scrap bikes that I could have for free and take apart, cut up, or canabalise for parts. They're also always happy to answer questions about bike contruction and maintenance.
* To look into:
  * Bike fitting jigs are contraptions designed to have a totally adjustable geometry (wheelbase, rake, etc.) to allow riders to find a geometry suitable for them.
  * Folding bikes such as the [Fubifixie](https://fubifixie.com/) and [split frame](https://splitbikes.com/products/split-frame-kit) [bikes](https://splitbikes.com/products/split-frame-kit), which have a threaded tube joining the two halves of the top tube together
  * DIY fork or outsource fork?
* To know:
  * The head tube and bottom bracket are usually mass produced and bought in
  * The seatpost comes in lots of different sizes to fit the seat tube. Tolerances are important
  * Dropouts are usually made to order as they are so specific and tightly toleranced
  * Chain line/alignment should be considered
  * Distance between dropouts is important. Needs to fit gears (if applicable) and wheel
  * For fixies, the chain tension needs to be set correctly. The back wheel is on sliders and can be clamped in place with a threaded nut. Freewheel mechanism?
  * Every bike has a geometry sheet with key distances and angles
  
  Bike frame anatomy, for reference:  
bike frame anatomy

### Other
- [ ] email Jeremy and Alex to setup meeting
- [ ] message people about setting up regular breakfast meetups for structure and accountability
- [x] start project log
- [x] go talk to Julian House
- [ ] assign new timescale to tasklist from PSP, and plan this week in more detail

## Tuesday 4th February
- [x] Set up Breakfast Club
- [ ] Email Alex and Jeremy to set up meeting
- [ ] Assign new timescale
- [ ] Update Project Log

Didn't get much done today. Struggling with stucture and knowing where to start. Hopefully the breakfast club and planning will help with that.

## Wednesday 5th February
- [x] Research mechanical design synthesis and plan how to develop criteria
- [x] Got in touch with Alex RE meeting, and he's already emailed Jeremy
- [x] Assigned new timescale to tasklist and uploaded here
- [ ] Upload and type up backlog of meeting minutes, reports, etc, to GitHub (started)
- [x] Figure out a system for weekly planning and plan next week
- [x] Update Project Log for yesterday
- [x] Update Project Log for today
- [ ] Emails
- [x] Read through presentation from Monday

- I will plan each week on a paper calendar to allow for easy adjustment. Initially I will just print these out, but I'll try to buy a pad them when I see one.
- With regards to researching mechanical design synthesis, the following books were consulted:
  - MECHANICAL DESIGN SYNTHESIS by RC Johnson
  - MECHANICAL DESIGN by Peter RN Childs
  - SHIGLEY'S MECHANICAL ENGINEERING DESIGN by Joseph Edward Shigley et. al
  - ENGINEERING DESIGN METHODS by Nigel Cross
  - ENGINEERING DESIGN: THE CONCEPTUAL STAGE by MJ French
- The volume by Nigel Cross was selected to be used as reference moving forward as it is the most relevant, easy to understand, and has good worked examples. The methods described are also familiar from 2nd year design, so it is likely the same book the lecturer referenced.
- The process of designing criteria for evaluating the technologies will be:
  - product design specification (fig 40, page 83)
  - 'house of quality'/interaction matrix, optional (fig 44 page 99, fig 45 page 100, fig 48 page 103)
  - morph chart (fig 50, 51 page 111)
  - initial concepts from morph chart
  - weighted objectives to evaluate initial concepts
  - choose or design final concept, and sketch
  
## Thursday 6th February
Captain's log: Phew! This log is finally up to date! That took so much longer than I expected! Now I'm behind on the design synthesis.

- [x] Retroactively type up meeting minutes, etc. from before this project log was sterted
- [x] Today's log entry
- [ ] Product Specification
- [ ] Interaction matrix?
- [ ] Morphological Chart
- [ ] Initial Concepts
- [ ] Weighted Objectives / Pugh Matrix
- [ ] Final Concept
- [ ] Criteria

Maybe I'm trying to do too much in one day with all this conceptual design stuff. It's probably going to form a significant portion of the report after all. But I want to leave plenty of time for prototyping and developing things. Well, I'll see how I get on tomorrow and then update the timescale. I'm tempted to stay late and at least get the Spec done but it's already almost 1900 and I have a lot of Life Admin to do. Tomorrow, then. 

Rosen out.

## Friday 7th February

- [ ] Product Specification
  - [x] Brush up with the textbook
  - [x] Consider Levels of generality
  - [x] Determine level of generality at which to operate
  - [x] Brainstorm requirements
  - [ ] Quantify requirements
  - [ ] Lay out in a table with demand/wish weights
- [x] Update log

The challenge with creating a product specification is that it must be specific enough to sufficiently restrict and evaluate the design, but general enough that it does not exclude potential solutions. For example, both the [Wishbone Design 3-in-1 Balance Bike](https://www.kidly.co.uk/products/wishbone-design-studio/3-in-1-balance-bike/8080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) (top row below) and the [Infento Explorer Kit](https://www.infentorides.com/product/explorer-kit/) (bottom row below) could arguably fullfill the same brief and product specification, just in very different ways. The product specification would not be able to specify material, fixing mechanisms, or even the general structure, as the balance bike uses curved wooden panels bolted together, while the infento kit uses aluminium 'rod' elements connected with moulded plastic joints.

[BalBike1]: https://kidlycatalogue.blob.core.windows.net/products/8080/product-images/neutral-wooden-1/wishbone-design-studio-3-in-1-balance-bike-neutral-wooden-1920x760_03.jpg "Balance Bike 1"

[BalBike2]: https://kidlycatalogue.blob.core.windows.net/products/8080/product-images/neutral-wooden-1/wishbone-design-studio-3-in-1-balance-bike-neutral-wooden-1920x760_04.jpg "Balance Bike 2"

[BalBike3]: https://kidlycatalogue.blob.core.windows.net/products/8080/product-images/neutral-wooden-1/wishbone-design-studio-3-in-1-balance-bike-neutral-wooden-1920x760_02.jpg "Balance Bike 3"

[Infento1]: https://www.infentorides.com/wp-content/uploads/2018/10/InfentoBALANCER-G2-PrspFront-690x460.png "Infento 1"

[Infento2]: https://www.infentorides.com/wp-content/uploads/2018/10/infentoSTREAMER-PrspFront-690x460.png "Infento 2"

[Infento3]: https://www.infentorides.com/wp-content/uploads/2018/10/infentoRIDER-G2-PrspFront-690x460.png "Infento 3"

   |   |
:--------------:|:--------------:|:---------------:
   |   |

I've decided it's worth taking the extra time to do this thoroughly. It's all based on legitimate engineering principles which I can write up in my report, and it'll help avoid walking into the trap of just assuming the first idea is the best idea. Who knows, I might find some new ways of doing things. And if I don't at least the first idea will be fleshed out and justified. 

It should be noted that, because of the nature of the product, it can be difficult to separate the requirements for the kit itself from the requirements of the bike assembly and other assemblies. To address this, a set of requirements will be determined for the bike assembly, and these will be 'translated' into kit requirements. The geometries of the other assemblies are not yet known, so there will be a kit requirements that at least two geometries must be possible. Unless otherwise specified, mentions of requirements, specifications, and the like are referring to those of the kit and not the assemblies thereof. 

The levels of generality were considered, and are summarised in the table below:

level of generality    | examples
-----------------------|----------------------------------------------------------------------------------------------------------------------------------------------------------------------------------------------------------
product alternatives   | **bicycle/tricycle kit**; skateboard/rollerskate kit; welded bicyle frame with bolt-on cargo carrier, child seat, tandem attachment, sidecar, trailer, and training wheels
pruduct types          | to be manufactured and sold by distributor; **to be built by the consumer with simple manufacturing and readily available parts**; consisting of panels; **consisting of linear elements and connectors**
product features       | materials; type of linear elements; type of connectors, lengths, angles, and quantities to include in kit; type of wheels, brakes, drive, etc.; method of attaching wheels, brakes, drive, etc.

We already know which product alternative and product type we want (shown in bold). The 'linear elements' structure was selected because it would give a greater degree of flexibility for the wide range of geometries that we are aiming for, and allow for greater creativity while the user is assembling the kit, more akin to lego or meccano than flatpack furniture. Hence, the design synthesis will take place at the 'product features' level.

The requirements for the bike and then the kit were brainstormed. The resulting mindmaps are shown below:
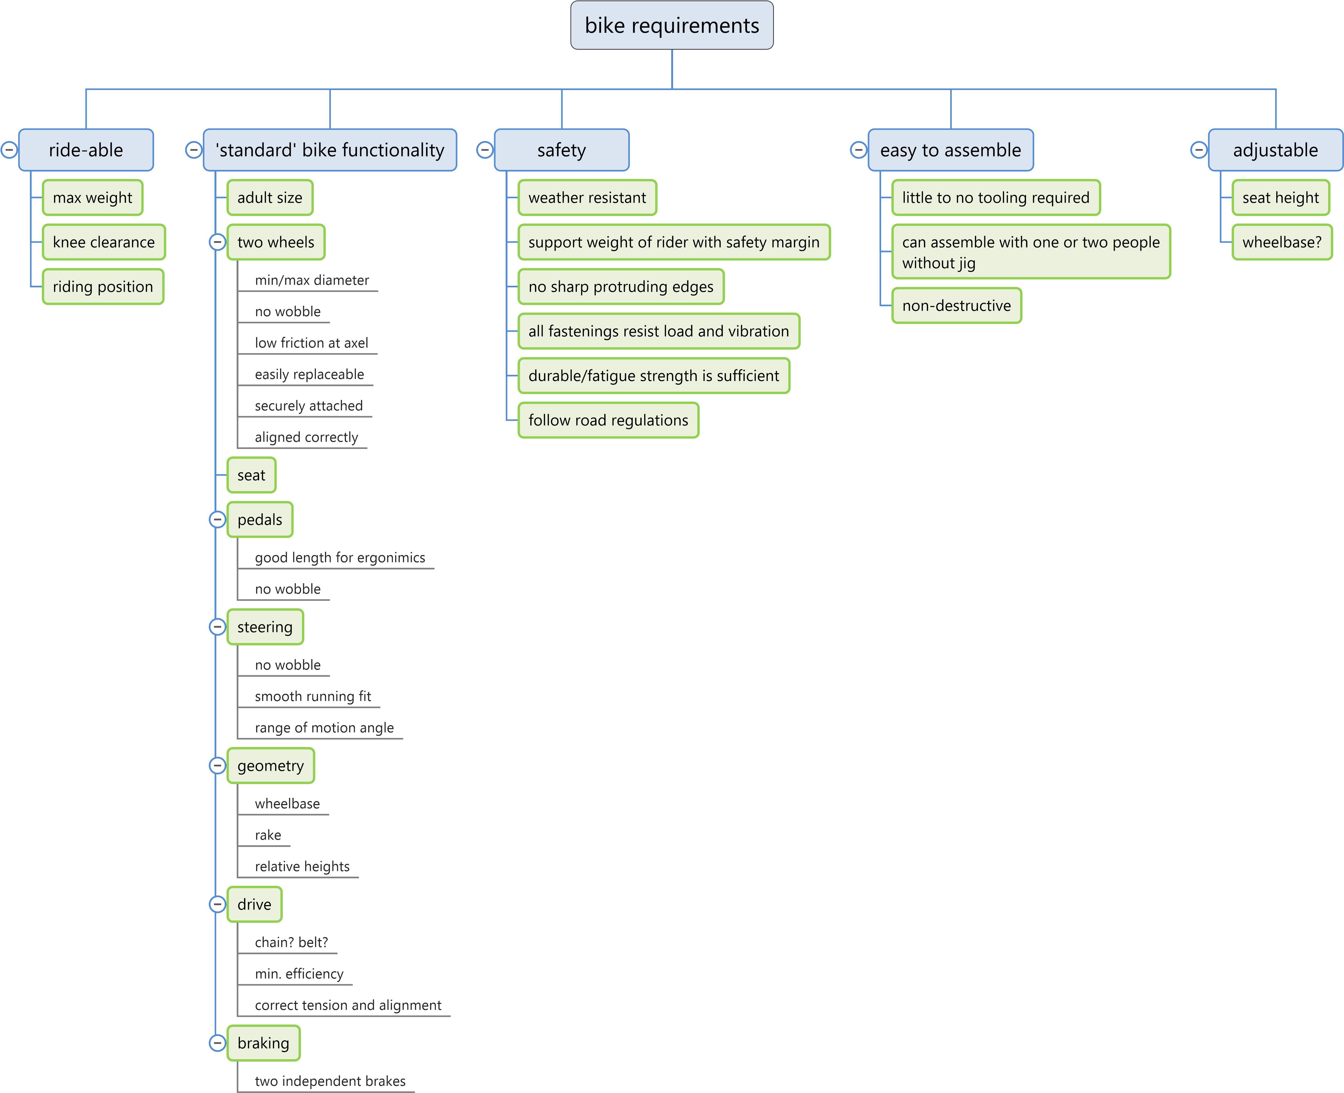
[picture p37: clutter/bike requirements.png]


The bike requirements were fed into the kit requirements.

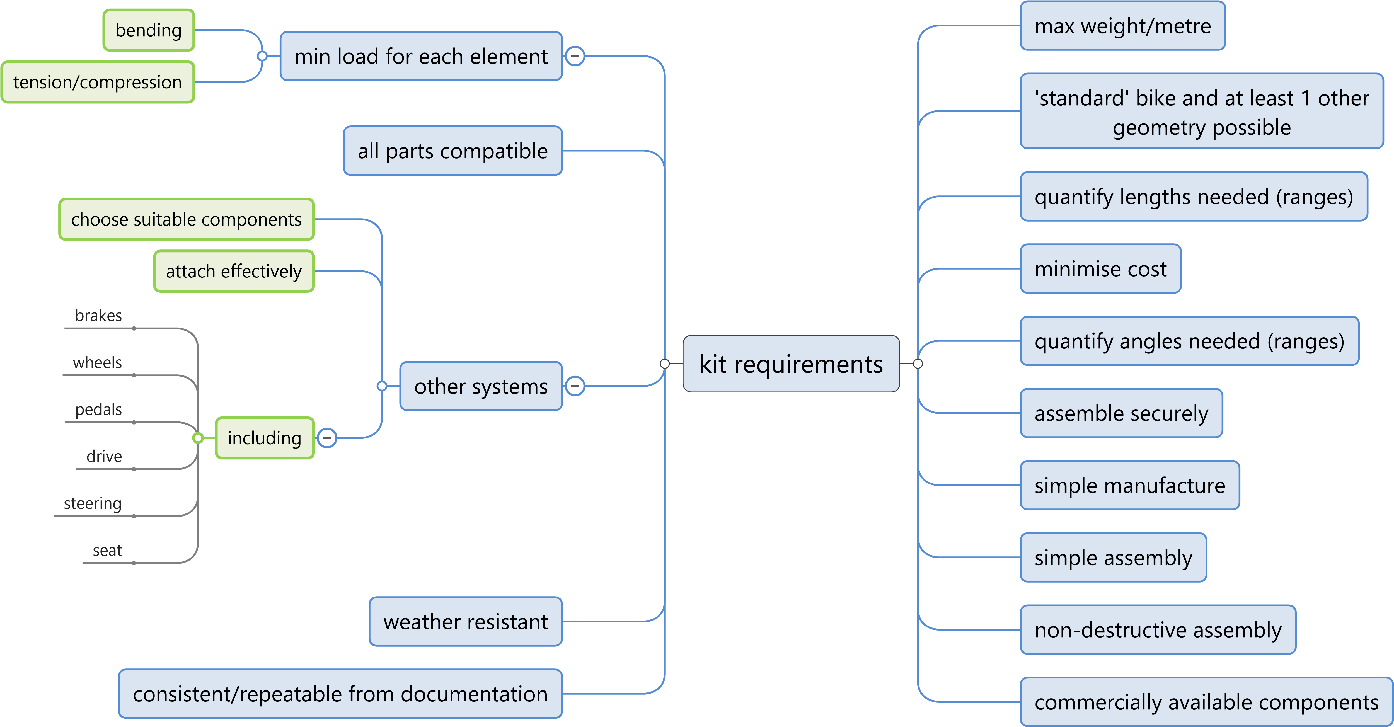
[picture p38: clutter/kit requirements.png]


## Monday 10th February
- [x] Update Friday's log in more detail
  - [x] type up decisions and findings
  - [x] type up mindmaps with mindgenius
  - [x] upload and insert into log
- [x] Email RE meeting tomorrow
- [ ] Product Specification
  - [ ] Quantify requirements
    - [ ] bike
    - [ ] kit
  - [ ] Lay out in a table with demand/wish weights
    - [x] bike
    - [ ] kit
- [x] Collate a list of technologies already identified as candidates
- [ ] If time - morphological chart?
- [x] Update today's log

note: this article on [Geometry Charts](https://www.bikeexchange.co.uk/blog/bike-geometry-charts) is coming in handy when trying to quantify the requirements for the bike. I'm aiming for a sort of hybrid commuter style geometry, nothing too aggressive.

other links:

https://bike.bikegremlin.com/832/bicycle-frame-geometry/

https://www.boardmanbikes.com/gb_en/products/2256-slr-9.2.html

https://www.boardmanbikes.com/gb_en/products/2171-mtx-8.8.html

https://www.boardmanbikes.com/gb_en/products/2232-adv-9.0.html

https://www.cyclingweekly.com/group-tests/road-bike-geometry-explained-407599

the image and table below are taken from Jamie's report:
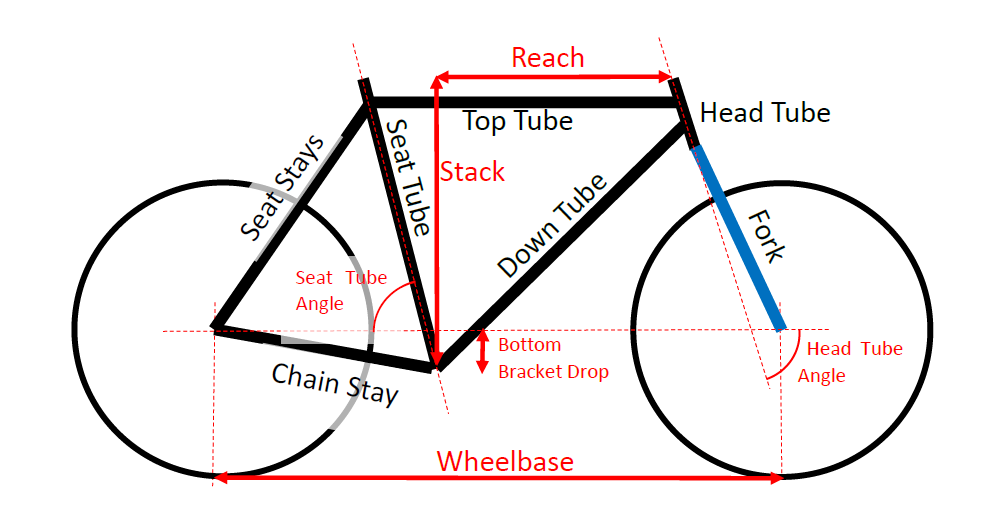
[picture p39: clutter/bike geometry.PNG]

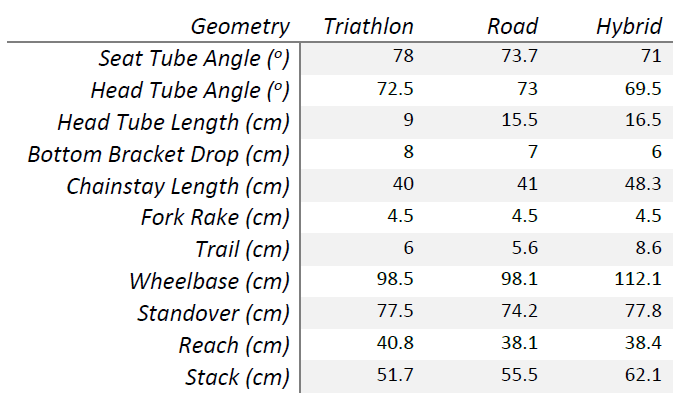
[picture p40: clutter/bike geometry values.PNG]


A list of some possible candidates was collated and uploaded [here](https://github.com/hannahrosen57/AdjustaBike-2.0/blob/master/clutter/possible%20components/component%20candidates.xlsx). The bike requirements were organised into a table and uploaded [here](https://github.com/hannahrosen57/AdjustaBike-2.0/blob/master/clutter/Product%20Specs.xlsx). 

## Tuesday 11th February

- [ ] Product Specification
  - [ ] Quantify requirements
    - [ ] bike
    - [ ] kit
  - [X] Lay out in a table with demand/wish weights
    - [X] kit
- [ ] If time - morphological chart?
- [x] Supervisor meeting
- [x] Update log 

I had a Doctor's appointment and some important errands today so I didn't get as much done as usual.

## Wednesday 12th February

- [ ] Product Specification
  - [ ] Quantify requirements
    - [ ] bike
    - [ ] kit
  - [ ] Add RS, bamboo, timber, 3D printing, and anything else I think of to component candidates spreadsheet
  - [ ] Decide on morphological chart categories for bike, ie. wheels, brakes, drive, steering, interface/attachment/bearing mechanisms, links, joints, geometry, adjustment/adaptaion mechanism(s). Refer to Jamie's work, infento, other competitors, etc.
  - [ ] Add Dutch upright bike to weight data
    
### Call from The Tube and Clamp Company
11.46am, I just got off the phone with the tube and clamp company. I had to give them my contact details to download the brochure, and I was in the middle of typing up the mess below (quantifying product spec) when they called me. I was able to ask them some questions which was helpful because they don't have any prices in their brochure and it wasn't clear if it was possible to order small quantities or if it was exclusively geared towards big industrial applications. I'll type up the key points below. This is sounding pretty feasible, all in all. 

It sounds like 4m of aluminium profile would be roughly £20 and joints (which consist of two clamps bolted together) would be about £1.50 each. The tubes come in 4m lengths and they can cut them to size for 50p/cut. They have a big warehouse in France where they ship bulk orders from, but since it's a small scale project they would probably ship it from their stock in the UK. They have a courier type deal set up for the 4m tubes, but it's easier and cheaper if they're cut to length first. The joints are shipped seperately in a normal box. Lead time from knowing what parts I need until they arrive here would be about 5 to 7 days. I forgot to ask about shipping costs, maybe I'll email him to ask. Edit: he said in his email that I could expect to pay £20-30 in shipping for such small quantities.

He said the company isn't usually too keen on giving out their CAD files, despite being asked about that a lot. I said I totally understood the need to protect IP and that I could probably mock up some simplified versions to figure out which parts I need. However, he seemed to be pretty keen for me to send him a sketch or simple CAD drawing of a concept, with any other important info like the forces involved, and they could put together a SolidWorks assembly from their part files and send me the Bill of Materials and presumably assembly drawings. This service would be free of charge. This would be useful because they know their product best and can find a good combination of components, weight optimised, cost optimised, taking account of loads it needs to withstand, etc. 

#### We now interrupt your regularly scheduled programming for a brief descent into madness.
Two concerns: a) is that cheating? and b) the same parts need to be used to build multiple assemblies, and unlike timber or scaffolding tubes, it doesn't make sense to just chop a bit off the end or buy a new tube when you need to build something new with different length tubes. Unless I just buy extra as spare? So, I would likely need to iterate geometry/assembly designs until I'm happy with at least a couple, trying to make sure they share as many parts as possible, and then send them two or three different concepts. Or, get them on board with the kit concept early on and use their expertise in the decision process, with the risk that I might not choose to take their product forward as the final concept. Again, is that cheating? The guy I spoke to said he'd email me so I can contact him when I've nailed down my concept a bit more, and I also asked him to type up a brief summary of everything we'd discussed. I thought I'd also type this up before I forget anything. 

Also, a major design consideration is whether joints allow adjustable length without cutting the tubes, and if that makes the transverse bulky if they need to be side by side rather than inline. Can we use angular adjustment to adjust the length by 'folding' links in the middle? Or telescope? Or design the geometries so they mostly use the same lengths and adjust with a different mechanism? Is it possible to predict that different lengths will not be needed for geometries that have not been designed yet? Can enough flexibility be possible just by working around set lengths? It works for lego and meccano, if you think about it they're not very adjustable, they just have discrete sizes of building blocks which can be combined. But they're not dealing with trigonometry. But, the bike frame doesn't necessarily need to look like the standard 'triangle' shape. It could be like a brompton bike, relying on cantilevers. That would make getting the right lengths easier, but would the bolt-together joints be strong enough for a cantilever? Will the extra bending strength necessry in the links make it unneccesarily heavy? Will relying on discrete building blocks mean that a large quantity of components are needed, many of which aren't used at a given time? That would defeat the purpose of trying to reduce cost and storage space. It might be possible to adjust the 'discrete' lengths to match your height and only order those exact 'building blocks'. But then there's the original problem of needing different exact lengths when you decide to build a tricycle. And then is it truly a flexible kit? Or just a DIY project? If you have to order new parts for each different geometry I don't think it fulfills the project brief. 

Ahh these are all things which I'll try to decide with my morphological chart after I sort the project spec, but they're all interconnected and it's hard to separate them because I feel like the choice of technology/product/component will influence which features would work best, but the required features also influennce which technology would work best. Plus, maybe a combination of different technologies would work best! That adds tonnes of different variables! Not to mention all the different combinations of wheels, steering, etc, and their attachment mechanisms! How do I solve this when it's so motherforking recursive and complex? 



Okay. It's gonna be okay. We have a system to work through this mess. It's not perfect, and I might have to iterate a few times, and maybe I'll miss things and I won't find the best solution. But maybe there isn's a best solution. But we'll probably end up with a good solution. Maybe there will be another way I could have done it, but that's pretty much always the case. I'm on the right track, I'm trying to make this messy process a bit more methodical. I just have to keep going and cross each bridge when I come to it. And hey, maybe certain design decisions don't need to be completely justified, because exploring every single possible option would be impossible. It's more important that I get something that works. Just start with something. Whoever's working on this next can improve on it. So use the tables and matrices and charts as far as is helpful, and justify the foundation and the broad strokes and use it to find options. And then just - give it a go. Use intuition about how best to attach the wheels or whatever. Make it work, and if it doesn't work, come back to all the other options you left on the drawing board. 

Maybe it won't be best, ideal solution. But it'll be something. Probably a pretty good something. Who knows, it might actually work. We can improve it later, or someone else can. That's not even cheating, that's what the design process is supposed to be. It's iterative. That's half the point of making this open source, so someone can look at this and see what happens if you try it a different way. It's not like I'm gonna make design decisions completely arbitrarily, I'll have some justification. Even if it's just time constraints - sometimes you have three equally good options and you just have to pick one and try it. I mean think about how many variations on a theme there are on the market right now. There's more than one way to skin a bicycle. Okay. It's gonna be okay. You're thinking far too much about this, get a freaking grip.

**actual useful thought:** I was going to go through the whole design synthesis process and then, once I had the final concept, try and source components to build it. This is the usual way of doing things with a normal design project. But, with this one, the design is really built around and influenced by the components that I'll be using. So, I think it makes more sense to (after finishing the product specs) research the possible technology candidates, in the broad strokes since there are so many different product lines within each company, write some notes on them, including some of the more tangible, simple requirements like weight per metre, and then base the morphologocal chart on these different technologies. Then I can filter out the duds and build and evaluate initial concepts around the components which are available (ie. 'steel scaffolding tubes to fit interclamp' and 'aluminium graphit tubes from the tube and clamp company' instead of just 'tubes' as options in the 'links' category), and combine them if beneficial, possible, and worthwhile. I can iterate if I need to by redesigning the final concept and reeveluating it until I'm happy. But at least then I can use the things I already know about the technologies/components to inform the design decisions at the concept stage. Yeah, I'm a lot happier with that process. It'll involve a bit of digging around and emailing people, since cost and info etc. isn't always readily available, but I think it'll work. See? good talk. Not a complete waste of time.

### Quantifying Product Spec Requirements
I'm feeling a bit intimidated and overwhelmed by the task of trying to quantify the requirements for the specification. I think it's because it involves a lot of interdependent steps, fact-finding, assumptions, decisions, and calculations, and because there isn't necessarily a 'right answer' or a way to check if I've done it right. And because I feel like this should be a simple task and I should have finished it already. But, to be fair, this is probably going to involve some back-of-the envelope FEA and writing up a long-winded decision process involving calculations, both of which take time, and this is the foundation for everything that I'll do later.  So, step 1, accept that this is going to take time and that's okay. Step 2, break it down. Acknowledge that a lot of assumptions will need to be made in order to calculate things, and that's okay as long as I use good margins and safety factors to find a reasonable 'worst case' design limit. It's okay if this needs to be adapted later when I have more information.

Okay, let's try to break this down a bit:
- [x] Try to find some better data on 'stack' and 'reach' for hybrid geometries, as the only example I've found that lists these quantities is giving me very strange numbers - reach values around 600mm rather than the 380mm-ish which is predicted by Jamie's report and by comparing the proportions to road bikes. In theory I could just use the road bike data, but this is not going to be a lightweight or high performance machine, so it needs to have a fairly upright riding position to be accessible as a commuter type bike.
- [x] Use hybrid geometry data to fill in stack and reach requirement ranges
- [x] Use hybrid geometry data to define a preliminary geometry for force calculation purposes. As the size of bike chosen is fairly arbitrary, choose one which would fit me. 
- [ ] Record and diagram this somehow. Simplify if necessary.
- [ ] Resaerch standards, test procedures, and safety factors for commercial bikes. To find out:
  - [ ] Weight of 'test rider'
  - [ ] Which tests does it need to pass? Static load, definitely. Shock load? Drop test? How high? How heavy? Resonant vibrations? (Probably not, at least not now, as that would require actual FEA on a computer and that's a but too in depth at this stage, but still should be noted for later.) Fatigue strength? How many cycles? 10,000? Should I model it with all the force on the bottom bracket or the seat? Both at once? Both, one at a time? Assuming that the 'test weight' is much higher than an average rider's weight, what safety factor should I use for the test weight?
  - [ ] Use the findings to fill in the relevant requirements for the bike spec (add safety factor requirement? adapt to reflect real life testing standards? Don't forget fatigue strength requirement).
  
We need to translate the bike requirements into the kit requirements. This means that we need to analyse a preliminary geometry to find the forces in the links and joints. 

- [ ] Model the bike frame as a pin-jointed structure and calculate link and joint forces. Note, we do not know the cross-sectional area or the material of the links yet, so do not try to calculate stress. We just need the forces.
  - [ ] Simplify the geometry into a 2D model. The main difference will be that the two chain stays and the two seat stays either side of the wheel will each need to be modeled by one link in the X-Y plane.
  - [ ] Decide if the fork needs to be modelled. If yes, decide on the 2D geometry. Tricky to model with pin-jointed structure. Model as constraint at a head tube joint, and then model fork seperately as a beam? 
  - [ ] On paper, diagram the bike frame as links and joints, and annotate with angles and lengths.
  - [ ] Decide on how many tests are needed. For each one, define the magnitude and direction of each load, and where on the frame they act. This may involve calculating forces using equations of motion or other methods.
  - [ ] Define the constraints.
  - [ ] Check if the structure is statically determinate. If not, adjust constraints and/or loads as necessary until it is statically determinate. Note that some unrealistic constraints might be necessary in order to solve the structure, and this is okay because we just need a good estimate. Make note of them though.
  - [ ] Draw the diagrams and solve for all the link forces for each test case, on paper.
  - [ ] Check/verify them somehow. This could be with an online tool or simplified CAD (in which case, screenshot the diagrams for the report) or just by re-doing the calculation (which might actually be quicker).
  - [ ] Decide on a suitable safety factor and calculate the design forces.
  - [ ] Decide on the level of generality at which to specify loads. On the one hand, we don't know what the final geometry will look like (it could be significantly different), and so we should give a minimum load bearing requirement that every link and joint need to meet based on the 'worst case' and safety factors. On the other hand,  
  - [ ] Use the results to fill in the 'link tension/compression' and 'joint gripping force'
- [ ] Up till now we've been treating the frame as a pin jointed structure. While some of the joints might end up being pin-jointed, some will probably be fixed, as if they were welded (except not actually welded, because I doubt Mr. Joe Everyman wants to rent a welder). We need to estimate the maximum moment on the joints, and the bending moment on the links.
  - [ ] Think about the realistic constraints that the frame will be under during testing and use. 
  - [ ] Think about which joints should be fixed. This could be all of them or none of them , depending on the design, but probably somewhere in between. Could have a couple different options.
  - [ ] Based on the pin-jointed analysis, constraints and loads, choice of fixed joints, geometry of structure, and intuition, estimate which joints will be subject to the highest torques and which links will be subjected to the highest bending moments for each test case. Do some simple calculations if necessary. Might need to make assumptions or simplify the model.
  - [ ] For each test case, model and calculate an estimate of the worst case joint torque.
  - [ ] For each test case, model and calculate an estimate of the worst case link bending moment.
  - [ ] Determine a suitable safety factor and calculate design moments.
  - [ ] Decide level of generality with which to specify the moment requirements. We don't want to overengineer smaller joints, but different geometries will have different forces and the joints have to work for all of them. Also consider that this is a ballpark 'envelope' for this specific requirement, and that there are seperate requirements for 'kit can be used to build a bike' and 'bike must support xxx kN' and ' optimise weight and cost', and that further testing will be carried out later to make sure the design is fit for purpose. We don't want to tie the design down too tightly at this stage. But, we do want to rule out things that definitely won't work so we don't have to redesign everything later.
  - [ ] Use the results to fill in the 'joint torque' and 'link bending moment' requirements.
- [ ] TYPE ALL THAT UP including diagrams and calculations!
  
Okay, that should be all the force calculations we need. Moving on.

- [ ] Do some maket research to get an idea of cost. Note we will probably not sell this, but cost is still a factor in DIY. We have an advantage in that we don't need a profit margin and don't really have any overheads, but a disadvantage in that we can't buy in bulk. Also, should we assign a cost to manufacturing and assembly time?
  - [ ] ~~Compile a list of competitors or similar products (could be more than one product from each company)~~
    ~~- toy kits ie infento~~
    ~~- cargo bike kits ie XYZ~~
    ~~- purpose-built cargo bikes, adult trikes, child-carrying bikes, tandem attachments, etc.~~
  - [ ] ~~Research and record the prices of each of them~~
  - [ ] ~~Come up with some desirable attributes like 'build quality' and 'flexibility' and give them preliminary weights based on how much the consumer values them~~
  - [ ] ~~Rate each of the competing products in each of these attributes~~
  - [ ] ~~Compute an overall 'value index' for each competing product using the attribute scores and weights~~
  - [ ] ~~Plot the cost against the value of each of the competing products on a scatter chart and show the line of best fit~~
  - [ ] ~~Adjust the weightings (and add more attributes if there are any missing) until the scatter graph shows a good correlation. Sometimes, the line of best fit is linear on a log plot when all the weights are adjusted correctly. Sometimes.~~
  - [ ] ~~Score our product on each of the attributes and calculate its value index. Use the line of best fit on the value-cost graph to find the target price for that value index.~~

Actually, scratch all of that. Just find a couple similar products on the market think about how much you'd be willing to pay for it, pick a fairly large fudge factor, and get a ballpark absolute maximum and target price. When you know what the design looks like in more detail, come back to the procedure layed out above and use it to evaluate and justify. I'll leave it here to refer to later. 

- [ ] Fill in the ballpark cost requirements

The rest of the requirements are less involved. Do some simple research and/or calculations. Don't get too bogged down in the details.
- [ ] Stopping distance
- [ ] Acceptable levels of torque due to friction in wheel, bottom bracket, and headtube bearings
- [ ] Range of motion in steering
- [ ] Max. manufacture time and assembly time
- [ ] etc.

I'm sure there will be other things but that's all I can think of right now. Argh, it's half two and I haven't eaten any lunch or done anything productive, I just wrote all that ^. Ahhhhhhhh

I found a couple other geometry charts and the numbers make more sense. Also, I went back to the first ones and I must have read the table wrong because it's actually perfectly normal. I recorded all the stack and reach data in the product spec spreadsheet. 6 bikes in total. The force calculations will use the geometry based on that of a size small cannondale quick 4. This was chosen because the style of geometry is similar to the one I am aiming for, and in theory this size would fit me. The relevant geometry chart data and diagrams is in the product spec spreadheet. The data was used to fill in requirements 4 through 8 of the bike requirements. The table above was used to give context by comparing with different types of bikes. I will upload the updated spec here.

## Thursday 13/02/2020

- [x] Record and diagram preliminary geometry. Simplify if necessary.
- [ ] Resaerch standards, test procedures, and safety factors for commercial bikes. To find out:
  - [ ] Weight of 'test rider'
  - [ ] Which tests does it need to pass? Static load, definitely. Shock load? Drop test? How high? How heavy? Resonant vibrations? (Probably not, at least not now, as that would require actual FEA on a computer and that's a but too in depth at this stage, but still should be noted for later.) Fatigue strength? How many cycles? 10,000? Should I model it with all the force on the bottom bracket or the seat? Both at once? Both, one at a time? Assuming that the 'test weight' is much higher than an average rider's weight, what safety factor should I use for the test weight?
  - [ ] Use the findings to fill in the relevant requirements for the bike spec (add safety factor requirement? adapt to reflect real life testing standards? Don't forget fatigue strength requirement).
- [x] Update  log

I've found some great information on test prcedures from the ISO 4210 standard! But it's going to take a while to wade through it all, and it has important info on the other systems as well. So I won't tick it off yet. More detail below. As for safety factors, there's always this old rule of thumb [[source]](https://www.engineeringtoolbox.com/factors-safety-fos-d_1624.html):

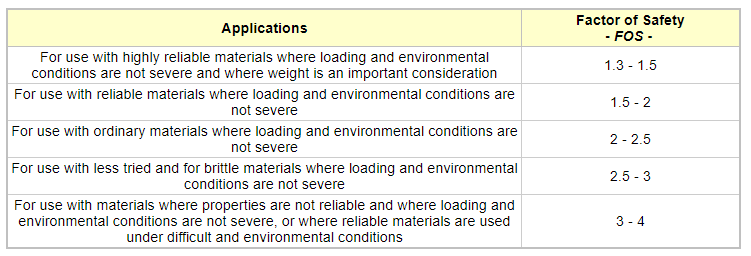
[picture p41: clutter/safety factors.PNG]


So I'm thinking maybe 2ish? The test procedures are pretty rigorous, and I don't want it to be too heavy. But I also need to give people peace of mind that it's not going to fall apart even though it's not welded. Technically one would be trusting one's life to this thing. Hmm. Let's say **sf =  2 to 3** for now.

### Defining, drawing, and simplifying preliminary bicycle geometry
I went looking for a CAD programme to draw up the preliminary geometry and happened across all the fikes from Jamie's Adjustabike project. He shared the folder with me on the Fusion 360 cloud thingy. [Here's a link](https://myhub.autodesk360.com/g/all_projects/active) to the webapp.

I thought I'd just draw up a simple diamgram of the preliminary geometry, but this computer doesn't have Inventor. I tried the Fusion 360 webapp but it doesn't allow you to create drawings. After about an hour tearing my hair out wrestling with AutoCAD I think the best bet is to pack up and go find an engineering lab computer and use Inventor. It will probably save me time in the long run because I won't have to transfer the file from AutoCAD to Inventor, which can be complicated. Ugh this was supposed to be a 5 minute job.

Okay I used the geometry chart from the cannondale website to draw up a sketch of the geometry. I then made a separate sketch with simplified geometry which I'll use for the initial pin-jointed-structure force calculations. I had to make a couple changes to make sure it was a structure rather than a linkage (ie not going to flop over), and to make it slightly easier to analyse. I'm okay with that because this is only supposed to be a ballpark figure. I don't even know what the final geometry will look like, it might be totally different. I was originally going to just do the calculations based on something really simple like a pin jointed equilateral triangle, just to get a general idea of the forces, but I figured I might as well use an actual bike geometry since I've got the info already. Probably made life more difficult than it needed to be, it took ages to get all the dimensions dialled in. The geo chart is just rounded up to the nearest mm, and without that extra precision nothing matches up. Oh well, on the up side I've got a bit of a better idea of the kind of precision (or adjustability) I'm going to need when building this thing. And it'll help when deciding which angles of joints I'll need, etc. I'll put some images in below.

*below: geo chart from cannondale website for the quick 4. values shown are for the size small.*

ref| dimension                    | value
---|------------------------------|---------
A  | Seat Tube Length	            | 40cm
B  | Top Tube Length	            | 55.7cm
D  | Head Tube Angle	            | 70.0°
E1 | Seat Tube Angle Effective  	| 73.0°
F  | Standover	                  | 69cm
G  | Head Tube Length	            | 13.4cm
H  | Wheelbase	                  | 105.3cm
I  | Front Center	                | 62.7cm
J  | Chain Stay Length	          | 43.5cm
K  | Bottom Bracket Drop	        | 6.8cm
L  | Estimated BB Height	        | 27.7cm
M  | Fork Rake	                  | 5.5cm
N  | Trail	                      | 6.7cm
O  | Stack	                      | 55.4cm
P  | Reach	                      | 38.8cm

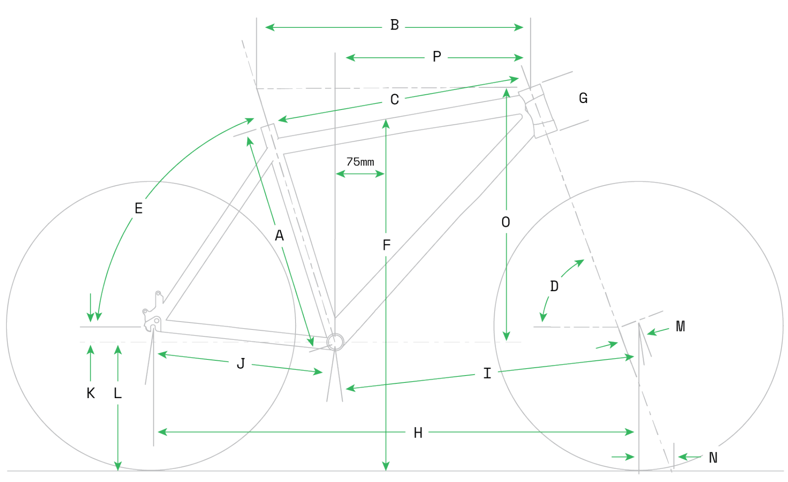
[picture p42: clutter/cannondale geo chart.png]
 |  
----------------------------------------------------------------------------------------------------------------|------------------------------------------------------------------------------------------------------
*above: cannondale geo chart reference diagram*                                                                 | *above: cannondale quick 4*

Click the images below to see them in more detail.

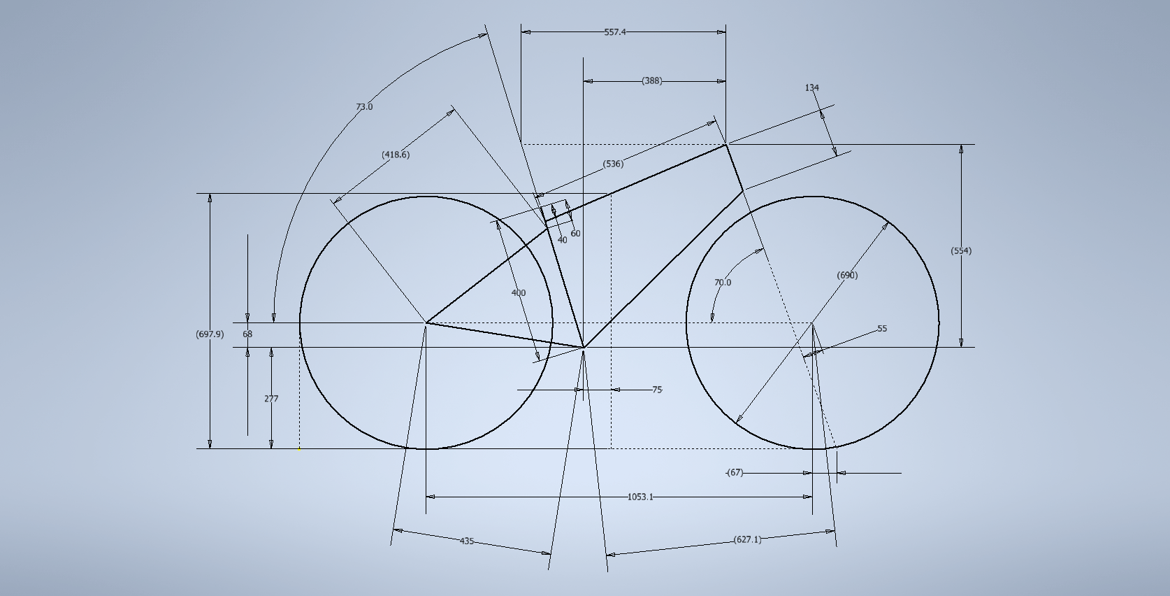
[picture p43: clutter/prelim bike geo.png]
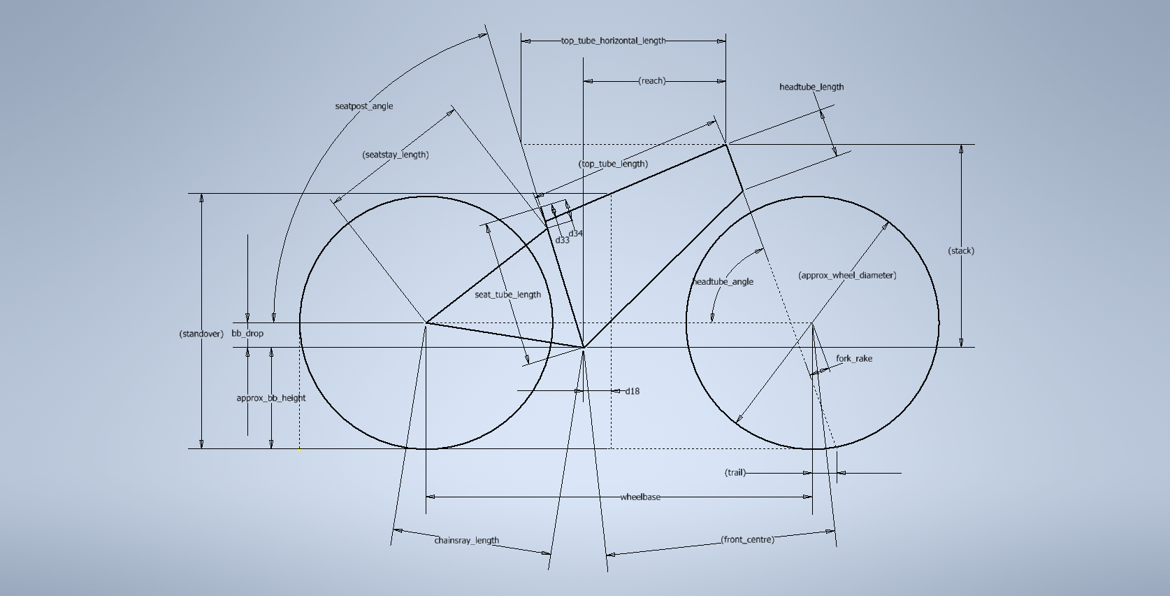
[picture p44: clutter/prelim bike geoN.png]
 | 
-----------------------------------------------------------------------------------------------------------|--------------------------------------------------------------------------------------------------------------
*quick 4 geometry values*                                                                                  | *quick 4 geometry names*
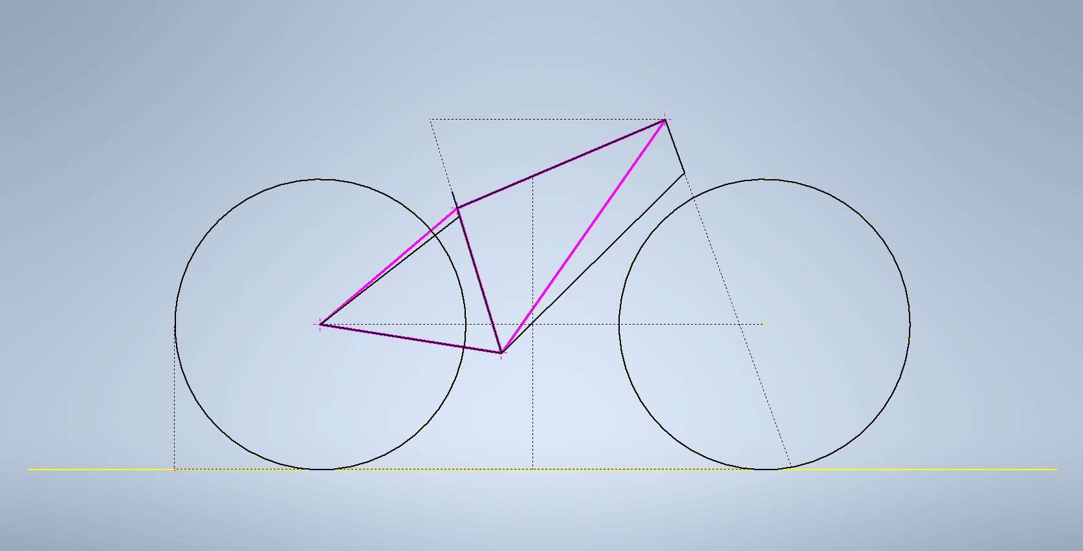
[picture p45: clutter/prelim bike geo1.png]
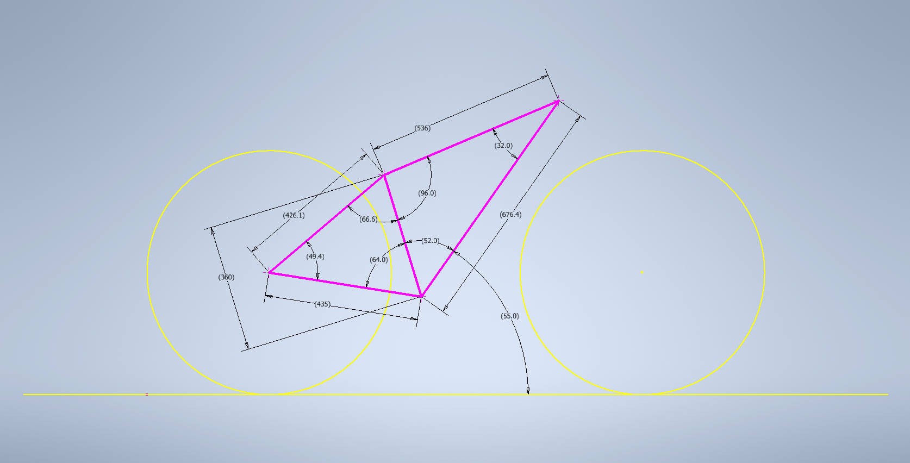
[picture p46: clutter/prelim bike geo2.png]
| 
*quick 4 geometry and simplified geometry superimposed*                                                    | *simplified geometry annotated with dimensions*

### ISO 4210 Cycles — Safety requirements for bicycles
I found a very useful ISO standard on testing procedures for bicycles. I was able to download it for free from the BSOL database with my library login, which is nice, because they're usually pretty expensive. It is divided into 9 parts as follows:

- Part 1: Terms and definitions
- Part 2: Requirements for city and trekking, young adult, mountain and racing bicycles
- Part 3: Common test methods
- Part 4: Braking test methods
- Part 5: Steering test methods
- Part 6: Frame and fork test methods
- Part 7: Wheels and rim test methods
- Part 8: Pedals and drive system test methods
- Part 9: Saddles and seat-post test methods

Parts 1 and 2 say that: 

*"This part of ISO 4210 does not apply to specialized types of bicycle such as delivery bicycles, recumbent
bicycles, tandems, BMX bicycles, and bicycles designed and equipped for use in severe applications such
as sanctioned competition events, stunting, or aerobatic manoeuvres."* 

However, Parts 3 through 9 no not mention this caveat, even though they reference Parts 1 and 2. I think I'm going to have to read through this whole thing and make notes on it. Then I can decide which parts I need to implement in my design spec. I am focussing on the frame, and because this project is geared towards DIY the burden is partly on the consumer, but I think it's still a good idea to read through the sections on braking, steering, etc. It's a pretty lengthy, dry set of documents, and it goes into detail about how to test all kinds of things (ie mudguards, rubber handlebar grips). It'll take some time, and I don't expect I'll put it into practice with as much rigour as a normal bicycle manufacturer, but there might be useful/important things like guideline stopping distances and bending forces used in tests. And it'll be a good way to check if I've missed any major requirments in my spec. I anticipate the sections on 'Frame and Fork Test Methods' and 'Common Test Methods' will be the most useful. I'll upload the PDFs here in the 'clutter' folder.

okay so here's what I did:
- skim through the whole thing
- part 6 seemed the most relevant so I read through that in a bit more detail. There's a lot of helpful info!
- there's a static test, some drop tests, and fatigue testing for the frame. The parameters, procedure, and setup were given but I couldn't see any requirements for passing/failing the test. I found a couple similar standards which did specify the requirements, and then realised the requirements were all in part 2 (duh)
- I made a little plan:
  - [ ] read through the 9 parts. As I go, write down anything relevant to AdjustaBike 2.0, including section refs
    - [x] 1
    - [ ] 2 (started!)
    - [ ] 3
    - [ ] 4
    - [ ] 5
    - [ ] 6
    - [ ] 7
    - [ ] 8
    - [ ] 9
  - [ ] Review notes and decide if I need to add to or adapt the requirements in my product specification for the bike
  - [ ] If necessary, translate these new bike requirements into kit requirements
  - [ ] Quantify all the relevant bike requirements ie steering angle +/- 60 degrees
  - [ ] Quantify kit requirements as planned above
- I read through and took notes on Part 1 and a good chunk of Par 2. this is going to take a while. A lot of detailed, relevant stuff.
- For the drop test, I need a way to approximate the impact force. I could use conservation of momentum, but I don't know how long it'll take to decelerate and the time interval is important. [This article](https://www.wired.com/2014/07/how-do-you-estimate-impact-force/) makes a good point about using a distance instead of a time interval by using the work-energy principle. I can get the maximum distance interval (extension) from the test requirements in ISO 4210. Also, [here's](https://www.youtube.com/watch?v=32k96ahyB2g&feature=emb_title) a video of a wooden bike undergoing the drop test. Could use it to check if the time interval calculated is in the right order of magnitude.

It feels like I've made no progress and I don't know if that's because my expectations are too high or because I'm actually behind and need to hurry up.

To be fair, when I planned this all out I sort of skipped past product specification and conceptual design, and just assumed I would jump straight in the deep and of embodiment and detaildesign, and get a prototype going as soon as possible. I still want to get that prototype going as soon as possible, but when I get the chance I want to rewrite my timescale to put more emphasis on the conceptual stage. If I'm not throurough and rigorous with this part things will go wrong later. Here's hoping the embodiment design won't take as long as this so I can start building the thing! 



## Friday 14th February

Late night last night because I had a bit of momentum going, paying for it today with major inertia. Focussing on taking notes on the standard and then I'll come in on Sunday and try to make some more progress with the spec.

- [ ] read through the 9 parts. As I go, write down anything relevant to AdjustaBike 2.0, including section refs
  - [x] 2 
  - [ ] 3
  - [ ] 4
  - [ ] 5
  - [ ] 6
  - [ ] 7
  - [ ] 8
  - [ ] 9
  
## Tuesday 18th February
  
To do today:  
- [ ] read through the 9 parts. As I go, write down anything relevant to AdjustaBike 2.0, including section refs
  - [x] 3
  - [x] 4
  - [x] 5
  - [x] 6 
  - [x] 7
  - [ ] 8...
  - [x] 9

## Wednesday 19th February

First thing:
- [ ] Finish writing notes on Part 8 of ISO 4210

Next steps:
- [ ] Print and annotate Jamie's Design Specification. Note anything I'd like to add to mine (they'll be a bit different since we're designing different products)
- [ ] Use Jamie's categories as inspiration to add some more structure to my Product Specifications
- [ ] Choose which requirements from ISO 4210 to add to the spec
  - [ ] Could write something like 'frame should comply to ISO 4210; tests may be carried out with FEA if physical tests are impractical'
  - [ ] Still need to analyse forces in order to find the maximum link and joint forces for the kit specification, and for design insight
  - [ ] Could write seperate document summarising estimated forces from tests and the requirements for maximum permissable displacement etc
- [ ] Referring to ISO 4210 notes and Jamie's spec, add and/or rewrite requirements to bike specification, using placeholders for quantities
- [ ] Fill in as many bike spec quantities as possible
- [ ] Continue with force calculations as outlined above

## Monday 24th February
Okay, since I last updated here I've made quite of progress with both the product specification and my plan for the next steps.
- for today:
  - [x] update log
  - [x] emails
    - [x] arrange assessor meeting
  - [x] tie up loose ends with specification
    - [x] fill in quantity gaps
    - [x] demand/wish and weights
    - [x] justifications
  - [x] lecture on presentations
  - [ ] summarise drop tests
  - [ ] type up 'market breakdown' table
  - [ ] type up weight study table
  - [ ] type up cost study table
  - [ ] update/add to 'available technologies' table
  - [ ] start component study
- next steps (this week?):
  - [ ] finish component study
  - [ ] make any MINOR changes to spec if needed
  - [ ] do some ROUGH, QUICK calculations to get cost/weight/angle/length targets
  - [x] lay out kit criteria
  - [ ] find data and score each technology option on criteria
  - [ ] brainstorm categories and options for morphological chart
  - [ ] tabulate and sketch all the morph chart options
  - [ ] choose options for a few initial concepts
  - [ ] sketch them
  - [ ] mini feasibility study for bearing interfaces for each concept
  - [ ] evaluate initial concepts
    - [ ] criteria? weights?
    - [ ] score each concept
  - [ ] define and sketch final concept
#### To do before Wednesday 4th:
(assessor meeting on Weds 4th, then presentation on Fri 6th)
  - [ ] open source hardware case study
  - [ ] improve lit review based on feedback
  - [ ] rewrite timescale
  - [ ] plan presentation
  - [ ] collect all images for presentation
  - [ ] make the presentation
  - [ ] write rough script/talking points
  - [ ] time presentation

## Tuesday 25th February
  - [x] test methods
  - [ ] market breakdown
  - [ ] weight study
  - [ ] cost study
  - [ ] avtech table
  - [ ] start component study

[jump to top](https://github.com/hannahrosen57/AdjustaBike-2.0/blob/master/ProjectLog.md#project-log)

##### {end link}

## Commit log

2020-02-05 updated timescale
    [timescale 2.0.xlsx]
2020-02-05 Uploading backlog of files
    [references.xlsx, timescale 2.0.xlsx, timescale.xlsx]
2020-02-05 updated design synthesis 05/02
    [timescale 2.0.xlsx]
2020-02-05 forgot to save WP2 update
    [timescale 2.0.xlsx]
2020-02-07 uploaded clamp catalog
2020-02-10 bike frame geometry
2020-02-10 component candidates spreadsheet
    [component candidates.xlsx]
2020-02-10 Product Specs
    [Product Specs.xlsx]
2020-02-10 wrong folder!
    [Product Specs.xlsx]
2020-02-10 Product Specs (right folder this time)
    [Product Specs.xlsx]
2020-02-11 typed up kit requirements
    [Product Specs.xlsx]
2020-02-12 geometry data and requirements
    [Product Specs.xlsx]
2020-02-13 preliminary bike geometry files
    [prelim bike geo.ipt]
2020-02-13 update 13/02 stages of design
2020-02-24 specification update 24/02
    [Product Specs.xlsx]
2020-04-22 cad files
    [L10-6.dwg, L10-7.dwg, L114-7.dwg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]
2020-04-29 started CAD modelling
    [10-65.0001.ipt, 10-65.dwg, 10-65.ipt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]
2020-05-04 started fea
    [329-7.0006.ipt, 329-7.ipt, 3upryc280.STL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]
2020-05-13 CAD and report update
    [10-65.0001.ipt, 10-65.0003.ipt, 10-65.ipt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]
2020-05-18 working on report
    [LINK.0023.idw, LINK.0027.idw, LINK.idw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]
2020-05-20 report update
    [LW bike.0151.idw, LW bike.0152.idw, LW bike.idw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]
2020-05-20 update to github
    [LW bike.0149.iam, LW bike.0150.iam, LW bike.iam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]
2020-05-20 minor update
    [bike.0273.iam, bike.0274.iam, bike.iam]
2020-05-22 added a note on tube cutting
